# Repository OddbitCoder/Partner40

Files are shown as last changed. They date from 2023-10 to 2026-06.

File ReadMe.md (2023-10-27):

## Board 

| Property | Value |
|--|--|
| Size | 302 mm × 247 mm |
| Thickness | 1.6 mm |
| Track widths | 2.4 mm, 1.4 mm, 0.6 mm, 0.25 mm |
| Pad sizes | See below. |

## Pads 

| Pad Type | Count | Pad Diam | Drill Diam |
|--|--|--|--|
| Via | 1036 | 1.4 mm | 0.8 mm |
| Circular - normal | 2115 | 1.6 mm | 1.0 mm |
| Circular - large | 9 | 2.8 mm | 2.0 mm |
| Square | 445 | 1.6 mm | 1.0 mm |
| Rounded square | 1 | 1.6 mm | 1.0 mm |

## Components 

### Integrated Circuits - E (101)

| ID | Value | Value Ref 1 | Value Ref 2 | Comments |
|--|--|--|--|--|
| E1 | LS123 | SN74LS123N | SN74LS123N |  |
| E2 | LS14 | 74LS14N | SN74LS14N |  |
| E3 | S74 | DM74S74N | DM74S74N |  |
| E4 | S04 | EL74S04 | DM74S04J |  |
| E5 | LS244 | T74LS244B1 | T74LS244B1 |  |
| E6 | LS244 | 74LS244N | T74LS244B1 |  |
| E7 | LS244 | T74LS244B1 | SN74LS244J |  |
| E8 | LS244 | T74LS244B1 | SN74LS244J |  |
| E9 | LS05 | SN74LS05J | SN74LS05N |  |
| E10 | LS30 | T74LS30B1 | T74LS30B1 |  |
| E11 | LS74 | SN74LS74AN | SN74LS74AN |  |
| E12 | LS244 | SN74LS244N | T74LS244B1 |  |
| E13 | LS244 | SN74LS244N | T74LS244B1 |  |
| E14 | LS367 | SN74LS367AN | SN54LS367AJ |  |
| E15 | LS244 | 74LS244N | SN74LS244B1 |  |
| E16 | LS367 | SN54LS367AJ | SN54LS367AJ |  |
| E17 | LS244 | T74LS244B1 | T74LS244B1 |  |
| E18 | LS244 | T74LS244B1 | T74LS244B1 |  |
| E19 | LS244 | 74LS244N | SN74LS244J |  |
| E20 | LS244 | 74LS244N | SN74LS244J |  |
| E21 | LS04 | 74LS04 PC | SN74LS04N |  |
| E22 | LS04 | DM74LS04N | SN74LS04N |  |
| E23 | LS08 | SN74LS08N | SN74LS08N |  |
| E24 | LS08 | SN74LS08N | SN74LS08N |  |
| E25 | 7404 | 7404PC  | SN7404 J |  |
| E26 | LS38 | T74LS38B1 | T74LS38B1 |  |
| E27 | LS38 | T74LS38B1 | T74LS38B1 |  |
| E28 | LS38 | T74LS38B1 | T74LS38B1 |  |
| E29 | LS244 | 74LS244N | T74LS244B1 |  |
| E30 | Z80A SIO/1 | ZILOG Z84??BPS Z80? SIO/1 8338 W | ZILOG Z8881BPS Z80B SIO/1 8449 |  |
| E32 | Z80A CPU | MOSTEK TC8639 MK3880N-4 Z80-CPU | MOSTEK TC8639 MK3880N-4 Z80-CPU |  |
| E33 | Z80A DMA | Z8410AB1 Z80ADMA 28618 | Z8410AB1 Z80ADMA 28548 |  |
| E34 | LS32 | SN74LS32N | SN74LS32N |  |
| E35 | MM58167A | MM58167AN | +B8612 MM58167AN |  |
| E36 | LS04 | DM74LS04N | SN74LS04N |  |
| E37 | LS04 | DM7404N | SN74LS04N |  |
| E38 | LS32 | (SN74LS32...) | SN74LS32N |  |
| E39 | LS244 | 74LS244N | T74LS244B1 |  |
| E40 | LS42 | HD74LS42P | HD74LS42P |  |
| E41 | LS32 | SN74LS32N | SN74LS32N |  |
| E42 | LS14 | 74LS14N | SN74LS14N |  |
| E43 | MC1488 | MC1488P T8444 | MC1488P RQ8326 |  |
| E44 | MC1488 | MC1488P RQ8319 | MC1488P RQ8321 |  |
| E45 | MC1489 | MC1489P K8539 | 406C MC1489A 75189AN |  |
| E46 | LS32 | SN74LS32N | SN74LS32N |  |
| E47 | LS08 | SN74LS08N | SN74LS08N |  |
| E48 | WD1691 | WD1691PE 8348 | WD1691PE-00 8421 02 |  |
| E49 | LS157 | SN74LS157N | SN74LS157N |  |
| E51 | M2716 |  |  | EPROM. |
| E52 | MC1489 | 406C MC1489A 75189AN | 406C MC1989A 75189AN |  |
| E53 | MC1489 | 406C MC1489A 75189AN | 406C MC1989A 75189AN |  |
| E54 | LS32 | SN74LS32N | SN74LS32N |  |
| E55 | LS20 | SN74LS20N | DM74LS20N |  |
| E56 | D765 | 8624KD D765AC-2 | 8350K6 FDC765AC |  |
| E57 | WD2143 | WD2143-PD 03-15 8706 | WD2143M-03 8217 |  |
| E58 | LS123 | SN74LS123N | SN74LS123N |  |
| E59 | M3764A-15 | M3764A-15 65518 | M3764A-15 65516 |  |
| E60 | M3764A-15 | M3764A-15 65518 | M3764A-15 65518 |  |
| E61 | M3764A-15 | M3764A-15 65518 | M3764A-15 65518 |  |
| E62 | M3764A-15 | M3764A-15 65518 | M3764A-15 65518 |  |
| E64 | MC14411 | MC14411 P QR8610 | MC14411 P QR8610 |  |
| E65 | LS374 | 74LS374N | 74LS374N |  |
| E66 | LS244 | 74LS244N | T74LS244B1 |  |
| E67 | Z80A CTC | ZILOG Z8430APE Z80A CTC 8342 | MOSTEK 8502 MK3882N Z80 CTC |  |
| E68 | LS138 | 74LS138PC | SN74LS138N |  |
| E69 | LS138 | SN74LS138N | 74LS138N |  |
| E70 | LS629 | SN74LS629N | SN74LS629N |  |
| E71 | M3764A-15 | M3764A-15 65518 | M3764A-15 65516 |  |
| E72 | M3764A-15 | M3764A-15 65518 | M3764A-15 65518 |  |
| E73 | M3764A-15 | M3764A-15 65518 | M3764A-15 65518 |  |
| E74 | M3764A-15 | M3764A-15 65518 | M3764A-15 65518 |  |
| E77 | LS08 | 74LS08 PC | SN74LS08N |  |
| E78 | LS10 | EL74LS10J | EL74LS10J |  |
| E79 | LS30 | T74LS30B1 | T74LS30B1 |  |
| E80 | LS04 | DM74LS04N | SN74LS04N |  |
| E81 | LS01 | SN74LS01N | SN74LS01N |  |
| E82 | S04 | EL74S04 | DM74S04J |  |
| E83 | LS74 | SN74LS74AN | SN74LS74AN |  |
| E84 | LS08 | 74LS08 PC | SN74LS08N |  |
| E85 | M3764A-15 | M3764A-15 65518 | M3764A-15 65516 |  |
| E86 | M3764A-15 | M3764A-15 65518 | M3764A-15 65518 |  |
| E87 | M3764A-15 | M3764A-15 65518 | M3764A-15 65518 |  |
| E88 | M3764A-15 | M3764A-15 65518 | M3764A-15 65518 |  |
| E91 | LS32 | 74LS32 PC | SN74LS32N |  |
| E92 | LS30 | T74LS30B1 | T74LS30B1 |  |
| E93 | LS30 | T74LS30B1 | T74LS30B1 |  |
| E94 | LS04 | DM74LS04N | SN74LS04N |  |
| E95 | LS132 | 74LS132NB | T74LS132B1 |  |
| E96 | LS393 | DM74LS393N | SN74LS393N |  |
| E97 | LS157 | SN74LS157N | SN74LS157N |  |
| E98 | M3764A-15 | M3764A-15 65518 | M3764A-15 65516 |  |
| E99 | M3764A-15 | M3764A-15 65518 | M3764A-15 65516 |  |
| E100 | M3764A-15 | M3764A-15 65518 | M3764A-15 65518 |  |
| E101 | M3764A-15 | M3764A-15 65518 | M3764A-15 65518 |  |
| E102 | LS86 | SN74LS86N | T74LS86B1 |  |
| E103 | LS74 | SN74LS74AN | SN74LS74AN |  |
| E104 | LS74 | SN74LS74AN | SN74LS74AN |  |
| E105 | LS27 | T74LS27B1 | T74LS27B1 |  |
| E106 | LS74 | SN74LS74AN | SN74LS74AN |  |
| E107 | LS74 | SN74LS74AN | SN74LS74AN |  |
| E108 | LS08 | 74LS08 PC | SN74LS08N |  |

### Resistors - R (81)

| ID | Value | Value Ref 1 | Comments |
|--|--|--|--|
| R1 | 3.3kΩ | 3.3 kΩ ±5% |  |
| R2 | 1kΩ | 1 kΩ ±5% |  |
| R3 | 1kΩ | 1 kΩ ±5% |  |
| R4 | 1kΩ | 1 kΩ ±5% |  |
| R5 | 1kΩ | 1 kΩ ±5% |  |
| R7 | 1kΩ | 1 kΩ ±5% |  |
| R9 | 1kΩ | 1 kΩ ±5% |  |
| R10 | 150Ω | 150 Ω ±5% |  |
| R11 | 220Ω | 220 Ω ±5% |  |
| R12 | 3.3kΩ | 3.3 kΩ ±5% |  |
| R13 | 3.3kΩ | 3.3 kΩ ±5% |  |
| R14 | 10kΩ | 10 kΩ ±5% |  |
| R15 | 1kΩ | 1 kΩ ±5% |  |
| R16 | 56Ω | 56 Ω ±5% |  |
| R17 | 820Ω | 920 Ω ±5% / 820 Ω ±5% |  |
| R18 | 1kΩ | 1 kΩ ±5% |  |
| R19 | 10kΩ | 10 kΩ ±5% |  |
| R20 | 820Ω | 920 Ω ±5% / 820 Ω ±5% |  |
| R21 | 20kΩ | 20 kΩ ±5% |  |
| R22 | 3.3kΩ | 3.3 kΩ ±5% |  |
| R23  | 3.3kΩ | 3.3 kΩ ±5% |  |
| R26 | 1.5kΩ | 1.5 kΩ ±5% |  |
| R36 | 3.3kΩ | 3.3 kΩ ±5% |  |
| R37 | 150Ω | 150 Ω ±5% |  |
| R38 | 150Ω | 150 Ω ±5% |  |
| R39 | 150Ω | 150 Ω ±5% |  |
| R40 | 150Ω | 150 Ω ±5% |  |
| R41 | 150Ω | 150 Ω ±5% |  |
| R42 | 150Ω | 150 Ω ±5% |  |
| R43 | 33Ω | 33 Ω ±5% |  |
| R44 | 33Ω | 33 Ω ±5% |  |
| R45 | 33Ω | 33 Ω ±5% |  |
| R46 | 33Ω | 33 Ω ±5% |  |
| R47 | 33Ω | 33 Ω ±5% |  |
| R48 | 33Ω | 33 Ω ±5% |  |
| R49 | 33Ω | 33 Ω ±5% |  |
| R50 | 33Ω | 33 Ω ±5% |  |
| R51 | 33Ω | 33 Ω ±5% |  |
| R52 | 33Ω | 33 Ω ±5% |  |
| R53 | 5.1kΩ | 5K1 ±5% |  |
| R54 | 3.3kΩ | 3.3 kΩ ±5% |  |
| R55 | 3.3kΩ | 3.3 kΩ ±5% |  |
| R58 | 3.3kΩ | 3.3 kΩ ±5% |  |
| R59 | 3.3kΩ | 3.3 kΩ ±5% |  |
| R60 | 1kΩ | 1 kΩ ±5% |  |
| R61 | 1kΩ | 1 kΩ ±5% |  |
| R62 | 1kΩ | 1 kΩ ±5% |  |
| R63 | 1kΩ | 1 kΩ ±5% |  |
| R64 | 1kΩ | 1 kΩ ±5% |  |
| R65 | 1kΩ | 1 kΩ ±5% |  |
| R66 | 1kΩ | 1 kΩ ±5% |  |
| R67 | 1kΩ | 1 kΩ ±5% |  |
| R68 | 4.7kΩ | 4.7 kΩ ±5% |  |
| R69 | 4.7kΩ | 4.7 kΩ ±5% |  |
| R70 | 1kΩ | 1 kΩ ±5% |  |
| R71 | 1kΩ | 1 kΩ ±5% |  |
| R72 | 1kΩ | 1 kΩ ±5% |  |
| R73 | 1kΩ | 1 kΩ ±5% |  |
| R74 | 1kΩ | 1 kΩ ±5% |  |
| R75 | 1kΩ | 1 kΩ ±5% |  |
| R76 | 1kΩ | 1 kΩ ±5% |  |
| R77 | 1kΩ | 1 kΩ ±5% |  |
| R78 | 4.7kΩ | 4.7 kΩ ±5% |  |
| R79 | 4.7kΩ | 4.7 kΩ ±5% |  |
| R80 | 4.7kΩ | 4.7 kΩ ±5% |  |
| R82 | 1kΩ | 1 kΩ ±5% |  |
| R83 | 4.7kΩ | 4.7 kΩ ±5% |  |
| R84 | 47Ω | 47 Ω ±5% |  |
| R85 | 1kΩ | 1 kΩ ±5% |  |
| R86 | 4.7kΩ | 4.7 kΩ ±5% |  |
| R87 | 47kΩ | 47 kΩ ±5% |  |
| R88 | 47kΩ | 47 kΩ ±5% |  |
| R89 | 68Ω | 68 Ω ±5% |  |
| R90 | 10kΩ | 10 kΩ ±5% |  |
| R92 | 50kΩ |  | Trimmer Bourns 3296Y. Taken from the donor board ("Ref 3") for measurements. |
| R93 | 50kΩ |  | Trimmer Bourns 3296Y. Taken from the donor board ("Ref 3") for measurements. |
| R94 | 10kΩ |  | Trimmer Bourns 3296Y. Taken from the donor board ("Ref 3") for measurements. |
| R91 | 4.7kΩ | 4.7 kΩ ±5% |  |
| R95 | 10kΩ | 10 kΩ ±5% |  |
| R200 | Z 2.7V | BZX 2,7 | Zener diode. We used Vishay's TZX2V7C-TR diode. |
| R201 | 560Ω | 560 Ω ±5% |  |
| R202 | 15MΩ | 15 MΩ | Blue-colored body resistor (1% or 2% tolerance). We used a 1/4W resistor with a tolerance of ±1%. |
| R203 | 390Ω | 390 Ω ±5% |  |
| R204 | 330Ω | 330 Ω ±5% |  | 

Unless noted otherwise in the comments, we used 1/4 W resistors with a tolerance of ±5%.

### Capacitors - C (59)

| ID | Value | Value Ref 1 | Value Ref 2 | Size Ref 2 | Comments |
|--|--|--|--|--|--|
| C1 | 100μF | 100 uF 40 V | 100 uF 40 V | 9 mm | Radial electrolytic capacitor (50V 100μF 10%). |
| C2 | 100μF | 100 uF 40 V | 100 uF 40 V | 9 mm | Radial electrolytic capacitor (50V 100μF 10%). |
| C3 | 100μF | 100 uF 40 V | 100 uF 40 V | 9 mm | Radial electrolytic capacitor (50V 100μF 10%). |
| C4 | 100μF | 100 uF 40 V | 100 uF 40 V | 9 mm | Radial electrolytic capacitor (50V 100μF 10%). |
| C5 | 1nF | 1n0 | 1n0 | 5 mm |  |
| C6 | 1nF | 1n0 | 1n0S (400V?) | 12 mm |  |
| C7 | 2.2nF | 2n2 | 2n2 | 8 mm |  |
| C8 | 68μF | 68uF 25V | 68uF 25V | 7 mm | Radial electrolytic capacitor (50V 68μF 10%). |
| C17 | 68pF | 68p | 68p | 5 mm |  |
| C18 | 82pF | 82p | 82p | 7 mm |  |
| C20 | 68μF | 68 uF 25 V | 68 uF 25 V | 7 mm | Radial electrolytic capacitor (50V 68μF 10%). |
| C21 | 20pF | 22 pF | 22J | 5 mm |  |
| C22 | 20pF | 22 pF | 22J | 5 mm |  |
| C102 | 2.2nF | 2n2 | 2n2 | 7 mm |  |
| C103 | 390pF (391) | 380K Y5P / 390K Y5P | 380/390K | 5 mm |  |
| C110 | 390pF (391) | 390K Y5P | 380/390K | 5 mm |  |
| C300 | 330pF (331) | 330 | 330 | 5 mm |  |
| C301 | 680nF | 684 100V | 684 50V | 9 mm | We used a multilayer ceramic capacitor (50V 0.68μF ±10%). It is physically/visually too small though (a higher voltage rating would probably look better). |
| CX (41) | 0.1μF (104) | 104 50V | 104 50V | 5 mm | We used multilayer ceramic capacitors (50V 0.1μF ±5%). There are 41 CXs on the board. | 

Unless specified otherwise in the comments, we used 1 kW ceramic disc capacitors. We chose this power rating because the physical sizes roughly match those of the original capacitors.

### Other Components 

| ID | Value | Value Schema | Value Ref 1 | Comments |
|--|--|--|--|--|
| BAT | 3.6V | 3V | VARTA SafeTronic 3.6 V | We used a 3.6 V 80 mAh Ni-Mh battery. |
| V1 | LED | LED |  | Specs? |
| V2 | BA513 | 1N914 | BA 513 | We used a 1N914 diode. The original "Ref 1" board has a BA513 (1N4448) diode. |
| V3 | BA513 | 1N4148 | BA 513 | We used a 1N4148 diode. The original "Ref 1" board has a BA513 (1N4448) diode. |
| V4 | BA513 | 1N4148 | BA 513 | We used a 1N4148 diode. The original "Ref 1" board has a BA513 (1N4448) diode. |
| Y1 | 8MHz | 8MHZ | 8.000 SUNNY 2779 | Specs? |
| Y2 | 32.768kHz | 32.768KHZ | QRT-38 I | Specs? |
| Y3 | 1.8432MHz | 1.8432MHZ | 1843 20 kHZ 11034 | Specs? |
| X10 | Power connector | / | / |  |
| J1 | Pin header 2×17 | / | / |  |
| J2 | Pin header 2×32 | / | / |  |
| J3 | Pin header 1×3 | / | / |  |
| J5 | Pin header 1×5 | / | / |  |
| J6 | Pin header 2×20 | / | / |  |
| J7 | Pin header 2×13 | / | / |  |
| J8 | Pin header 2×13 | / | / |  |
| J9 | Pin header 2×13 | / | / |  |
| JJ2 | Jumper 1×2 | / | / |  |
| JJ7 | Jumper 1×2 | / | / |  |
| JJ8 | Pin header 1×4 + Pin header 1×14 | / | / |  |
| JJ9 | Jumper 2×2 | / | / |  |
| JJ10 | Jumper 1×2 | / | / |  |
| JJ50 | Jumper 2×2 | / | / |  |

The original jumpers and pin headers have a termination post length of just over 3 mm and a mating post length of just below 7 mm.

## Shopping List

| Item / List | Desc | Service | Link | Price |
|--|--|--|--|--|
| Circuit board | / | PCBWay | TODO | 35.84 USD* |
| Mouser Project: Partner - E | Integrated circuits (74/101) | Mouser | https://www.mouser.com/ProjectManager/ProjectDetail.aspx?AccessID=249dc903ed | 118.95 € |
| Mouser Project: Partner - R | Resistors (81/81) | Mouser | https://www.mouser.com/ProjectManager/ProjectDetail.aspx?AccessID=5393aec102 | 12.20 € |
| Mouser Project: Partner - C | Capacitors (59/59) | Mouser | https://www.mouser.com/ProjectManager/ProjectDetail.aspx?AccessID=89c7b43e3d | 32.97 € |
| Mouser Project: Partner - V | Diodes (3/4) | Mouser | https://www.mouser.com/ProjectManager/ProjectDetail.aspx?AccessID=1df4c5cce4 | 0.47 € |
| Mouser Project: Partner - Sockets | IC sockets with turned pin contacts (101/101) | Mouser | https://www.mouser.com/ProjectManager/ProjectDetail.aspx?AccessID=c9cba6a4d2 | 103.18 € |
| Mouser Project: Partner - J+JJ | Jumpers & pin headers (14/14**) | Mouser | https://www.mouser.com/ProjectManager/ProjectDetail.aspx?AccessID=dc5819c5d5 | 50.92 € |
| 74LS01 | IC (E81) | Lotos | https://www.lotos.si/sl-SI/shop/item/2883000000106 | 0.69 € |
| Battery | 3.6 V 80 mAh Ni-Mh (BAT) | Delko | https://www.delko.si/sl/industrijska-36v-80-mah-ni-mh-polnilna-gp-baterija.html | 4.55 € |
| **Total** |  |  |  | **~365 €** |

\*The minimum order at PCBWay is 5 boards. The price shown here is for 1 board.

\*\*One of the jumpers (JJ8) is made of two pin headers. It is thus actually 15 J and JJ components altogether.

The following components are not on these lists and you will need to find them elsewhere (e.g., eBay):

| ID | Value | Our Source |
|--|--|--|
| E59-E62, E71-E74, E85-E88, E98-E101 (16) | M3764A-15 | eBay |
| E51 | M2716 | eBay |
| E56 | D765 | eBay |
| E64 | MC14411 | eBay |
| E35 | MM58167A | eBay |
| E48 | WD1691 | Donor board |
| E57 | WD2143 | eBay |
| E67 | Z80A CTC | Donor board |
| E33 | Z80A DMA | Community |
| E30 | Z80A SIO/1 | Community |
| E32 | Z80A CPU | Donor board |
| V1 | LED diode | Donor board |
| Y1 | Crystal 8 MHz | Donor board | 
| Y2 | Crystal 32.768 kHz | Donor board |
| Y3 | Crystal 1.8432 MHz | Donor board |
| X10 | Power connector | Donor board |

## Assembly

The following figure shows the board's layout and helps you understand where each component should be placed and how it should be oriented. There is also a [PDF version](./gfx/idp-pcb-layout.pdf).

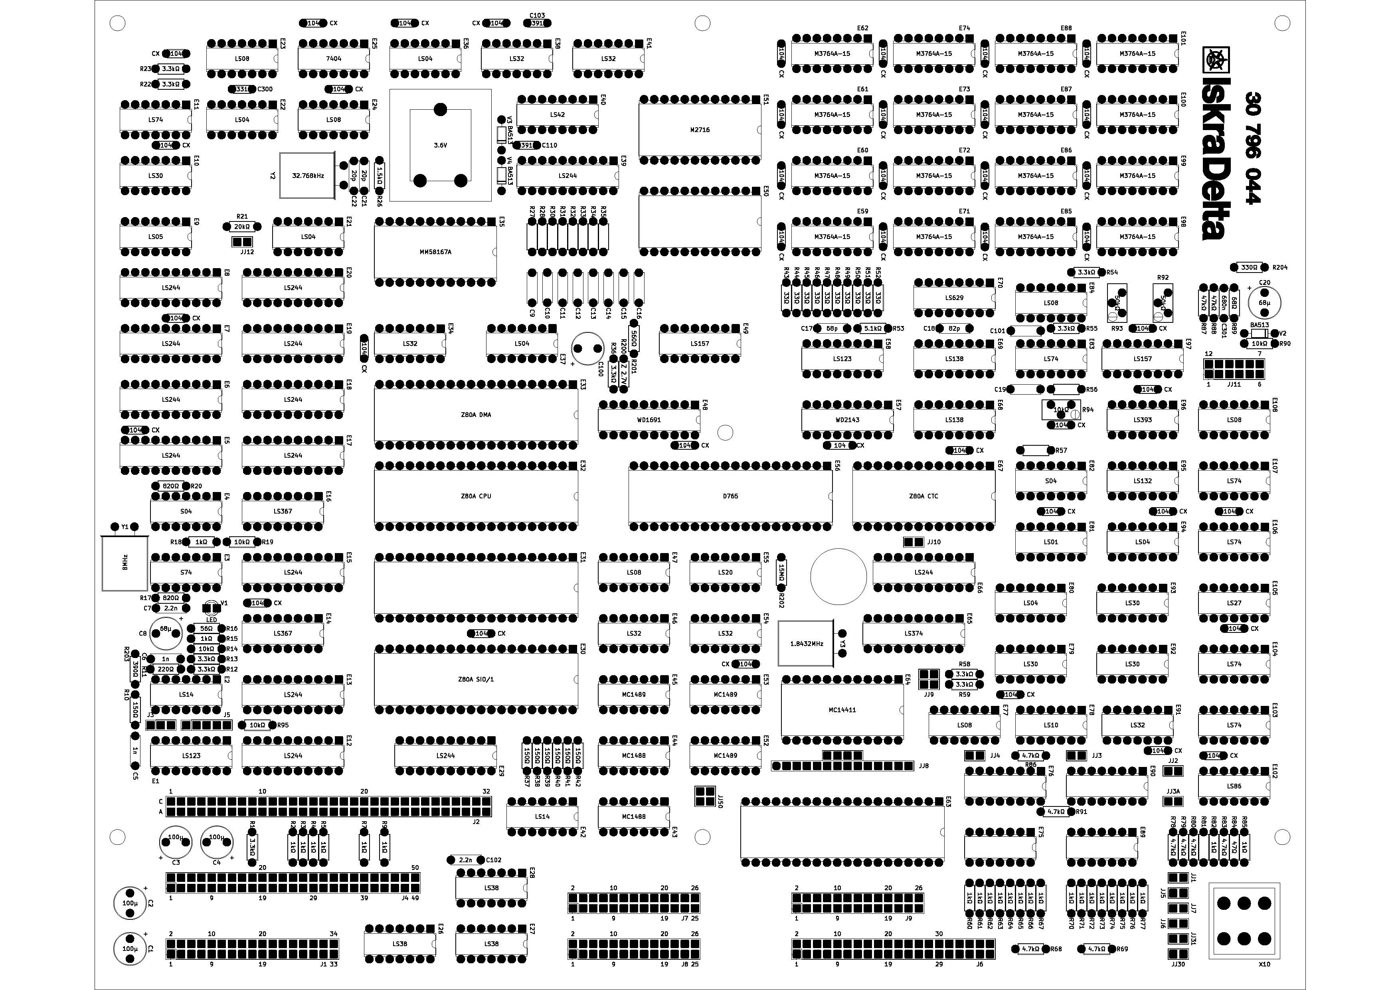
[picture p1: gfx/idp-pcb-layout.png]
Board layout.


### Power Connector (X10)

Front side of the board:
```
          (R78-R85)

 (JJ1)   12V  5V  5V
 (JJ5)    o   o   o
 (JJ7)
 (JJ6)  -12V GND GND
(JJ31)    o   o   o
(JJ30)
```

## Board Settings

### Trimmers R92, R93, R94

The following are the exact resistance measurements between the three pins of the trimmers. These trimmers were taken from the donor board ("Ref 3"). 

R92, bottom view:
```
    o     o
16kΩ \   / 35kΩ
       o
```

R93, bottom view:
```
   o     o
9kΩ \   / 43kΩ
      o
```

R94, bottom view:
```
     o     o
2.2kΩ \   / 8.2kΩ
        o
```

### Jumpers 

JJ8, top view:

```
┌───────────────┐
│         o o─o─o 
│         └─────┐
o o o o o o o o o o o o o o
```

JJ9, top view:

```
       o o  (R58,R59)
(E64)  o─o
```

JJ50, top view:

```
       o─o  (JJ8)
(E43)  o─o
```

## Board Initialization

TODO

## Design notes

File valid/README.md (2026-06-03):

# Network Scripts

Scripts for parsing the Partner 40 schematic netlist and injecting nets into the KiCad PCB.

## Files

- `sch.txt` — hand-transcribed schematic netlist (source of truth)
- `nets.txt` — parsed netlist (generated, do not edit)
- `idp.net` — KiCad-format netlist for import (generated, do not edit)

## Workflow

### 1. Parse the schematic

Run from the `valid/` directory:

```
python parse_nets.py
```

Reads `sch.txt`, resolves synonyms and BANK expansions, writes `nets.txt`.

### 2. Generate the KiCad netlist

```
python gen_netlist.py
```

Reads `nets.txt`, applies pin swaps for specified CX capacitors, writes `idp.net`.

### 3. Import netlist into KiCad

In KiCad PCB editor: **File → Import → Netlist**, select `idp.net`.

This assigns nets to all footprint pads.

### 4. Propagate nets to traces and vias

In KiCad's scripting console (**Tools → Scripting Console**):

```python
exec(open(r"C:\Work\partner40\valid\propagate_nets.py").read())
```

This walks the physical connectivity from pads through connected tracks and vias,
assigning the correct net to each. Saves the PCB automatically.

### 5. Mark unconnected pads

In KiCad's scripting console:

```python
exec(open(r"C:\Work\partner40\valid\unconnected_pads.py").read())
```

Finds pads with no tracks connected. Assigns unique `unconnected-(REF-PadN)` nets to pads
with no net, and lists pads that have a net assigned but no physical trace.

## sch.txt Format

- `E4/3 M1I- E3/11` — component/pin pairs and net names on the same line belong to the same net
- `<E67>` — sets default component context; subsequent bare pin numbers (e.g. `5`) refer to `E67/5`
- `<>` — resets component context
- `-- LIST2` — section comment, ignored
- Multiple net names on one line (e.g. `DABUS11 DD1+`) are treated as synonyms for the same net
- `BANK1/5` expands to pin 5 of E59, E60, E61, E62, E71, E72, E73, E74
- `BANK2/5` expands to pin 5 of E85, E86, E87, E88, E98, E99, E100, E101

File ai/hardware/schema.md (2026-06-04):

# Partner 40 Schema

For each component and pin, lists all connected component/pins (same net).
Power nets (GND, 5V, 12V, -12V) are listed in the Power Nets chapter; component entries show only the net name for those pins.

## Power Nets

**-12V**: C3/2, E43/1, E44/1, J2/5, J2/6, X10/4

**12V**: C4/1, E43/14, E44/14, J2/11, J2/12, R94/1, X10/1

**5V**: C1/1, C2/1, C100/1, C110/1, CX1/1, CX2/1, CX3/1, CX4/1, CX5/1, CX6/1, CX7/1, CX8/1, CX9/1, CX10/1, CX11/1, CX12/1, CX13/1, CX14/2, CX15/2, CX16/2, CX17/2, CX18/1, CX19/1, CX20/1, CX21/1, CX22/1, CX23/1, CX24/2, CX25/2, CX26/2, CX27/2, CX28/2, CX29/1, CX31/1, CX32/1, CX33/1, CX34/1, CX35/2, CX36/2, CX37/1, CX38/1, CX39/1, CX40/1, CX41/1, E1/16, E2/14, E3/14, E4/14, E5/20, E6/20, E7/20, E8/20, E9/14, E10/12, E10/14, E10/5, E11/14, E12/20, E13/20, E14/16, E15/20, E16/16, E17/20, E18/20, E19/20, E20/20, E21/14, E22/14, E23/14, E24/14, E25/14, E26/14, E27/14, E28/14, E29/20, E30/9, E31/9, E32/11, E33/11, E34/14, E36/14, E37/14, E38/14, E39/20, E40/16, E41/14, E42/14, E43/10, E43/13, E43/5, E44/10, E44/13, E45/14, E46/14, E47/14, E48/20, E49/16, E50/21, E50/24, E51/21, E51/24, E52/14, E54/14, E55/14, E56/40, E57/18, E58/11, E58/16, E59/8, E60/8, E61/8, E62/8, E63/26, E64/24, E65/20, E66/20, E67/13, E67/24, E68/16, E69/16, E70/15, E70/16, E70/6, E71/8, E72/8, E73/8, E74/8, E75/14, E76/16, E77/14, E78/14, E79/14, E80/14, E81/14, E82/14, E83/1, E83/14, E83/4, E84/14, E85/8, E86/8, E87/8, E88/8, E89/14, E90/16, E91/14, E92/14, E93/14, E94/14, E95/14, E96/14, E97/16, E98/8, E99/8, E100/8, E101/8, E102/14, E103/10, E103/14, E103/4, E104/1, E104/13, E104/14, E105/14, E106/10, E106/14, E106/2, E106/4, E107/1, E107/11, E107/12, E107/14, E108/14, J2/10, J2/7, J2/8, J2/9, R1/1, R2/1, R3/1, R4/1, R5/1, R7/1, R9/1, R10/2, R12/2, R13/2, R14/1, R15/1, R18/1, R19/2, R21/2, R22/1, R23/1, R36/2, R37/2, R38/2, R39/2, R40/2, R41/2, R42/2, R53/1, R54/1, R55/1, R58/1, R59/1, R60/1, R61/1, R62/1, R63/1, R64/1, R65/1, R66/1, R67/1, R68/1, R69/1, R70/1, R71/1, R72/1, R73/1, R74/1, R75/1, R76/1, R77/1, R78/1, R79/1, R80/1, R82/1, R83/1, R85/1, R86/1, R90/1, R91/2, R92/1, R92/2, R93/1, R95/2, R200/2, R203/1, R204/1, V1/2, V2/1, V3/2, X10/2, X10/3

**GND**: BAT/1, C1/2, C2/2, C3/1, C4/2, C6/2, C8/2, C19/2, C20/2, C21/1, C22/2, C100/2, C101/2, C102/2, C103/1, CX1/2, CX2/2, CX3/2, CX4/2, CX5/2, CX6/2, CX7/2, CX8/2, CX9/2, CX10/2, CX11/2, CX12/2, CX13/2, CX14/1, CX15/1, CX16/1, CX17/1, CX18/2, CX19/2, CX20/2, CX21/2, CX22/2, CX23/2, CX24/1, CX25/1, CX26/1, CX27/1, CX28/1, CX29/2, CX30/2, CX31/2, CX32/2, CX33/2, CX34/2, CX35/1, CX36/1, CX37/2, CX38/2, CX39/2, CX40/2, E1/1, E1/8, E2/7, E3/7, E4/7, E5/10, E6/10, E7/1, E7/10, E7/19, E8/10, E9/7, E10/7, E11/7, E12/10, E13/10, E14/1, E14/8, E15/10, E15/19, E16/1, E16/8, E17/10, E18/10, E19/1, E19/10, E19/19, E20/10, E21/7, E22/7, E23/7, E24/7, E25/7, E26/7, E27/7, E28/7, E29/10, E30/31, E31/31, E32/29, E33/30, E34/7, E35/12, E36/7, E37/7, E38/7, E39/10, E40/8, E41/7, E42/7, E43/7, E44/7, E45/7, E46/7, E47/7, E48/10, E49/15, E49/8, E50/12, E51/12, E52/7, E53/7, E54/7, E55/7, E56/20, E57/9, E58/8, E58/9, E59/16, E60/16, E61/16, E62/16, E63/11, E64/12, E65/10, E66/1, E66/10, E66/19, E67/5, E68/8, E69/8, E70/11, E70/2, E70/3, E70/8, E70/9, E71/16, E72/16, E73/16, E74/16, E75/7, E76/8, E77/7, E78/7, E79/7, E80/7, E81/7, E82/7, E83/7, E84/7, E85/16, E86/16, E87/16, E88/16, E89/7, E90/8, E91/7, E92/7, E93/7, E94/7, E95/7, E96/2, E96/7, E97/15, E97/8, E98/16, E99/16, E100/16, E101/16, E102/7, E103/7, E104/7, E105/7, E106/7, E107/2, E107/7, E108/7, J1/1, J1/11, J1/13, J1/15, J1/17, J1/19, J1/21, J1/23, J1/25, J1/27, J1/29, J1/3, J1/31, J1/33, J1/5, J1/7, J1/9, J2/1, J2/2, J2/3, J2/4, J3/1, J4/1, J4/11, J4/13, J4/15, J4/17, J4/19, J4/21, J4/23, J4/25, J4/27, J4/29, J4/3, J4/31, J4/33, J4/35, J4/37, J4/39, J4/41, J4/43, J4/45, J4/47, J4/49, J4/5, J4/7, J4/9, J5/1, J5/4, J6/1, J6/11, J6/13, J6/15, J6/17, J6/19, J6/21, J6/23, J6/25, J6/27, J6/29, J6/3, J6/31, J6/33, J6/35, J6/37, J6/39, J6/5, J6/7, J6/9, J7/1, J7/13, J8/1, J8/13, J9/1, J9/13, JJ1/1, JJ2/2, JJ3A/2, JJ5/1, JJ6/1, JJ7/1, JJ9/3, JJ9/4, JJ30/1, JJ31/1, JJ50/1, JJ50/3, R27/2, R28/2, R30/2, R31/2, R32/2, R33/2, R34/2, R35/2, R87/1, R89/2, R93/3, R94/3, R201/2, X10/5, X10/6

## Decoupling capacitors

CX1, CX2, CX3, CX4, CX5, CX6, CX7, CX8, CX9, CX10, CX11, CX12, CX13, CX14, CX15, CX16, CX17, CX18, CX19, CX20, CX21, CX22, CX23, CX24, CX25, CX26, CX27, CX28, CX29, CX31, CX32, CX33, CX34, CX35, CX36, CX37, CX38, CX39, CX40 — all connect to 5V and GND.

## BAT

| Pin | Net | Connected to |
|--|--|--|
| 1 | GND | *(see Power Nets)* |
| 2 | _NET_196 | BAT/3, R26/2, V4/2 |
| 3 | _NET_196 | BAT/2, R26/2, V4/2 |

## C1

| Pin | Net | Connected to |
|--|--|--|
| 1 | 5V | *(see Power Nets)* |
| 2 | GND | *(see Power Nets)* |

## C2

| Pin | Net | Connected to |
|--|--|--|
| 1 | 5V | *(see Power Nets)* |
| 2 | GND | *(see Power Nets)* |

## C3

| Pin | Net | Connected to |
|--|--|--|
| 1 | GND | *(see Power Nets)* |
| 2 | -12V | *(see Power Nets)* |

## C4

| Pin | Net | Connected to |
|--|--|--|
| 1 | 12V | *(see Power Nets)* |
| 2 | GND | *(see Power Nets)* |

## C5

| Pin | Net | Connected to |
|--|--|--|
| 1 | _NET_36 | E1/14 |
| 2 | _NET_37 | E1/15, R95/1 |

## C6

| Pin | Net | Connected to |
|--|--|--|
| 1 | _NET_3 | C8/1, E2/1, R11/1, R14/2 |
| 2 | GND | *(see Power Nets)* |

## C7

| Pin | Net | Connected to |
|--|--|--|
| 1 | _NET_41 | E4/13, R17/1 |
| 2 | _NET_42 | E4/10, R20/1 |

## C8

| Pin | Net | Connected to |
|--|--|--|
| 1 | _NET_3 | C6/1, E2/1, R11/1, R14/2 |
| 2 | GND | *(see Power Nets)* |

## C9

| Pin | Net | Connected to |
|--|--|--|
| 1 | DABUS7 | E12/12, E29/17, E30/4, E31/4, E32/13, E33/27, E35/22, E39/12, E50/17, E51/17, E56/13, E63/2, E65/12, E65/13, E66/11, E67/4, E73/2, E100/2 |
| 2 | _NET_280 | R27/1 |

## C10

| Pin | Net | Connected to |
|--|--|--|
| 1 | DABUS6 | E12/9, E29/2, E30/37, E31/37, E32/10, E33/28, E35/21, E39/9, E50/16, E51/16, E56/12, E60/2, E63/3, E65/18, E65/19, E66/17, E67/3, E86/2 |
| 2 | _NET_281 | R28/1 |

## C11

| Pin | Net | Connected to |
|--|--|--|
| 1 | _NET_282 | R30/1 |
| 2 | D0 | E12/3, E14/13, E29/8, E30/40, E31/40, E32/14, E33/35, E35/15, E39/14, E50/9, E51/9, E56/6, E61/2, E63/19, E65/8, E65/9, E66/8, E67/25, E87/2 |

## C12

| Pin | Net | Connected to |
|--|--|--|
| 1 | _NET_283 | R32/1 |
| 2 | DABUS1 | E12/18, E29/11, E30/1, E31/1, E32/15, E33/34, E35/16, E39/16, E50/10, E51/10, E56/7, E63/20, E65/4, E65/5, E66/4, E67/26, E74/2, E101/2 |

## C13

| Pin | Net | Connected to |
|--|--|--|
| 1 | _NET_284 | R34/1 |
| 2 | DABUS2 | E12/5, E29/6, E30/39, E31/39, E32/12, E33/33, E35/17, E39/18, E50/11, E51/11, E56/8, E62/2, E63/1, E65/2, E65/3, E66/2, E67/27, E88/2 |

## C14

| Pin | Net | Connected to |
|--|--|--|
| 1 | _NET_285 | R35/1 |
| 2 | DABUS4 | E12/7, E29/4, E30/38, E31/38, E32/7, E33/31, E35/19, E39/5, E50/14, E51/14, E56/10, E59/2, E63/39, E65/14, E65/15, E66/13, E67/1, E85/2 |

## C15

| Pin | Net | Connected to |
|--|--|--|
| 1 | DABUS5 | E12/14, E29/15, E30/3, E31/3, E32/9, E33/29, E35/20, E39/7, E50/15, E51/15, E56/11, E63/38, E65/6, E65/7, E66/6, E67/2, E72/2, E99/2 |
| 2 | _NET_286 | R31/1 |

## C16

| Pin | Net | Connected to |
|--|--|--|
| 1 | DABUS3 | E12/16, E29/13, E30/2, E31/2, E32/8, E33/32, E35/18, E39/3, E50/13, E51/13, E56/9, E63/40, E65/16, E65/17, E66/15, E67/28, E71/2, E98/2 |
| 2 | _NET_287 | R33/1 |

## C17

| Pin | Net | Connected to |
|--|--|--|
| 1 | _NET_272 | E58/6 |
| 2 | _NET_273 | E58/7, R53/2 |

## C18

| Pin | Net | Connected to |
|--|--|--|
| 1 | _NET_268 | E70/13 |
| 2 | _NET_267 | E70/12 |

## C19

| Pin | Net | Connected to |
|--|--|--|
| 1 |  |  |
| 2 | GND | *(see Power Nets)* |

## C20

| Pin | Net | Connected to |
|--|--|--|
| 1 | _NET_39 | E95/2, R90/2, V2/2 |
| 2 | GND | *(see Power Nets)* |

## C21

| Pin | Net | Connected to |
|--|--|--|
| 1 | GND | *(see Power Nets)* |
| 2 | _NET_193 | E35/11, Y2/1 |

## C22

| Pin | Net | Connected to |
|--|--|--|
| 1 | _NET_192 | E35/10, Y2/2 |
| 2 | GND | *(see Power Nets)* |

## C100

| Pin | Net | Connected to |
|--|--|--|
| 1 | 5V | *(see Power Nets)* |
| 2 | GND | *(see Power Nets)* |

## C101

| Pin | Net | Connected to |
|--|--|--|
| 1 | _NET_288 | E22/8 |
| 2 | GND | *(see Power Nets)* |

## C102

| Pin | Net | Connected to |
|--|--|--|
| 1 | DISK0- | E28/6, J1/10, J4/26 |
| 2 | GND | *(see Power Nets)* |

## C103

| Pin | Net | Connected to |
|--|--|--|
| 1 | GND | *(see Power Nets)* |
| 2 | BANK1- | E24/3, E38/4 |

## C110

| Pin | Net | Connected to |
|--|--|--|
| 1 | 5V | *(see Power Nets)* |
| 2 | _NET_46 | E24/11, E37/11 |

## C300

| Pin | Net | Connected to |
|--|--|--|
| 1 | _NET_50 | E15/9, E22/1 |
| 2 | _NET_49 | E22/2, E22/3 |

## C301

| Pin | Net | Connected to |
|--|--|--|
| 1 | _NET_275 | R89/1 |
| 2 | _NET_251 | E48/13, E48/14, E70/1, R87/2, R88/1 |

## CX30

| Pin | Net | Connected to |
|--|--|--|
| 1 | _NET_271 | E57/17, R94/2 |
| 2 | GND | *(see Power Nets)* |

## CX41

| Pin | Net | Connected to |
|--|--|--|
| 1 | 5V | *(see Power Nets)* |
| 2 | unconnected-GND |  |

## E1

| Pin | Net | Connected to |
|--|--|--|
| 1 | GND | *(see Power Nets)* |
| 2 | _NET_35 | E3/9 |
| 3 | _NET_44 | E3/10, E3/12, R15/2 |
| 4 | _NET_38 | E95/1 |
| 5 | unconnected-(E1-Pad5) |  |
| 6 | unconnected-(E1-Pad6) |  |
| 7 | unconnected-(E1-Pad7) |  |
| 8 | GND | *(see Power Nets)* |
| 9 | unconnected-(E1-Pad9) |  |
| 10 | unconnected-(E1-Pad10) |  |
| 11 | unconnected-(E1-Pad11) |  |
| 12 | unconnected-(E1-Pad12) |  |
| 13 | unconnected-(E1-Pad13) |  |
| 14 | _NET_36 | C5/1 |
| 15 | _NET_37 | C5/2, R95/1 |
| 16 | 5V | *(see Power Nets)* |

## E2

| Pin | Net | Connected to |
|--|--|--|
| 1 | _NET_3 | C6/1, C8/1, R11/1, R14/2 |
| 2 | _NET_2 | E3/13 |
| 3 | MREQB- | E13/18, E16/13, E36/13, E41/4, J2/25 |
| 4 | unconnected-MREQI+ |  |
| 5 | unconnected-(E2-Pad5) |  |
| 6 | unconnected-(E2-Pad6) |  |
| 7 | GND | *(see Power Nets)* |
| 8 | _NET_254 | E49/5 |
| 9 | _NET_270 | R10/1 |
| 10 | _NET_91 | E30/12 |
| 11 | _NET_93 | E2/12 |
| 12 | _NET_93 | E2/11 |
| 13 | RXD1 | J5/2 |
| 14 | 5V | *(see Power Nets)* |

## E3

| Pin | Net | Connected to |
|--|--|--|
| 1 | _NET_33 | E3/4, R18/2 |
| 2 | _NET_32 | E3/6, E16/10, E32/6, R203/2 |
| 3 | _NET_34 | E4/2 |
| 4 | _NET_33 | E3/1, R18/2 |
| 5 | unconnected-(E3-Pad5) |  |
| 6 | _NET_32 | E3/2, E16/10, E32/6, R203/2 |
| 7 | GND | *(see Power Nets)* |
| 8 | unconnected-(E3-Pad8) |  |
| 9 | _NET_35 | E1/2 |
| 10 | _NET_44 | E1/3, E3/12, R15/2 |
| 11 | _NET_1 | E4/4 |
| 12 | _NET_44 | E1/3, E3/10, R15/2 |
| 13 | _NET_2 | E2/2 |
| 14 | 5V | *(see Power Nets)* |

## E4

| Pin | Net | Connected to |
|--|--|--|
| 1 | CLCK | E4/8, E83/11, E83/3, JJ11/2 |
| 2 | _NET_34 | E3/3 |
| 3 | M1B- | E16/3, E24/13, E30/8, E31/8, E33/26, E63/37, E67/14, E91/1, E105/4, J2/24 |
| 4 | _NET_1 | E3/11 |
| 5 | RESET+ | E56/1, E91/13, E95/3 |
| 6 | RESET- | E11/4, E24/10, E30/21, E31/21, E32/26, E64/10, E67/17, E77/1, E77/13, E103/1, E103/13, E104/10, E104/4, J2/21 |
| 7 | GND | *(see Power Nets)* |
| 8 | CLCK | E4/1, E83/11, E83/3, JJ11/2 |
| 9 | _NET_40 | E4/12, R17/2, Y1/1 |
| 10 | _NET_42 | C7/2, R20/1 |
| 11 | _NET_43 | R20/2, Y1/2 |
| 12 | _NET_40 | E4/9, R17/2, Y1/1 |
| 13 | _NET_41 | C7/1, R17/1 |
| 14 | 5V | *(see Power Nets)* |

## E5

| Pin | Net | Connected to |
|--|--|--|
| 1 | BUSAKB+ | E5/19, E13/19, E15/1, E16/15, E17/1, E17/19, E22/6, E108/13 |
| 2 | _NET_13 | E32/36 |
| 3 | A7B | E6/3, E7/17, J2/48 |
| 4 | _NET_16 | E32/33 |
| 5 | A1B | E6/5, E7/15, J2/36 |
| 6 | _NET_19 | E32/30 |
| 7 | A5B | E6/7, E7/13, J2/44 |
| 8 | _NET_15 | E32/34 |
| 9 | A2B | E6/9, E7/11, J2/38 |
| 10 | GND | *(see Power Nets)* |
| 11 | _NET_17 | E32/32 |
| 12 | A4B | E6/12, E7/8, J2/42 |
| 13 | _NET_14 | E32/35 |
| 14 | A0B | E6/14, E7/6, J2/34 |
| 15 | _NET_18 | E32/31 |
| 16 | A3B | E6/16, E7/4, J2/40 |
| 17 | _NET_12 | E32/37 |
| 18 | A6B | E6/18, E7/2, J2/46 |
| 19 | BUSAKB+ | E5/1, E13/19, E15/1, E16/15, E17/1, E17/19, E22/6, E108/13 |
| 20 | 5V | *(see Power Nets)* |

## E6

| Pin | Net | Connected to |
|--|--|--|
| 1 | BUSAKB- | E6/19, E13/1, E16/5, E18/1, E18/19, E22/5, E33/14, E34/13, J2/17 |
| 2 | _NET_175 | E33/40 |
| 3 | A7B | E5/3, E7/17, J2/48 |
| 4 | _NET_178 | E33/3 |
| 5 | A1B | E5/5, E7/15, J2/36 |
| 6 | _NET_181 | E33/6 |
| 7 | A5B | E5/7, E7/13, J2/44 |
| 8 | _NET_177 | E33/2 |
| 9 | A2B | E5/9, E7/11, J2/38 |
| 10 | GND | *(see Power Nets)* |
| 11 | _NET_179 | E33/4 |
| 12 | A4B | E5/12, E7/8, J2/42 |
| 13 | _NET_176 | E33/1 |
| 14 | A0B | E5/14, E7/6, J2/34 |
| 15 | _NET_180 | E33/5 |
| 16 | A3B | E5/16, E7/4, J2/40 |
| 17 | _NET_174 | E33/39 |
| 18 | A6B | E5/18, E7/2, J2/46 |
| 19 | BUSAKB- | E6/1, E13/1, E16/5, E18/1, E18/19, E22/5, E33/14, E34/13, J2/17 |
| 20 | 5V | *(see Power Nets)* |

## E7

| Pin | Net | Connected to |
|--|--|--|
| 1 | GND | *(see Power Nets)* |
| 2 | A6B | E5/18, E6/18, J2/46 |
| 3 | A7I | E8/2, E50/1, E51/1, E68/6, E69/6 |
| 4 | A3B | E5/16, E6/16, J2/40 |
| 5 | A1I | E8/4, E30/34, E31/34, E35/6, E50/7, E51/7, E63/6, E67/19 |
| 6 | A0B | E5/14, E6/14, J2/34 |
| 7 | A5I | E8/6, E50/3, E51/3, E68/3, E69/3 |
| 8 | A4B | E5/12, E6/12, J2/42 |
| 9 | A2I | E8/8, E35/7, E50/6, E51/6 |
| 10 | GND | *(see Power Nets)* |
| 11 | A2B | E5/9, E6/9, J2/38 |
| 12 | A4I | E8/11, E35/9, E50/4, E51/4, E68/2, E69/2 |
| 13 | A5B | E5/7, E6/7, J2/44 |
| 14 | A0I | E8/13, E30/33, E31/33, E35/5, E50/8, E51/8, E56/5, E63/5, E67/18 |
| 15 | A1B | E5/5, E6/5, J2/36 |
| 16 | A3I | E8/15, E35/8, E50/5, E51/5, E68/1, E69/1 |
| 17 | A7B | E5/3, E6/3, J2/48 |
| 18 | A6I | E8/17, E37/3, E50/2, E51/2, E69/5 |
| 19 | GND | *(see Power Nets)* |
| 20 | 5V | *(see Power Nets)* |

## E8

| Pin | Net | Connected to |
|--|--|--|
| 1 | MUX+ | E8/19, E25/11, E25/12, E36/5 |
| 2 | A7I | E7/3, E50/1, E51/1, E68/6, E69/6 |
| 3 | _NET_87 | E20/3, R50/1 |
| 4 | A1I | E7/5, E30/34, E31/34, E35/6, E50/7, E51/7, E63/6, E67/19 |
| 5 | _NET_84 | E20/5, R49/1 |
| 6 | A5I | E7/7, E50/3, E51/3, E68/3, E69/3 |
| 7 | _NET_81 | E20/7, R48/1 |
| 8 | A2I | E7/9, E35/7, E50/6, E51/6 |
| 9 | _NET_85 | E20/9, R47/1 |
| 10 | GND | *(see Power Nets)* |
| 11 | A4I | E7/12, E35/9, E50/4, E51/4, E68/2, E69/2 |
| 12 | _NET_83 | E20/12, R46/1 |
| 13 | A0I | E7/14, E30/33, E31/33, E35/5, E50/8, E51/8, E56/5, E63/5, E67/18 |
| 14 | _NET_86 | E20/14, R45/1 |
| 15 | A3I | E7/16, E35/8, E50/5, E51/5, E68/1, E69/1 |
| 16 | _NET_82 | E20/16, R44/1 |
| 17 | A6I | E7/18, E37/3, E50/2, E51/2, E69/5 |
| 18 | _NET_88 | E20/18, R43/1 |
| 19 | MUX+ | E8/1, E25/11, E25/12, E36/5 |
| 20 | 5V | *(see Power Nets)* |

## E9

| Pin | Net | Connected to |
|--|--|--|
| 1 | _NET_207 | E21/6 |
| 2 | WAITB- | E14/4, J2/31, R5/2 |
| 3 | unconnected-(E9-Pad3) |  |
| 4 | unconnected-(E9-Pad4) |  |
| 5 | unconnected-(E9-Pad5) |  |
| 6 | unconnected-(E9-Pad6) |  |
| 7 | GND | *(see Power Nets)* |
| 8 | _NET_209 | JJ12/1 |
| 9 | _NET_194 | E35/13 |
| 10 | unconnected-(E9-Pad10) |  |
| 11 | unconnected-(E9-Pad11) |  |
| 12 | unconnected-(E9-Pad12) |  |
| 13 | unconnected-(E9-Pad13) |  |
| 14 | 5V | *(see Power Nets)* |

## E10

| Pin | Net | Connected to |
|--|--|--|
| 1 | A14I- | E21/4 |
| 2 | A15I- | E21/10 |
| 3 | RFSHB- | E15/18, E36/11, E41/5, J2/39, R7/2 |
| 4 | IORQB- | E13/16, E13/17, E15/15, E15/16, E30/36, E31/36, E63/36, E67/10, E105/3, J2/35 |
| 5 | 5V | *(see Power Nets)* |
| 6 | A13I- | E21/8 |
| 7 | GND | *(see Power Nets)* |
| 8 | ROMSEL- | E36/1, E40/12 |
| 9 | unconnected-(E10-Pad9) |  |
| 10 | unconnected-(E10-Pad10) |  |
| 11 | _NET_47 | E11/5 |
| 12 | 5V | *(see Power Nets)* |
| 13 | unconnected-(E10-Pad13) |  |
| 14 | 5V | *(see Power Nets)* |

## E11

| Pin | Net | Connected to |
|--|--|--|
| 1 | SEL1- | E69/15 |
| 2 | _NET_48 | E11/3, R22/2 |
| 3 | _NET_48 | E11/2, R22/2 |
| 4 | RESET- | E4/6, E24/10, E30/21, E31/21, E32/26, E64/10, E67/17, E77/1, E77/13, E103/1, E103/13, E104/10, E104/4, J2/21 |
| 5 | _NET_47 | E10/11 |
| 6 | unconnected-(E11-Pad6) |  |
| 7 | GND | *(see Power Nets)* |
| 8 | BANKA1- | E24/2 |
| 9 | BANKA2- | E41/9 |
| 10 | _NET_53 | E24/8 |
| 11 | _NET_54 | E11/12, R23/2 |
| 12 | _NET_54 | E11/11, R23/2 |
| 13 | SEL3- | E69/13 |
| 14 | 5V | *(see Power Nets)* |

## E12

| Pin | Net | Connected to |
|--|--|--|
| 1 | DINB | E12/19, J2/43, R9/2 |
| 2 | D1B | E29/9, J2/51 |
| 3 | D0 | C11/2, E14/13, E29/8, E30/40, E31/40, E32/14, E33/35, E35/15, E39/14, E50/9, E51/9, E56/6, E61/2, E63/19, E65/8, E65/9, E66/8, E67/25, E87/2 |
| 4 | D3B | E29/7, J2/55 |
| 5 | DABUS2 | C13/2, E29/6, E30/39, E31/39, E32/12, E33/33, E35/17, E39/18, E50/11, E51/11, E56/8, E62/2, E63/1, E65/2, E65/3, E66/2, E67/27, E88/2 |
| 6 | D5B | E29/5, J2/59 |
| 7 | DABUS4 | C14/2, E29/4, E30/38, E31/38, E32/7, E33/31, E35/19, E39/5, E50/14, E51/14, E56/10, E59/2, E63/39, E65/14, E65/15, E66/13, E67/1, E85/2 |
| 8 | D7B | E29/3, J2/63 |
| 9 | DABUS6 | C10/1, E29/2, E30/37, E31/37, E32/10, E33/28, E35/21, E39/9, E50/16, E51/16, E56/12, E60/2, E63/3, E65/18, E65/19, E66/17, E67/3, E86/2 |
| 10 | GND | *(see Power Nets)* |
| 11 | D6B | E29/18, J2/61 |
| 12 | DABUS7 | C9/1, E29/17, E30/4, E31/4, E32/13, E33/27, E35/22, E39/12, E50/17, E51/17, E56/13, E63/2, E65/12, E65/13, E66/11, E67/4, E73/2, E100/2 |
| 13 | D4B | E29/16, J2/57 |
| 14 | DABUS5 | C15/1, E29/15, E30/3, E31/3, E32/9, E33/29, E35/20, E39/7, E50/15, E51/15, E56/11, E63/38, E65/6, E65/7, E66/6, E67/2, E72/2, E99/2 |
| 15 | D2B | E29/14, J2/53 |
| 16 | DABUS3 | C16/1, E29/13, E30/2, E31/2, E32/8, E33/32, E35/18, E39/3, E50/13, E51/13, E56/9, E63/40, E65/16, E65/17, E66/15, E67/28, E71/2, E98/2 |
| 17 | D0B | E29/12, J2/49 |
| 18 | DABUS1 | C12/2, E29/11, E30/1, E31/1, E32/15, E33/34, E35/16, E39/16, E50/10, E51/10, E56/7, E63/20, E65/4, E65/5, E66/4, E67/26, E74/2, E101/2 |
| 19 | DINB | E12/1, J2/43, R9/2 |
| 20 | 5V | *(see Power Nets)* |

## E13

| Pin | Net | Connected to |
|--|--|--|
| 1 | BUSAKB- | E6/1, E6/19, E16/5, E18/1, E18/19, E22/5, E33/14, E34/13, J2/17 |
| 2 | _NET_173 | E33/12, R13/1 |
| 3 | _NET_172 | E13/4, E33/10 |
| 4 | _NET_172 | E13/3, E33/10 |
| 5 | _NET_171 | E13/6, E33/9 |
| 6 | _NET_171 | E13/5, E33/9 |
| 7 | _NET_170 | E13/8, E33/8 |
| 8 | _NET_170 | E13/7, E33/8 |
| 9 | _NET_169 | E33/16, R12/1 |
| 10 | GND | *(see Power Nets)* |
| 11 | SEL9- | E68/15 |
| 12 | MRB- | E13/13, E15/11, E15/12, J2/37 |
| 13 | MRB- | E13/12, E15/11, E15/12, J2/37 |
| 14 | RDB- | E13/15, E15/13, E15/14, J2/32 |
| 15 | RDB- | E13/14, E15/13, E15/14, J2/32 |
| 16 | IORQB- | E10/4, E13/17, E15/15, E15/16, E30/36, E31/36, E63/36, E67/10, E105/3, J2/35 |
| 17 | IORQB- | E10/4, E13/16, E15/15, E15/16, E30/36, E31/36, E63/36, E67/10, E105/3, J2/35 |
| 18 | MREQB- | E2/3, E16/13, E36/13, E41/4, J2/25 |
| 19 | BUSAKB+ | E5/1, E5/19, E15/1, E16/15, E17/1, E17/19, E22/6, E108/13 |
| 20 | 5V | *(see Power Nets)* |

## E14

| Pin | Net | Connected to |
|--|--|--|
| 1 | GND | *(see Power Nets)* |
| 2 | BUSRQ- | E33/15, J2/28, R3/2 |
| 3 | _NET_29 | E32/25 |
| 4 | WAITB- | E9/2, J2/31, R5/2 |
| 5 | _NET_31 | E32/24 |
| 6 | NMI- | J2/26, JJ12/2, R2/2 |
| 7 | _NET_30 | E32/17 |
| 8 | GND | *(see Power Nets)* |
| 9 | IEOB | J2/15 |
| 10 | _NET_206 | E77/8 |
| 11 | unconnected-(E14-Pad11) |  |
| 12 | unconnected-(E14-Pad12) |  |
| 13 | D0 | C11/2, E12/3, E29/8, E30/40, E31/40, E32/14, E33/35, E35/15, E39/14, E50/9, E51/9, E56/6, E61/2, E63/19, E65/8, E65/9, E66/8, E67/25, E87/2 |
| 14 | MON | E27/4, E27/5, E107/9 |
| 15 | _NET_210 | E95/11 |
| 16 | 5V | *(see Power Nets)* |

## E15

| Pin | Net | Connected to |
|--|--|--|
| 1 | BUSAKB+ | E5/1, E5/19, E13/19, E16/15, E17/1, E17/19, E22/6, E108/13 |
| 2 | _NET_21 | E32/28 |
| 3 | BI | E30/20, E31/20, E33/7, E63/25, E67/15, R19/1 |
| 4 | IORQ- | E22/13, E32/20 |
| 5 | unconnected-(E15-Pad5) |  |
| 6 | _NET_23 | E32/21 |
| 7 | RDI- | E30/32, E31/32, E35/2, E38/13, E40/13, E56/2, E63/35, E67/6, E82/13, E91/2 |
| 8 | _NET_22 | E32/22 |
| 9 | _NET_50 | C300/1, E22/1 |
| 10 | GND | *(see Power Nets)* |
| 11 | MRB- | E13/12, E13/13, E15/12, J2/37 |
| 12 | MRB- | E13/12, E13/13, E15/11, J2/37 |
| 13 | RDB- | E13/14, E13/15, E15/14, J2/32 |
| 14 | RDB- | E13/14, E13/15, E15/13, J2/32 |
| 15 | IORQB- | E10/4, E13/16, E13/17, E15/16, E30/36, E31/36, E63/36, E67/10, E105/3, J2/35 |
| 16 | IORQB- | E10/4, E13/16, E13/17, E15/15, E30/36, E31/36, E63/36, E67/10, E105/3, J2/35 |
| 17 | 0B | E16/9, J2/33 |
| 18 | RFSHB- | E10/3, E36/11, E41/5, J2/39, R7/2 |
| 19 | GND | *(see Power Nets)* |
| 20 | 5V | *(see Power Nets)* |

## E16

| Pin | Net | Connected to |
|--|--|--|
| 1 | GND | *(see Power Nets)* |
| 2 | _NET_25 | E32/27 |
| 3 | M1B- | E4/3, E24/13, E30/8, E31/8, E33/26, E63/37, E67/14, E91/1, E105/4, J2/24 |
| 4 | _NET_24 | E32/23 |
| 5 | BUSAKB- | E6/1, E6/19, E13/1, E18/1, E18/19, E22/5, E33/14, E34/13, J2/17 |
| 6 | _NET_27 | E32/18 |
| 7 | HALTB- | J2/30, R16/2 |
| 8 | GND | *(see Power Nets)* |
| 9 | 0B | E15/17, J2/33 |
| 10 | _NET_32 | E3/2, E3/6, E32/6, R203/2 |
| 11 | unconnected-(E16-Pad11) |  |
| 12 | unconnected-(E16-Pad12) |  |
| 13 | MREQB- | E2/3, E13/18, E36/13, E41/4, J2/25 |
| 14 | _NET_20 | E32/19 |
| 15 | BUSAKB+ | E5/1, E5/19, E13/19, E15/1, E17/1, E17/19, E22/6, E108/13 |
| 16 | 5V | *(see Power Nets)* |

## E17

| Pin | Net | Connected to |
|--|--|--|
| 1 | BUSAKB+ | E5/1, E5/19, E13/19, E15/1, E16/15, E17/19, E22/6, E108/13 |
| 2 | _NET_5 | E32/4 |
| 3 | A15B | E18/3, E19/17 |
| 4 | _NET_8 | E32/1 |
| 5 | A9B | E18/5, E19/15 |
| 6 | _NET_11 | E32/38 |
| 7 | A13B | E18/7, E19/13 |
| 8 | _NET_7 | E32/2 |
| 9 | A10B | E18/9, E19/11 |
| 10 | GND | *(see Power Nets)* |
| 11 | _NET_9 | E32/40 |
| 12 | A12B | E18/12, E19/8 |
| 13 | _NET_6 | E32/3 |
| 14 | A8B | E18/14, E19/6 |
| 15 | _NET_10 | E32/39 |
| 16 | A11B | E18/16, E19/4 |
| 17 | _NET_4 | E32/5 |
| 18 | A14B | E18/18, E19/2 |
| 19 | BUSAKB+ | E5/1, E5/19, E13/19, E15/1, E16/15, E17/1, E22/6, E108/13 |
| 20 | 5V | *(see Power Nets)* |

## E18

| Pin | Net | Connected to |
|--|--|--|
| 1 | BUSAKB- | E6/1, E6/19, E13/1, E16/5, E18/19, E22/5, E33/14, E34/13, J2/17 |
| 2 | _NET_183 | E33/18 |
| 3 | A15B | E17/3, E19/17 |
| 4 | _NET_186 | E33/21 |
| 5 | A9B | E17/5, E19/15 |
| 6 | _NET_189 | E33/24 |
| 7 | A13B | E17/7, E19/13 |
| 8 | _NET_185 | E33/20 |
| 9 | A10B | E17/9, E19/11 |
| 10 | GND | *(see Power Nets)* |
| 11 | _NET_187 | E33/22 |
| 12 | A12B | E17/12, E19/8 |
| 13 | _NET_184 | E33/19 |
| 14 | A8B | E17/14, E19/6 |
| 15 | _NET_188 | E33/23 |
| 16 | A11B | E17/16, E19/4 |
| 17 | _NET_182 | E33/17 |
| 18 | A14B | E17/18, E19/2 |
| 19 | BUSAKB- | E6/1, E6/19, E13/1, E16/5, E18/1, E22/5, E33/14, E34/13, J2/17 |
| 20 | 5V | *(see Power Nets)* |

## E19

| Pin | Net | Connected to |
|--|--|--|
| 1 | GND | *(see Power Nets)* |
| 2 | A14B | E17/18, E18/18 |
| 3 | A15I | E20/2, E21/11, E24/4 |
| 4 | A11B | E17/16, E18/16 |
| 5 | A9I | E20/4, E50/22, E51/22 |
| 6 | A8B | E17/14, E18/14 |
| 7 | A13I | E20/6, E21/9 |
| 8 | A12B | E17/12, E18/12 |
| 9 | A10I | E20/8, E50/19, E51/19 |
| 10 | GND | *(see Power Nets)* |
| 11 | A10B | E17/9, E18/9 |
| 12 | A12I | E20/11, E40/14 |
| 13 | A13B | E17/7, E18/7 |
| 14 | A8I | E20/13, E50/23, E51/23 |
| 15 | A9B | E17/5, E18/5 |
| 16 | A11I | E20/15, E40/15 |
| 17 | A15B | E17/3, E18/3 |
| 18 | A14I | E20/17, E21/3, E24/5 |
| 19 | GND | *(see Power Nets)* |
| 20 | 5V | *(see Power Nets)* |

## E20

| Pin | Net | Connected to |
|--|--|--|
| 1 | MUX- | E20/19, E36/6 |
| 2 | A15I | E19/3, E21/11, E24/4 |
| 3 | _NET_87 | E8/3, R50/1 |
| 4 | A9I | E19/5, E50/22, E51/22 |
| 5 | _NET_84 | E8/5, R49/1 |
| 6 | A13I | E19/7, E21/9 |
| 7 | _NET_81 | E8/7, R48/1 |
| 8 | A10I | E19/9, E50/19, E51/19 |
| 9 | _NET_85 | E8/9, R47/1 |
| 10 | GND | *(see Power Nets)* |
| 11 | A12I | E19/12, E40/14 |
| 12 | _NET_83 | E8/12, R46/1 |
| 13 | A8I | E19/14, E50/23, E51/23 |
| 14 | _NET_86 | E8/14, R45/1 |
| 15 | A11I | E19/16, E40/15 |
| 16 | _NET_82 | E8/16, R44/1 |
| 17 | A14I | E19/18, E21/3, E24/5 |
| 18 | _NET_88 | E8/18, R43/1 |
| 19 | MUX- | E20/1, E36/6 |
| 20 | 5V | *(see Power Nets)* |

## E21

| Pin | Net | Connected to |
|--|--|--|
| 1 | _NET_208 | E55/8 |
| 2 | _NET_190 | E35/1 |
| 3 | A14I | E19/18, E20/17, E24/5 |
| 4 | A14I- | E10/1 |
| 5 | _NET_191 | E35/4, R21/1 |
| 6 | _NET_207 | E9/1 |
| 7 | GND | *(see Power Nets)* |
| 8 | A13I- | E10/6 |
| 9 | A13I | E19/7, E20/6 |
| 10 | A15I- | E10/2 |
| 11 | A15I | E19/3, E20/2, E24/4 |
| 12 | unconnected-(E21-Pad12) |  |
| 13 | unconnected-(E21-Pad13) |  |
| 14 | 5V | *(see Power Nets)* |

## E22

| Pin | Net | Connected to |
|--|--|--|
| 1 | _NET_50 | C300/1, E15/9 |
| 2 | _NET_49 | C300/2, E22/3 |
| 3 | _NET_49 | C300/2, E22/2 |
| 4 | WRI- | E29/1, E29/19, E35/3, E56/3, E91/5, E94/5, E107/3, R51/1 |
| 5 | BUSAKB- | E6/1, E6/19, E13/1, E16/5, E18/1, E18/19, E33/14, E34/13, J2/17 |
| 6 | BUSAKB+ | E5/1, E5/19, E13/19, E15/1, E16/15, E17/1, E17/19, E108/13 |
| 7 | GND | *(see Power Nets)* |
| 8 | _NET_288 | C101/1 |
| 9 | _NET_279 | E82/4, R57/1 |
| 10 | _NET_277 | E26/5, E28/5 |
| 11 | DS1 | E26/1, E28/1, E56/28 |
| 12 | _NET_45 | E24/12 |
| 13 | IORQ- | E15/4, E32/20 |
| 14 | 5V | *(see Power Nets)* |

## E23

| Pin | Net | Connected to |
|--|--|--|
| 1 | _NET_59 | E38/3 |
| 2 | _NET_58 | E23/9, E41/6 |
| 3 | RAS2- | E84/5, E85/4, E86/4, E87/4, E88/4, E98/4, E99/4, E100/4, E101/4 |
| 4 | unconnected-(E23-Pad4) |  |
| 5 | unconnected-(E23-Pad5) |  |
| 6 | unconnected-(E23-Pad6) |  |
| 7 | GND | *(see Power Nets)* |
| 8 | RAS1- | E59/4, E60/4, E61/4, E62/4, E71/4, E72/4, E73/4, E74/4, E84/4 |
| 9 | _NET_58 | E23/2, E41/6 |
| 10 | _NET_65 | E38/6 |
| 11 | _NET_71 | R52/1 |
| 12 | _NET_70 | E23/13, E25/8 |
| 13 | _NET_70 | E23/12, E25/8 |
| 14 | 5V | *(see Power Nets)* |

## E24

| Pin | Net | Connected to |
|--|--|--|
| 1 | _NET_55 | E36/8 |
| 2 | BANKA1- | E11/8 |
| 3 | BANK1- | C103/2, E38/4 |
| 4 | A15I | E19/3, E20/2, E21/11 |
| 5 | A14I | E19/18, E20/17, E21/3 |
| 6 | _NET_56 | E36/9, E41/10 |
| 7 | GND | *(see Power Nets)* |
| 8 | _NET_53 | E11/10 |
| 9 | SEL2- | E69/14 |
| 10 | RESET- | E4/6, E11/4, E30/21, E31/21, E32/26, E64/10, E67/17, E77/1, E77/13, E103/1, E103/13, E104/10, E104/4, J2/21 |
| 11 | _NET_46 | C110/2, E37/11 |
| 12 | _NET_45 | E22/12 |
| 13 | M1B- | E4/3, E16/3, E30/8, E31/8, E33/26, E63/37, E67/14, E91/1, E105/4, J2/24 |
| 14 | 5V | *(see Power Nets)* |

## E25

| Pin | Net | Connected to |
|--|--|--|
| 1 | _NET_67 | E25/6 |
| 2 | _NET_68 | E25/3 |
| 3 | _NET_68 | E25/2 |
| 4 | _NET_69 | E25/9 |
| 5 | _NET_66 | E25/10 |
| 6 | _NET_67 | E25/1 |
| 7 | GND | *(see Power Nets)* |
| 8 | _NET_70 | E23/12, E23/13 |
| 9 | _NET_69 | E25/4 |
| 10 | _NET_66 | E25/5 |
| 11 | MUX+ | E8/1, E8/19, E25/12, E36/5 |
| 12 | MUX+ | E8/1, E8/19, E25/11, E36/5 |
| 13 | SIGN1- | E38/12, E38/8 |
| 14 | 5V | *(see Power Nets)* |

## E26

| Pin | Net | Connected to |
|--|--|--|
| 1 | DS1 | E22/11, E28/1, E56/28 |
| 2 | _NET_276 | E28/4, E82/10 |
| 3 | DISK2- | J1/14, J4/30 |
| 4 | DS0 | E28/2, E56/29, E82/11 |
| 5 | _NET_277 | E22/10, E28/5 |
| 6 | DISK1- | J1/12, J4/28 |
| 7 | GND | *(see Power Nets)* |
| 8 | WRITEEN- | J1/24, J4/40 |
| 9 | _NET_237 | E26/10, E48/7, E56/25 |
| 10 | _NET_237 | E26/9, E48/7, E56/25 |
| 11 | HEADSEL- | J1/32 |
| 12 | HDSEL | E26/13, E56/27 |
| 13 | HDSEL | E26/12, E56/27 |
| 14 | 5V | *(see Power Nets)* |

## E27

| Pin | Net | Connected to |
|--|--|--|
| 1 | LC-DIR | E56/38 |
| 2 | SEEK | E27/13, E49/1, E56/39, E82/9 |
| 3 | DIRECTION- | J1/18, J4/34 |
| 4 | MON | E14/14, E27/5, E107/9 |
| 5 | MON | E14/14, E27/4, E107/9 |
| 6 | MOTORON- | J1/16 |
| 7 | GND | *(see Power Nets)* |
| 8 | WDATA- | J1/22, J4/38 |
| 9 | _NET_248 | E27/10, E48/6 |
| 10 | _NET_248 | E27/9, E48/6 |
| 11 | STEP- | J1/20, J4/36 |
| 12 | FR-STP | E28/12, E56/37 |
| 13 | SEEK | E27/2, E49/1, E56/39, E82/9 |
| 14 | 5V | *(see Power Nets)* |

## E28

| Pin | Net | Connected to |
|--|--|--|
| 1 | DS1 | E22/11, E26/1, E56/28 |
| 2 | DS0 | E26/4, E56/29, E82/11 |
| 3 | DISK4- | J1/6, J4/32 |
| 4 | _NET_276 | E26/2, E82/10 |
| 5 | _NET_277 | E22/10, E26/5 |
| 6 | DISK0- | C102/1, J1/10, J4/26 |
| 7 | GND | *(see Power Nets)* |
| 8 | unconnected-HEADLOAD- |  |
| 9 | HDL | E28/10, E56/36 |
| 10 | HDL | E28/9, E56/36 |
| 11 | unconnected-(E28-Pad11) |  |
| 12 | FR-STP | E27/12, E56/37 |
| 13 | SEEK- | E82/8 |
| 14 | 5V | *(see Power Nets)* |

## E29

| Pin | Net | Connected to |
|--|--|--|
| 1 | WRI- | E22/4, E29/19, E35/3, E56/3, E91/5, E94/5, E107/3, R51/1 |
| 2 | DABUS6 | C10/1, E12/9, E30/37, E31/37, E32/10, E33/28, E35/21, E39/9, E50/16, E51/16, E56/12, E60/2, E63/3, E65/18, E65/19, E66/17, E67/3, E86/2 |
| 3 | D7B | E12/8, J2/63 |
| 4 | DABUS4 | C14/2, E12/7, E30/38, E31/38, E32/7, E33/31, E35/19, E39/5, E50/14, E51/14, E56/10, E59/2, E63/39, E65/14, E65/15, E66/13, E67/1, E85/2 |
| 5 | D5B | E12/6, J2/59 |
| 6 | DABUS2 | C13/2, E12/5, E30/39, E31/39, E32/12, E33/33, E35/17, E39/18, E50/11, E51/11, E56/8, E62/2, E63/1, E65/2, E65/3, E66/2, E67/27, E88/2 |
| 7 | D3B | E12/4, J2/55 |
| 8 | D0 | C11/2, E12/3, E14/13, E30/40, E31/40, E32/14, E33/35, E35/15, E39/14, E50/9, E51/9, E56/6, E61/2, E63/19, E65/8, E65/9, E66/8, E67/25, E87/2 |
| 9 | D1B | E12/2, J2/51 |
| 10 | GND | *(see Power Nets)* |
| 11 | DABUS1 | C12/2, E12/18, E30/1, E31/1, E32/15, E33/34, E35/16, E39/16, E50/10, E51/10, E56/7, E63/20, E65/4, E65/5, E66/4, E67/26, E74/2, E101/2 |
| 12 | D0B | E12/17, J2/49 |
| 13 | DABUS3 | C16/1, E12/16, E30/2, E31/2, E32/8, E33/32, E35/18, E39/3, E50/13, E51/13, E56/9, E63/40, E65/16, E65/17, E66/15, E67/28, E71/2, E98/2 |
| 14 | D2B | E12/15, J2/53 |
| 15 | DABUS5 | C15/1, E12/14, E30/3, E31/3, E32/9, E33/29, E35/20, E39/7, E50/15, E51/15, E56/11, E63/38, E65/6, E65/7, E66/6, E67/2, E72/2, E99/2 |
| 16 | D4B | E12/13, J2/57 |
| 17 | DABUS7 | C9/1, E12/12, E30/4, E31/4, E32/13, E33/27, E35/22, E39/12, E50/17, E51/17, E56/13, E63/2, E65/12, E65/13, E66/11, E67/4, E73/2, E100/2 |
| 18 | D6B | E12/11, J2/61 |
| 19 | WRI- | E22/4, E29/1, E35/3, E56/3, E91/5, E94/5, E107/3, R51/1 |
| 20 | 5V | *(see Power Nets)* |

## E30

| Pin | Net | Connected to |
|--|--|--|
| 1 | DABUS1 | C12/2, E12/18, E29/11, E31/1, E32/15, E33/34, E35/16, E39/16, E50/10, E51/10, E56/7, E63/20, E65/4, E65/5, E66/4, E67/26, E74/2, E101/2 |
| 2 | DABUS3 | C16/1, E12/16, E29/13, E31/2, E32/8, E33/32, E35/18, E39/3, E50/13, E51/13, E56/9, E63/40, E65/16, E65/17, E66/15, E67/28, E71/2, E98/2 |
| 3 | DABUS5 | C15/1, E12/14, E29/15, E31/3, E32/9, E33/29, E35/20, E39/7, E50/15, E51/15, E56/11, E63/38, E65/6, E65/7, E66/6, E67/2, E72/2, E99/2 |
| 4 | DABUS7 | C9/1, E12/12, E29/17, E31/4, E32/13, E33/27, E35/22, E39/12, E50/17, E51/17, E56/13, E63/2, E65/12, E65/13, E66/11, E67/4, E73/2, E100/2 |
| 5 | INT- | E31/5, E63/23, E67/12, E81/1, E81/4, E84/2, R54/2 |
| 6 | SIOIEI1 | E47/3, E55/1 |
| 7 | SIOIEO1 | E47/5 |
| 8 | M1B- | E4/3, E16/3, E24/13, E31/8, E33/26, E63/37, E67/14, E91/1, E105/4, J2/24 |
| 9 | 5V | *(see Power Nets)* |
| 10 | unconnected-(E30-Pad10) |  |
| 11 | unconnected-(E30-Pad11) |  |
| 12 | _NET_91 | E2/10 |
| 13 | SPEED1 | E30/14, JJ8B/1 |
| 14 | SPEED1 | E30/13, JJ8B/1 |
| 15 | _NET_92 | E46/4, E46/5 |
| 16 | unconnected-(E30-Pad16) |  |
| 17 | unconnected-(E30-Pad17) |  |
| 18 | unconnected-(E30-Pad18) |  |
| 19 | unconnected-(E30-Pad19) |  |
| 20 | BI | E15/3, E31/20, E33/7, E63/25, E67/15, R19/1 |
| 21 | RESET- | E4/6, E11/4, E24/10, E31/21, E32/26, E64/10, E67/17, E77/1, E77/13, E103/1, E103/13, E104/10, E104/4, J2/21 |
| 22 | _NET_98 | E46/11 |
| 23 | _NET_97 | E46/8 |
| 24 | _NET_96 | E43/4 |
| 25 | _NET_95 | E43/2 |
| 26 | SPEED2 | E30/27, JJ8B/2 |
| 27 | SPEED2 | E30/26, JJ8B/2 |
| 28 | _NET_94 | E45/3 |
| 29 | unconnected-(E30-Pad29) |  |
| 30 | unconnected-(E30-Pad30) |  |
| 31 | GND | *(see Power Nets)* |
| 32 | RDI- | E15/7, E31/32, E35/2, E38/13, E40/13, E56/2, E63/35, E67/6, E82/13, E91/2 |
| 33 | A0I | E7/14, E8/13, E31/33, E35/5, E50/8, E51/8, E56/5, E63/5, E67/18 |
| 34 | A1I | E7/5, E8/4, E31/34, E35/6, E50/7, E51/7, E63/6, E67/19 |
| 35 | SEL12- | E68/12 |
| 36 | IORQB- | E10/4, E13/16, E13/17, E15/15, E15/16, E31/36, E63/36, E67/10, E105/3, J2/35 |
| 37 | DABUS6 | C10/1, E12/9, E29/2, E31/37, E32/10, E33/28, E35/21, E39/9, E50/16, E51/16, E56/12, E60/2, E63/3, E65/18, E65/19, E66/17, E67/3, E86/2 |
| 38 | DABUS4 | C14/2, E12/7, E29/4, E31/38, E32/7, E33/31, E35/19, E39/5, E50/14, E51/14, E56/10, E59/2, E63/39, E65/14, E65/15, E66/13, E67/1, E85/2 |
| 39 | DABUS2 | C13/2, E12/5, E29/6, E31/39, E32/12, E33/33, E35/17, E39/18, E50/11, E51/11, E56/8, E62/2, E63/1, E65/2, E65/3, E66/2, E67/27, E88/2 |
| 40 | D0 | C11/2, E12/3, E14/13, E29/8, E31/40, E32/14, E33/35, E35/15, E39/14, E50/9, E51/9, E56/6, E61/2, E63/19, E65/8, E65/9, E66/8, E67/25, E87/2 |

## E31

| Pin | Net | Connected to |
|--|--|--|
| 1 | DABUS1 | C12/2, E12/18, E29/11, E30/1, E32/15, E33/34, E35/16, E39/16, E50/10, E51/10, E56/7, E63/20, E65/4, E65/5, E66/4, E67/26, E74/2, E101/2 |
| 2 | DABUS3 | C16/1, E12/16, E29/13, E30/2, E32/8, E33/32, E35/18, E39/3, E50/13, E51/13, E56/9, E63/40, E65/16, E65/17, E66/15, E67/28, E71/2, E98/2 |
| 3 | DABUS5 | C15/1, E12/14, E29/15, E30/3, E32/9, E33/29, E35/20, E39/7, E50/15, E51/15, E56/11, E63/38, E65/6, E65/7, E66/6, E67/2, E72/2, E99/2 |
| 4 | DABUS7 | C9/1, E12/12, E29/17, E30/4, E32/13, E33/27, E35/22, E39/12, E50/17, E51/17, E56/13, E63/2, E65/12, E65/13, E66/11, E67/4, E73/2, E100/2 |
| 5 | INT- | E30/5, E63/23, E67/12, E81/1, E81/4, E84/2, R54/2 |
| 6 | SIOIEI2 | E47/6, E55/2 |
| 7 | SIOIEO2 | E47/12 |
| 8 | M1B- | E4/3, E16/3, E24/13, E30/8, E33/26, E63/37, E67/14, E91/1, E105/4, J2/24 |
| 9 | 5V | *(see Power Nets)* |
| 10 | unconnected-(E31-Pad10) |  |
| 11 | unconnected-(E31-Pad11) |  |
| 12 | _NET_102 | E52/3 |
| 13 | SPEED3 | E31/14, JJ8B/3 |
| 14 | SPEED3 | E31/13, JJ8B/3 |
| 15 | _NET_103 | E44/9 |
| 16 | unconnected-(E31-Pad16) |  |
| 17 | _NET_104 | E44/12 |
| 18 | _NET_105 | E54/8 |
| 19 | _NET_106 | E54/11 |
| 20 | BI | E15/3, E30/20, E33/7, E63/25, E67/15, R19/1 |
| 21 | RESET- | E4/6, E11/4, E24/10, E30/21, E32/26, E64/10, E67/17, E77/1, E77/13, E103/1, E103/13, E104/10, E104/4, J2/21 |
| 22 | _NET_111 | E54/6 |
| 23 | _NET_110 | E54/3 |
| 24 | _NET_109 | E43/12 |
| 25 | _NET_108 | E43/9 |
| 26 | SPEED4 | E31/27, JJ8B/4 |
| 27 | SPEED4 | E31/26, JJ8B/4 |
| 28 | _NET_107 | E53/3 |
| 29 | unconnected-(E31-Pad29) |  |
| 30 | unconnected-(E31-Pad30) |  |
| 31 | GND | *(see Power Nets)* |
| 32 | RDI- | E15/7, E30/32, E35/2, E38/13, E40/13, E56/2, E63/35, E67/6, E82/13, E91/2 |
| 33 | A0I | E7/14, E8/13, E30/33, E35/5, E50/8, E51/8, E56/5, E63/5, E67/18 |
| 34 | A1I | E7/5, E8/4, E30/34, E35/6, E50/7, E51/7, E63/6, E67/19 |
| 35 | SEL13- | E68/11 |
| 36 | IORQB- | E10/4, E13/16, E13/17, E15/15, E15/16, E30/36, E63/36, E67/10, E105/3, J2/35 |
| 37 | DABUS6 | C10/1, E12/9, E29/2, E30/37, E32/10, E33/28, E35/21, E39/9, E50/16, E51/16, E56/12, E60/2, E63/3, E65/18, E65/19, E66/17, E67/3, E86/2 |
| 38 | DABUS4 | C14/2, E12/7, E29/4, E30/38, E32/7, E33/31, E35/19, E39/5, E50/14, E51/14, E56/10, E59/2, E63/39, E65/14, E65/15, E66/13, E67/1, E85/2 |
| 39 | DABUS2 | C13/2, E12/5, E29/6, E30/39, E32/12, E33/33, E35/17, E39/18, E50/11, E51/11, E56/8, E62/2, E63/1, E65/2, E65/3, E66/2, E67/27, E88/2 |
| 40 | D0 | C11/2, E12/3, E14/13, E29/8, E30/40, E32/14, E33/35, E35/15, E39/14, E50/9, E51/9, E56/6, E61/2, E63/19, E65/8, E65/9, E66/8, E67/25, E87/2 |

## E32

| Pin | Net | Connected to |
|--|--|--|
| 1 | _NET_8 | E17/4 |
| 2 | _NET_7 | E17/8 |
| 3 | _NET_6 | E17/13 |
| 4 | _NET_5 | E17/2 |
| 5 | _NET_4 | E17/17 |
| 6 | _NET_32 | E3/2, E3/6, E16/10, R203/2 |
| 7 | DABUS4 | C14/2, E12/7, E29/4, E30/38, E31/38, E33/31, E35/19, E39/5, E50/14, E51/14, E56/10, E59/2, E63/39, E65/14, E65/15, E66/13, E67/1, E85/2 |
| 8 | DABUS3 | C16/1, E12/16, E29/13, E30/2, E31/2, E33/32, E35/18, E39/3, E50/13, E51/13, E56/9, E63/40, E65/16, E65/17, E66/15, E67/28, E71/2, E98/2 |
| 9 | DABUS5 | C15/1, E12/14, E29/15, E30/3, E31/3, E33/29, E35/20, E39/7, E50/15, E51/15, E56/11, E63/38, E65/6, E65/7, E66/6, E67/2, E72/2, E99/2 |
| 10 | DABUS6 | C10/1, E12/9, E29/2, E30/37, E31/37, E33/28, E35/21, E39/9, E50/16, E51/16, E56/12, E60/2, E63/3, E65/18, E65/19, E66/17, E67/3, E86/2 |
| 11 | 5V | *(see Power Nets)* |
| 12 | DABUS2 | C13/2, E12/5, E29/6, E30/39, E31/39, E33/33, E35/17, E39/18, E50/11, E51/11, E56/8, E62/2, E63/1, E65/2, E65/3, E66/2, E67/27, E88/2 |
| 13 | DABUS7 | C9/1, E12/12, E29/17, E30/4, E31/4, E33/27, E35/22, E39/12, E50/17, E51/17, E56/13, E63/2, E65/12, E65/13, E66/11, E67/4, E73/2, E100/2 |
| 14 | D0 | C11/2, E12/3, E14/13, E29/8, E30/40, E31/40, E33/35, E35/15, E39/14, E50/9, E51/9, E56/6, E61/2, E63/19, E65/8, E65/9, E66/8, E67/25, E87/2 |
| 15 | DABUS1 | C12/2, E12/18, E29/11, E30/1, E31/1, E33/34, E35/16, E39/16, E50/10, E51/10, E56/7, E63/20, E65/4, E65/5, E66/4, E67/26, E74/2, E101/2 |
| 16 | _NET_28 | E84/3 |
| 17 | _NET_30 | E14/7 |
| 18 | _NET_27 | E16/6 |
| 19 | _NET_20 | E16/14 |
| 20 | IORQ- | E15/4, E22/13 |
| 21 | _NET_23 | E15/6 |
| 22 | _NET_22 | E15/8 |
| 23 | _NET_24 | E16/4 |
| 24 | _NET_31 | E14/5 |
| 25 | _NET_29 | E14/3 |
| 26 | RESET- | E4/6, E11/4, E24/10, E30/21, E31/21, E64/10, E67/17, E77/1, E77/13, E103/1, E103/13, E104/10, E104/4, J2/21 |
| 27 | _NET_25 | E16/2 |
| 28 | _NET_21 | E15/2 |
| 29 | GND | *(see Power Nets)* |
| 30 | _NET_19 | E5/6 |
| 31 | _NET_18 | E5/15 |
| 32 | _NET_17 | E5/11 |
| 33 | _NET_16 | E5/4 |
| 34 | _NET_15 | E5/8 |
| 35 | _NET_14 | E5/13 |
| 36 | _NET_13 | E5/2 |
| 37 | _NET_12 | E5/17 |
| 38 | _NET_11 | E17/6 |
| 39 | _NET_10 | E17/15 |
| 40 | _NET_9 | E17/11 |

## E33

| Pin | Net | Connected to |
|--|--|--|
| 1 | _NET_176 | E6/13 |
| 2 | _NET_177 | E6/8 |
| 3 | _NET_178 | E6/4 |
| 4 | _NET_179 | E6/11 |
| 5 | _NET_180 | E6/15 |
| 6 | _NET_181 | E6/6 |
| 7 | BI | E15/3, E30/20, E31/20, E63/25, E67/15, R19/1 |
| 8 | _NET_170 | E13/7, E13/8 |
| 9 | _NET_171 | E13/5, E13/6 |
| 10 | _NET_172 | E13/3, E13/4 |
| 11 | 5V | *(see Power Nets)* |
| 12 | _NET_173 | E13/2, R13/1 |
| 13 | unconnected-(E33-Pad13) |  |
| 14 | BUSAKB- | E6/1, E6/19, E13/1, E16/5, E18/1, E18/19, E22/5, E34/13, J2/17 |
| 15 | BUSRQ- | E14/2, J2/28, R3/2 |
| 16 | _NET_169 | E13/9, R12/1 |
| 17 | _NET_182 | E18/17 |
| 18 | _NET_183 | E18/2 |
| 19 | _NET_184 | E18/13 |
| 20 | _NET_185 | E18/8 |
| 21 | _NET_186 | E18/4 |
| 22 | _NET_187 | E18/11 |
| 23 | _NET_188 | E18/15 |
| 24 | _NET_189 | E18/6 |
| 25 | _NET_168 | E34/3 |
| 26 | M1B- | E4/3, E16/3, E24/13, E30/8, E31/8, E63/37, E67/14, E91/1, E105/4, J2/24 |
| 27 | DABUS7 | C9/1, E12/12, E29/17, E30/4, E31/4, E32/13, E35/22, E39/12, E50/17, E51/17, E56/13, E63/2, E65/12, E65/13, E66/11, E67/4, E73/2, E100/2 |
| 28 | DABUS6 | C10/1, E12/9, E29/2, E30/37, E31/37, E32/10, E35/21, E39/9, E50/16, E51/16, E56/12, E60/2, E63/3, E65/18, E65/19, E66/17, E67/3, E86/2 |
| 29 | DABUS5 | C15/1, E12/14, E29/15, E30/3, E31/3, E32/9, E35/20, E39/7, E50/15, E51/15, E56/11, E63/38, E65/6, E65/7, E66/6, E67/2, E72/2, E99/2 |
| 30 | GND | *(see Power Nets)* |
| 31 | DABUS4 | C14/2, E12/7, E29/4, E30/38, E31/38, E32/7, E35/19, E39/5, E50/14, E51/14, E56/10, E59/2, E63/39, E65/14, E65/15, E66/13, E67/1, E85/2 |
| 32 | DABUS3 | C16/1, E12/16, E29/13, E30/2, E31/2, E32/8, E35/18, E39/3, E50/13, E51/13, E56/9, E63/40, E65/16, E65/17, E66/15, E67/28, E71/2, E98/2 |
| 33 | DABUS2 | C13/2, E12/5, E29/6, E30/39, E31/39, E32/12, E35/17, E39/18, E50/11, E51/11, E56/8, E62/2, E63/1, E65/2, E65/3, E66/2, E67/27, E88/2 |
| 34 | DABUS1 | C12/2, E12/18, E29/11, E30/1, E31/1, E32/15, E35/16, E39/16, E50/10, E51/10, E56/7, E63/20, E65/4, E65/5, E66/4, E67/26, E74/2, E101/2 |
| 35 | D0 | C11/2, E12/3, E14/13, E29/8, E30/40, E31/40, E32/14, E35/15, E39/14, E50/9, E51/9, E56/6, E61/2, E63/19, E65/8, E65/9, E66/8, E67/25, E87/2 |
| 36 | DMAIEO | E47/2 |
| 37 | INT1- | E37/13, R36/1 |
| 38 | CTCIEO | E47/1, E47/10, E47/13, E47/4, E67/11 |
| 39 | _NET_174 | E6/17 |
| 40 | _NET_175 | E6/2 |

## E34

| Pin | Net | Connected to |
|--|--|--|
| 1 | _NET_205 | E37/6 |
| 2 | _NET_199 | E107/5 |
| 3 | _NET_168 | E33/25 |
| 4 | unconnected-(E34-Pad4) |  |
| 5 | unconnected-(E34-Pad5) |  |
| 6 | unconnected-(E34-Pad6) |  |
| 7 | GND | *(see Power Nets)* |
| 8 | unconnected-(E34-Pad8) |  |
| 9 | unconnected-(E34-Pad9) |  |
| 10 | unconnected-(E34-Pad10) |  |
| 11 | DACK- | E56/15 |
| 12 | SIG- | E107/6 |
| 13 | BUSAKB- | E6/1, E6/19, E13/1, E16/5, E18/1, E18/19, E22/5, E33/14, J2/17 |
| 14 | 5V | *(see Power Nets)* |

## E35

| Pin | Net | Connected to |
|--|--|--|
| 1 | _NET_190 | E21/2 |
| 2 | RDI- | E15/7, E30/32, E31/32, E38/13, E40/13, E56/2, E63/35, E67/6, E82/13, E91/2 |
| 3 | WRI- | E22/4, E29/1, E29/19, E56/3, E91/5, E94/5, E107/3, R51/1 |
| 4 | _NET_191 | E21/5, R21/1 |
| 5 | A0I | E7/14, E8/13, E30/33, E31/33, E50/8, E51/8, E56/5, E63/5, E67/18 |
| 6 | A1I | E7/5, E8/4, E30/34, E31/34, E50/7, E51/7, E63/6, E67/19 |
| 7 | A2I | E7/9, E8/8, E50/6, E51/6 |
| 8 | A3I | E7/16, E8/15, E50/5, E51/5, E68/1, E69/1 |
| 9 | A4I | E7/12, E8/11, E50/4, E51/4, E68/2, E69/2 |
| 10 | _NET_192 | C22/1, Y2/2 |
| 11 | _NET_193 | C21/2, Y2/1 |
| 12 | GND | *(see Power Nets)* |
| 13 | _NET_194 | E9/9 |
| 14 | unconnected-(E35-Pad14) |  |
| 15 | D0 | C11/2, E12/3, E14/13, E29/8, E30/40, E31/40, E32/14, E33/35, E39/14, E50/9, E51/9, E56/6, E61/2, E63/19, E65/8, E65/9, E66/8, E67/25, E87/2 |
| 16 | DABUS1 | C12/2, E12/18, E29/11, E30/1, E31/1, E32/15, E33/34, E39/16, E50/10, E51/10, E56/7, E63/20, E65/4, E65/5, E66/4, E67/26, E74/2, E101/2 |
| 17 | DABUS2 | C13/2, E12/5, E29/6, E30/39, E31/39, E32/12, E33/33, E39/18, E50/11, E51/11, E56/8, E62/2, E63/1, E65/2, E65/3, E66/2, E67/27, E88/2 |
| 18 | DABUS3 | C16/1, E12/16, E29/13, E30/2, E31/2, E32/8, E33/32, E39/3, E50/13, E51/13, E56/9, E63/40, E65/16, E65/17, E66/15, E67/28, E71/2, E98/2 |
| 19 | DABUS4 | C14/2, E12/7, E29/4, E30/38, E31/38, E32/7, E33/31, E39/5, E50/14, E51/14, E56/10, E59/2, E63/39, E65/14, E65/15, E66/13, E67/1, E85/2 |
| 20 | DABUS5 | C15/1, E12/14, E29/15, E30/3, E31/3, E32/9, E33/29, E39/7, E50/15, E51/15, E56/11, E63/38, E65/6, E65/7, E66/6, E67/2, E72/2, E99/2 |
| 21 | DABUS6 | C10/1, E12/9, E29/2, E30/37, E31/37, E32/10, E33/28, E39/9, E50/16, E51/16, E56/12, E60/2, E63/3, E65/18, E65/19, E66/17, E67/3, E86/2 |
| 22 | DABUS7 | C9/1, E12/12, E29/17, E30/4, E31/4, E32/13, E33/27, E39/12, E50/17, E51/17, E56/13, E63/2, E65/12, E65/13, E66/11, E67/4, E73/2, E100/2 |
| 23 | RESET | R200/1, R201/1 |
| 24 | _NET_195 | R26/1, V3/1, V4/1 |

## E36

| Pin | Net | Connected to |
|--|--|--|
| 1 | ROMSEL- | E10/8, E40/12 |
| 2 | _NET_62 | E41/2 |
| 3 | _NET_64 | E36/12 |
| 4 | _NET_63 | E41/1 |
| 5 | MUX+ | E8/1, E8/19, E25/11, E25/12 |
| 6 | MUX- | E20/1, E20/19 |
| 7 | GND | *(see Power Nets)* |
| 8 | _NET_55 | E24/1 |
| 9 | _NET_56 | E24/6, E41/10 |
| 10 | _NET_61 | E38/10 |
| 11 | RFSHB- | E10/3, E15/18, E41/5, J2/39, R7/2 |
| 12 | _NET_64 | E36/3 |
| 13 | MREQB- | E2/3, E13/18, E16/13, E41/4, J2/25 |
| 14 | 5V | *(see Power Nets)* |

## E37

| Pin | Net | Connected to |
|--|--|--|
| 1 | _NET_235 | E56/26 |
| 2 | MFM- | E48/15, E97/1 |
| 3 | A6I | E7/18, E8/17, E50/2, E51/2, E69/5 |
| 4 | _NET_52 | E68/5 |
| 5 | DMARQ- | J2/18, R1/2 |
| 6 | _NET_205 | E34/1 |
| 7 | GND | *(see Power Nets)* |
| 8 | _NET_242 | E48/8 |
| 9 | _NET_240 | E56/24 |
| 10 | _NET_51 | E68/4, E69/4 |
| 11 | _NET_46 | C110/2, E24/11 |
| 12 | _NET_257 | E81/5, E81/6, E108/12 |
| 13 | INT1- | E33/37, R36/1 |
| 14 | 5V | *(see Power Nets)* |

## E38

| Pin | Net | Connected to |
|--|--|--|
| 1 | BANK2- | E41/8 |
| 2 | _NET_57 | E38/5, E41/3 |
| 3 | _NET_59 | E23/1 |
| 4 | BANK1- | C103/2, E24/3 |
| 5 | _NET_57 | E38/2, E41/3 |
| 6 | _NET_65 | E23/10 |
| 7 | GND | *(see Power Nets)* |
| 8 | SIGN1- | E25/13, E38/12 |
| 9 | _NET_60 | E84/6 |
| 10 | _NET_61 | E36/10 |
| 11 | _NET_90 | E83/2 |
| 12 | SIGN1- | E25/13, E38/8 |
| 13 | RDI- | E15/7, E30/32, E31/32, E35/2, E40/13, E56/2, E63/35, E67/6, E82/13, E91/2 |
| 14 | 5V | *(see Power Nets)* |

## E39

| Pin | Net | Connected to |
|--|--|--|
| 1 | _NET_89 | E39/19, E83/5 |
| 2 | D02 | E62/14, E88/14 |
| 3 | DABUS3 | C16/1, E12/16, E29/13, E30/2, E31/2, E32/8, E33/32, E35/18, E50/13, E51/13, E56/9, E63/40, E65/16, E65/17, E66/15, E67/28, E71/2, E98/2 |
| 4 | D01 | E74/14, E101/14 |
| 5 | DABUS4 | C14/2, E12/7, E29/4, E30/38, E31/38, E32/7, E33/31, E35/19, E50/14, E51/14, E56/10, E59/2, E63/39, E65/14, E65/15, E66/13, E67/1, E85/2 |
| 6 | D00 | E61/14, E87/14 |
| 7 | DABUS5 | C15/1, E12/14, E29/15, E30/3, E31/3, E32/9, E33/29, E35/20, E50/15, E51/15, E56/11, E63/38, E65/6, E65/7, E66/6, E67/2, E72/2, E99/2 |
| 8 | D07 | E73/14, E100/14 |
| 9 | DABUS6 | C10/1, E12/9, E29/2, E30/37, E31/37, E32/10, E33/28, E35/21, E50/16, E51/16, E56/12, E60/2, E63/3, E65/18, E65/19, E66/17, E67/3, E86/2 |
| 10 | GND | *(see Power Nets)* |
| 11 | D06 | E60/14, E86/14 |
| 12 | DABUS7 | C9/1, E12/12, E29/17, E30/4, E31/4, E32/13, E33/27, E35/22, E50/17, E51/17, E56/13, E63/2, E65/12, E65/13, E66/11, E67/4, E73/2, E100/2 |
| 13 | D05 | E72/14, E99/14 |
| 14 | D0 | C11/2, E12/3, E14/13, E29/8, E30/40, E31/40, E32/14, E33/35, E35/15, E50/9, E51/9, E56/6, E61/2, E63/19, E65/8, E65/9, E66/8, E67/25, E87/2 |
| 15 | D04 | E59/14, E85/14 |
| 16 | DABUS1 | C12/2, E12/18, E29/11, E30/1, E31/1, E32/15, E33/34, E35/16, E50/10, E51/10, E56/7, E63/20, E65/4, E65/5, E66/4, E67/26, E74/2, E101/2 |
| 17 | D03 | E71/14, E98/14 |
| 18 | DABUS2 | C13/2, E12/5, E29/6, E30/39, E31/39, E32/12, E33/33, E35/17, E50/11, E51/11, E56/8, E62/2, E63/1, E65/2, E65/3, E66/2, E67/27, E88/2 |
| 19 | _NET_89 | E39/1, E83/5 |
| 20 | 5V | *(see Power Nets)* |

## E40

| Pin | Net | Connected to |
|--|--|--|
| 1 | ROM1- | E51/18, E51/20 |
| 2 | ROM2- | E50/18, E50/20 |
| 3 | unconnected-(E40-Pad3) |  |
| 4 | unconnected-(E40-Pad4) |  |
| 5 | unconnected-(E40-Pad5) |  |
| 6 | unconnected-(E40-Pad6) |  |
| 7 | unconnected-(E40-Pad7) |  |
| 8 | GND | *(see Power Nets)* |
| 9 | unconnected-(E40-Pad9) |  |
| 10 | unconnected-(E40-Pad10) |  |
| 11 | unconnected-(E40-Pad11) |  |
| 12 | ROMSEL- | E10/8, E36/1 |
| 13 | RDI- | E15/7, E30/32, E31/32, E35/2, E38/13, E56/2, E63/35, E67/6, E82/13, E91/2 |
| 14 | A12I | E19/12, E20/11 |
| 15 | A11I | E19/16, E20/15 |
| 16 | 5V | *(see Power Nets)* |

## E41

| Pin | Net | Connected to |
|--|--|--|
| 1 | _NET_63 | E36/4 |
| 2 | _NET_62 | E36/2 |
| 3 | _NET_57 | E38/2, E38/5 |
| 4 | MREQB- | E2/3, E13/18, E16/13, E36/13, J2/25 |
| 5 | RFSHB- | E10/3, E15/18, E36/11, J2/39, R7/2 |
| 6 | _NET_58 | E23/2, E23/9 |
| 7 | GND | *(see Power Nets)* |
| 8 | BANK2- | E38/1 |
| 9 | BANKA2- | E11/9 |
| 10 | _NET_56 | E24/6, E36/9 |
| 11 | unconnected-(E41-Pad11) |  |
| 12 | unconnected-(E41-Pad12) |  |
| 13 | unconnected-(E41-Pad13) |  |
| 14 | 5V | *(see Power Nets)* |

## E42

| Pin | Net | Connected to |
|--|--|--|
| 1 | KAWDATA- | J1/30, J4/46, R42/1 |
| 2 | _NET_256 | E58/10 |
| 3 | INDEX- | J1/8, J4/20, R40/1 |
| 4 | _NET_233 | E56/17 |
| 5 | TWOSIDE- | JJ50/2, R38/1 |
| 6 | _NET_252 | E49/3 |
| 7 | GND | *(see Power Nets)* |
| 8 | _NET_232 | E56/35 |
| 9 | READY- | J4/22, JJ50/4, R37/1 |
| 10 | _NET_255 | E49/6 |
| 11 | TR00- | J1/26, J4/42, R39/1 |
| 12 | _NET_253 | E49/2 |
| 13 | WRPROT- | J1/28, J4/44, R41/1 |
| 14 | 5V | *(see Power Nets)* |

## E43

| Pin | Net | Connected to |
|--|--|--|
| 1 | -12V | *(see Power Nets)* |
| 2 | _NET_95 | E30/25 |
| 3 | TXD2 | J7/3 |
| 4 | _NET_96 | E30/24 |
| 5 | 5V | *(see Power Nets)* |
| 6 | RTS2 | J7/7 |
| 7 | GND | *(see Power Nets)* |
| 8 | TXD4 | J9/3 |
| 9 | _NET_108 | E31/25 |
| 10 | 5V | *(see Power Nets)* |
| 11 | RTS4 | J9/7 |
| 12 | _NET_109 | E31/24 |
| 13 | 5V | *(see Power Nets)* |
| 14 | 12V | *(see Power Nets)* |

## E44

| Pin | Net | Connected to |
|--|--|--|
| 1 | -12V | *(see Power Nets)* |
| 2 | unconnected-(E44-Pad2) |  |
| 3 | unconnected-(E44-Pad3) |  |
| 4 | unconnected-(E44-Pad4) |  |
| 5 | unconnected-(E44-Pad5) |  |
| 6 | unconnected-(E44-Pad6) |  |
| 7 | GND | *(see Power Nets)* |
| 8 | TXD3 | J8/3 |
| 9 | _NET_103 | E31/15 |
| 10 | 5V | *(see Power Nets)* |
| 11 | RTS3 | J8/7 |
| 12 | _NET_104 | E31/17 |
| 13 | 5V | *(see Power Nets)* |
| 14 | 12V | *(see Power Nets)* |

## E45

| Pin | Net | Connected to |
|--|--|--|
| 1 | RXD2 | J7/5 |
| 2 | unconnected-(E45-Pad2) |  |
| 3 | _NET_94 | E30/28 |
| 4 | CTS2 | J7/9 |
| 5 | unconnected-(E45-Pad5) |  |
| 6 | _NET_99 | E46/10 |
| 7 | GND | *(see Power Nets)* |
| 8 | _NET_100 | E46/13, E46/9 |
| 9 | unconnected-(E45-Pad9) |  |
| 10 | DSR2 | J7/11 |
| 11 | _NET_101 | E46/12 |
| 12 | unconnected-(E45-Pad12) |  |
| 13 | DCD2 | J7/15 |
| 14 | 5V | *(see Power Nets)* |

## E46

| Pin | Net | Connected to |
|--|--|--|
| 1 | unconnected-(E46-Pad1) |  |
| 2 | unconnected-(E46-Pad2) |  |
| 3 | unconnected-(E46-Pad3) |  |
| 4 | _NET_92 | E30/15, E46/5 |
| 5 | _NET_92 | E30/15, E46/4 |
| 6 | TXD1 | J5/3 |
| 7 | GND | *(see Power Nets)* |
| 8 | _NET_97 | E30/23 |
| 9 | _NET_100 | E45/8, E46/13 |
| 10 | _NET_99 | E45/6 |
| 11 | _NET_98 | E30/22 |
| 12 | _NET_101 | E45/11 |
| 13 | _NET_100 | E45/8, E46/9 |
| 14 | 5V | *(see Power Nets)* |

## E47

| Pin | Net | Connected to |
|--|--|--|
| 1 | CTCIEO | E33/38, E47/10, E47/13, E47/4, E67/11 |
| 2 | DMAIEO | E33/36 |
| 3 | SIOIEI1 | E30/6, E55/1 |
| 4 | CTCIEO | E33/38, E47/1, E47/10, E47/13, E67/11 |
| 5 | SIOIEO1 | E30/7 |
| 6 | SIOIEI2 | E31/6, E55/2 |
| 7 | GND | *(see Power Nets)* |
| 8 | _NET_197 | E55/5 |
| 9 | PIOIEO | E63/22 |
| 10 | CTCIEO | E33/38, E47/1, E47/13, E47/4, E67/11 |
| 11 | PIOIEI | E55/4, E63/24 |
| 12 | SIOIEO2 | E31/7 |
| 13 | CTCIEO | E33/38, E47/1, E47/10, E47/4, E67/11 |
| 14 | 5V | *(see Power Nets)* |

## E48

| Pin | Net | Connected to |
|--|--|--|
| 1 | _NET_241 | E56/30 |
| 2 | _NET_246 | E57/5 |
| 3 | _NET_245 | E57/3 |
| 4 | _NET_247 | E57/7 |
| 5 | _NET_243 | E57/11 |
| 6 | _NET_248 | E27/10, E27/9 |
| 7 | _NET_237 | E26/10, E26/9, E56/25 |
| 8 | _NET_242 | E37/8 |
| 9 | unconnected-(E48-Pad9) |  |
| 10 | GND | *(see Power Nets)* |
| 11 | _NET_249 | E58/12 |
| 12 | _NET_236 | E56/22 |
| 13 | _NET_251 | C301/2, E48/14, E70/1, R87/2, R88/1 |
| 14 | _NET_251 | C301/2, E48/13, E70/1, R87/2, R88/1 |
| 15 | MFM- | E37/2, E97/1 |
| 16 | _NET_250 | E70/10 |
| 17 | _NET_238 | E56/32 |
| 18 | _NET_239 | E56/31 |
| 19 | _NET_244 | E57/1 |
| 20 | 5V | *(see Power Nets)* |

## E49

| Pin | Net | Connected to |
|--|--|--|
| 1 | SEEK | E27/13, E27/2, E56/39, E82/9 |
| 2 | _NET_253 | E42/12 |
| 3 | _NET_252 | E42/6 |
| 4 | _NET_231 | E56/34 |
| 5 | _NET_254 | E2/8 |
| 6 | _NET_255 | E42/10 |
| 7 | _NET_230 | E56/33 |
| 8 | GND | *(see Power Nets)* |
| 9 | unconnected-(E49-Pad9) |  |
| 10 | unconnected-(E49-Pad10) |  |
| 11 | unconnected-(E49-Pad11) |  |
| 12 | unconnected-(E49-Pad12) |  |
| 13 | unconnected-(E49-Pad13) |  |
| 14 | unconnected-(E49-Pad14) |  |
| 15 | GND | *(see Power Nets)* |
| 16 | 5V | *(see Power Nets)* |

## E50

| Pin | Net | Connected to |
|--|--|--|
| 1 | A7I | E7/3, E8/2, E51/1, E68/6, E69/6 |
| 2 | A6I | E7/18, E8/17, E37/3, E51/2, E69/5 |
| 3 | A5I | E7/7, E8/6, E51/3, E68/3, E69/3 |
| 4 | A4I | E7/12, E8/11, E35/9, E51/4, E68/2, E69/2 |
| 5 | A3I | E7/16, E8/15, E35/8, E51/5, E68/1, E69/1 |
| 6 | A2I | E7/9, E8/8, E35/7, E51/6 |
| 7 | A1I | E7/5, E8/4, E30/34, E31/34, E35/6, E51/7, E63/6, E67/19 |
| 8 | A0I | E7/14, E8/13, E30/33, E31/33, E35/5, E51/8, E56/5, E63/5, E67/18 |
| 9 | D0 | C11/2, E12/3, E14/13, E29/8, E30/40, E31/40, E32/14, E33/35, E35/15, E39/14, E51/9, E56/6, E61/2, E63/19, E65/8, E65/9, E66/8, E67/25, E87/2 |
| 10 | DABUS1 | C12/2, E12/18, E29/11, E30/1, E31/1, E32/15, E33/34, E35/16, E39/16, E51/10, E56/7, E63/20, E65/4, E65/5, E66/4, E67/26, E74/2, E101/2 |
| 11 | DABUS2 | C13/2, E12/5, E29/6, E30/39, E31/39, E32/12, E33/33, E35/17, E39/18, E51/11, E56/8, E62/2, E63/1, E65/2, E65/3, E66/2, E67/27, E88/2 |
| 12 | GND | *(see Power Nets)* |
| 13 | DABUS3 | C16/1, E12/16, E29/13, E30/2, E31/2, E32/8, E33/32, E35/18, E39/3, E51/13, E56/9, E63/40, E65/16, E65/17, E66/15, E67/28, E71/2, E98/2 |
| 14 | DABUS4 | C14/2, E12/7, E29/4, E30/38, E31/38, E32/7, E33/31, E35/19, E39/5, E51/14, E56/10, E59/2, E63/39, E65/14, E65/15, E66/13, E67/1, E85/2 |
| 15 | DABUS5 | C15/1, E12/14, E29/15, E30/3, E31/3, E32/9, E33/29, E35/20, E39/7, E51/15, E56/11, E63/38, E65/6, E65/7, E66/6, E67/2, E72/2, E99/2 |
| 16 | DABUS6 | C10/1, E12/9, E29/2, E30/37, E31/37, E32/10, E33/28, E35/21, E39/9, E51/16, E56/12, E60/2, E63/3, E65/18, E65/19, E66/17, E67/3, E86/2 |
| 17 | DABUS7 | C9/1, E12/12, E29/17, E30/4, E31/4, E32/13, E33/27, E35/22, E39/12, E51/17, E56/13, E63/2, E65/12, E65/13, E66/11, E67/4, E73/2, E100/2 |
| 18 | ROM2- | E40/2, E50/20 |
| 19 | A10I | E19/9, E20/8, E51/19 |
| 20 | ROM2- | E40/2, E50/18 |
| 21 | 5V | *(see Power Nets)* |
| 22 | A9I | E19/5, E20/4, E51/22 |
| 23 | A8I | E19/14, E20/13, E51/23 |
| 24 | 5V | *(see Power Nets)* |

## E51

| Pin | Net | Connected to |
|--|--|--|
| 1 | A7I | E7/3, E8/2, E50/1, E68/6, E69/6 |
| 2 | A6I | E7/18, E8/17, E37/3, E50/2, E69/5 |
| 3 | A5I | E7/7, E8/6, E50/3, E68/3, E69/3 |
| 4 | A4I | E7/12, E8/11, E35/9, E50/4, E68/2, E69/2 |
| 5 | A3I | E7/16, E8/15, E35/8, E50/5, E68/1, E69/1 |
| 6 | A2I | E7/9, E8/8, E35/7, E50/6 |
| 7 | A1I | E7/5, E8/4, E30/34, E31/34, E35/6, E50/7, E63/6, E67/19 |
| 8 | A0I | E7/14, E8/13, E30/33, E31/33, E35/5, E50/8, E56/5, E63/5, E67/18 |
| 9 | D0 | C11/2, E12/3, E14/13, E29/8, E30/40, E31/40, E32/14, E33/35, E35/15, E39/14, E50/9, E56/6, E61/2, E63/19, E65/8, E65/9, E66/8, E67/25, E87/2 |
| 10 | DABUS1 | C12/2, E12/18, E29/11, E30/1, E31/1, E32/15, E33/34, E35/16, E39/16, E50/10, E56/7, E63/20, E65/4, E65/5, E66/4, E67/26, E74/2, E101/2 |
| 11 | DABUS2 | C13/2, E12/5, E29/6, E30/39, E31/39, E32/12, E33/33, E35/17, E39/18, E50/11, E56/8, E62/2, E63/1, E65/2, E65/3, E66/2, E67/27, E88/2 |
| 12 | GND | *(see Power Nets)* |
| 13 | DABUS3 | C16/1, E12/16, E29/13, E30/2, E31/2, E32/8, E33/32, E35/18, E39/3, E50/13, E56/9, E63/40, E65/16, E65/17, E66/15, E67/28, E71/2, E98/2 |
| 14 | DABUS4 | C14/2, E12/7, E29/4, E30/38, E31/38, E32/7, E33/31, E35/19, E39/5, E50/14, E56/10, E59/2, E63/39, E65/14, E65/15, E66/13, E67/1, E85/2 |
| 15 | DABUS5 | C15/1, E12/14, E29/15, E30/3, E31/3, E32/9, E33/29, E35/20, E39/7, E50/15, E56/11, E63/38, E65/6, E65/7, E66/6, E67/2, E72/2, E99/2 |
| 16 | DABUS6 | C10/1, E12/9, E29/2, E30/37, E31/37, E32/10, E33/28, E35/21, E39/9, E50/16, E56/12, E60/2, E63/3, E65/18, E65/19, E66/17, E67/3, E86/2 |
| 17 | DABUS7 | C9/1, E12/12, E29/17, E30/4, E31/4, E32/13, E33/27, E35/22, E39/12, E50/17, E56/13, E63/2, E65/12, E65/13, E66/11, E67/4, E73/2, E100/2 |
| 18 | ROM1- | E40/1, E51/20 |
| 19 | A10I | E19/9, E20/8, E50/19 |
| 20 | ROM1- | E40/1, E51/18 |
| 21 | 5V | *(see Power Nets)* |
| 22 | A9I | E19/5, E20/4, E50/22 |
| 23 | A8I | E19/14, E20/13, E50/23 |
| 24 | 5V | *(see Power Nets)* |

## E52

| Pin | Net | Connected to |
|--|--|--|
| 1 | RXD3 | J8/5 |
| 2 | unconnected-(E52-Pad2) |  |
| 3 | _NET_102 | E31/12 |
| 4 | CTS3 | J8/9 |
| 5 | unconnected-(E52-Pad5) |  |
| 6 | _NET_112 | E54/10 |
| 7 | GND | *(see Power Nets)* |
| 8 | _NET_113 | E54/13, E54/9 |
| 9 | unconnected-(E52-Pad9) |  |
| 10 | DSR3 | J8/11 |
| 11 | _NET_114 | E54/12 |
| 12 | unconnected-(E52-Pad12) |  |
| 13 | DCD3 | J8/15 |
| 14 | 5V | *(see Power Nets)* |

## E53

| Pin | Net | Connected to |
|--|--|--|
| 1 | RXD4 | J9/5 |
| 2 | unconnected-(E53-Pad2) |  |
| 3 | _NET_107 | E31/28 |
| 4 | DSR4 | J9/11 |
| 5 | unconnected-(E53-Pad5) |  |
| 6 | _NET_116 | E54/1, E54/5 |
| 7 | GND | *(see Power Nets)* |
| 8 | _NET_115 | E54/2 |
| 9 | unconnected-(E53-Pad9) |  |
| 10 | CTS4 | J9/9 |
| 11 | _NET_117 | E54/4 |
| 12 | unconnected-(E53-Pad12) |  |
| 13 | DCD4 | J9/15 |
| 14 | unconnected-(E53-Pad14) |  |

## E54

| Pin | Net | Connected to |
|--|--|--|
| 1 | _NET_116 | E53/6, E54/5 |
| 2 | _NET_115 | E53/8 |
| 3 | _NET_110 | E31/23 |
| 4 | _NET_117 | E53/11 |
| 5 | _NET_116 | E53/6, E54/1 |
| 6 | _NET_111 | E31/22 |
| 7 | GND | *(see Power Nets)* |
| 8 | _NET_105 | E31/18 |
| 9 | _NET_113 | E52/8, E54/13 |
| 10 | _NET_112 | E52/6 |
| 11 | _NET_106 | E31/19 |
| 12 | _NET_114 | E52/11 |
| 13 | _NET_113 | E52/8, E54/9 |
| 14 | 5V | *(see Power Nets)* |

## E55

| Pin | Net | Connected to |
|--|--|--|
| 1 | SIOIEI1 | E30/6, E47/3 |
| 2 | SIOIEI2 | E31/6, E47/6 |
| 3 | unconnected-(E55-Pad3) |  |
| 4 | PIOIEI | E47/11, E63/24 |
| 5 | _NET_197 | E47/8 |
| 6 | _NET_202 | E94/3 |
| 7 | GND | *(see Power Nets)* |
| 8 | _NET_208 | E21/1 |
| 9 | SEL8- | E69/7 |
| 10 | SEL5- | E69/11 |
| 11 | unconnected-(E55-Pad11) |  |
| 12 | SEL6- | E69/10 |
| 13 | SEL7- | E69/9 |
| 14 | 5V | *(see Power Nets)* |

## E56

| Pin | Net | Connected to |
|--|--|--|
| 1 | RESET+ | E4/5, E91/13, E95/3 |
| 2 | RDI- | E15/7, E30/32, E31/32, E35/2, E38/13, E40/13, E63/35, E67/6, E82/13, E91/2 |
| 3 | WRI- | E22/4, E29/1, E29/19, E35/3, E91/5, E94/5, E107/3, R51/1 |
| 4 | SEL15- | E68/9 |
| 5 | A0I | E7/14, E8/13, E30/33, E31/33, E35/5, E50/8, E51/8, E63/5, E67/18 |
| 6 | D0 | C11/2, E12/3, E14/13, E29/8, E30/40, E31/40, E32/14, E33/35, E35/15, E39/14, E50/9, E51/9, E61/2, E63/19, E65/8, E65/9, E66/8, E67/25, E87/2 |
| 7 | DABUS1 | C12/2, E12/18, E29/11, E30/1, E31/1, E32/15, E33/34, E35/16, E39/16, E50/10, E51/10, E63/20, E65/4, E65/5, E66/4, E67/26, E74/2, E101/2 |
| 8 | DABUS2 | C13/2, E12/5, E29/6, E30/39, E31/39, E32/12, E33/33, E35/17, E39/18, E50/11, E51/11, E62/2, E63/1, E65/2, E65/3, E66/2, E67/27, E88/2 |
| 9 | DABUS3 | C16/1, E12/16, E29/13, E30/2, E31/2, E32/8, E33/32, E35/18, E39/3, E50/13, E51/13, E63/40, E65/16, E65/17, E66/15, E67/28, E71/2, E98/2 |
| 10 | DABUS4 | C14/2, E12/7, E29/4, E30/38, E31/38, E32/7, E33/31, E35/19, E39/5, E50/14, E51/14, E59/2, E63/39, E65/14, E65/15, E66/13, E67/1, E85/2 |
| 11 | DABUS5 | C15/1, E12/14, E29/15, E30/3, E31/3, E32/9, E33/29, E35/20, E39/7, E50/15, E51/15, E63/38, E65/6, E65/7, E66/6, E67/2, E72/2, E99/2 |
| 12 | DABUS6 | C10/1, E12/9, E29/2, E30/37, E31/37, E32/10, E33/28, E35/21, E39/9, E50/16, E51/16, E60/2, E63/3, E65/18, E65/19, E66/17, E67/3, E86/2 |
| 13 | DABUS7 | C9/1, E12/12, E29/17, E30/4, E31/4, E32/13, E33/27, E35/22, E39/12, E50/17, E51/17, E63/2, E65/12, E65/13, E66/11, E67/4, E73/2, E100/2 |
| 14 | DRQ+ | E82/1 |
| 15 | DACK- | E34/11 |
| 16 | _NET_228 | E108/11 |
| 17 | _NET_233 | E42/4 |
| 18 | FDINT+ | E106/3 |
| 19 | CLK | E83/9, E96/1, JJ11/1, JJ11/11, JJ11/12, R204/2 |
| 20 | GND | *(see Power Nets)* |
| 21 | _NET_229 | E97/4 |
| 22 | _NET_236 | E48/12 |
| 23 | _NET_234 | E58/5 |
| 24 | _NET_240 | E37/9 |
| 25 | _NET_237 | E26/10, E26/9, E48/7 |
| 26 | _NET_235 | E37/1 |
| 27 | HDSEL | E26/12, E26/13 |
| 28 | DS1 | E22/11, E26/1, E28/1 |
| 29 | DS0 | E26/4, E28/2, E82/11 |
| 30 | _NET_241 | E48/1 |
| 31 | _NET_239 | E48/18 |
| 32 | _NET_238 | E48/17 |
| 33 | _NET_230 | E49/7 |
| 34 | _NET_231 | E49/4 |
| 35 | _NET_232 | E42/8 |
| 36 | HDL | E28/10, E28/9 |
| 37 | FR-STP | E27/12, E28/12 |
| 38 | LC-DIR | E27/1 |
| 39 | SEEK | E27/13, E27/2, E49/1, E82/9 |
| 40 | 5V | *(see Power Nets)* |

## E57

| Pin | Net | Connected to |
|--|--|--|
| 1 | _NET_244 | E48/19 |
| 2 | unconnected-(E57-Pad2) |  |
| 3 | _NET_245 | E48/3 |
| 4 | unconnected-(E57-Pad4) |  |
| 5 | _NET_246 | E48/2 |
| 6 | unconnected-(E57-Pad6) |  |
| 7 | _NET_247 | E48/4 |
| 8 | unconnected-(E57-Pad8) |  |
| 9 | GND | *(see Power Nets)* |
| 10 | unconnected-(E57-Pad10) |  |
| 11 | _NET_243 | E48/5 |
| 12 | unconnected-(E57-Pad12) |  |
| 13 | unconnected-(E57-Pad13) |  |
| 14 | unconnected-(E57-Pad14) |  |
| 15 | unconnected-(E57-Pad15) |  |
| 16 | unconnected-(E57-Pad16) |  |
| 17 | _NET_271 | CX30/1, R94/2 |
| 18 | 5V | *(see Power Nets)* |

## E58

| Pin | Net | Connected to |
|--|--|--|
| 1 | unconnected-(E58-Pad1) |  |
| 2 | unconnected-(E58-Pad2) |  |
| 3 | unconnected-(E58-Pad3) |  |
| 4 | unconnected-(E58-Pad4) |  |
| 5 | _NET_234 | E56/23 |
| 6 | _NET_272 | C17/1 |
| 7 | _NET_273 | C17/2, R53/2 |
| 8 | GND | *(see Power Nets)* |
| 9 | GND | *(see Power Nets)* |
| 10 | _NET_256 | E42/2 |
| 11 | 5V | *(see Power Nets)* |
| 12 | _NET_249 | E48/11 |
| 13 | unconnected-(E58-Pad13) |  |
| 14 | unconnected-(E58-Pad14) |  |
| 15 | unconnected-(E58-Pad15) |  |
| 16 | 5V | *(see Power Nets)* |

## E59

| Pin | Net | Connected to |
|--|--|--|
| 1 | unconnected-(E59-Pad1) |  |
| 2 | DABUS4 | C14/2, E12/7, E29/4, E30/38, E31/38, E32/7, E33/31, E35/19, E39/5, E50/14, E51/14, E56/10, E63/39, E65/14, E65/15, E66/13, E67/1, E85/2 |
| 3 | _NET_80 | E60/3, E61/3, E62/3, E71/3, E72/3, E73/3, E74/3, E85/3, E86/3, E87/3, E88/3, E98/3, E99/3, E100/3, E101/3, R51/2 |
| 4 | RAS1- | E23/8, E60/4, E61/4, E62/4, E71/4, E72/4, E73/4, E74/4, E84/4 |
| 5 | _NET_72 | E60/5, E61/5, E62/5, E71/5, E72/5, E73/5, E74/5, E85/5, E86/5, E87/5, E88/5, E98/5, E99/5, E100/5, E101/5, R48/2 |
| 6 | _NET_74 | E60/6, E61/6, E62/6, E71/6, E72/6, E73/6, E74/6, E85/6, E86/6, E87/6, E88/6, E98/6, E99/6, E100/6, E101/6, R46/2 |
| 7 | _NET_73 | E60/7, E61/7, E62/7, E71/7, E72/7, E73/7, E74/7, E85/7, E86/7, E87/7, E88/7, E98/7, E99/7, E100/7, E101/7, R44/2 |
| 8 | 5V | *(see Power Nets)* |
| 9 | _NET_79 | E60/9, E61/9, E62/9, E71/9, E72/9, E73/9, E74/9, E85/9, E86/9, E87/9, E88/9, E98/9, E99/9, E100/9, E101/9, R43/2 |
| 10 | _NET_77 | E60/10, E61/10, E62/10, E71/10, E72/10, E73/10, E74/10, E85/10, E86/10, E87/10, E88/10, E98/10, E99/10, E100/10, E101/10, R45/2 |
| 11 | _NET_76 | E60/11, E61/11, E62/11, E71/11, E72/11, E73/11, E74/11, E85/11, E86/11, E87/11, E88/11, E98/11, E99/11, E100/11, E101/11, R47/2 |
| 12 | _NET_75 | E60/12, E61/12, E62/12, E71/12, E72/12, E73/12, E74/12, E85/12, E86/12, E87/12, E88/12, E98/12, E99/12, E100/12, E101/12, R49/2 |
| 13 | _NET_78 | E60/13, E61/13, E62/13, E71/13, E72/13, E73/13, E74/13, E85/13, E86/13, E87/13, E88/13, E98/13, E99/13, E100/13, E101/13, R50/2 |
| 14 | D04 | E39/15, E85/14 |
| 15 | CAS- | E60/15, E61/15, E62/15, E71/15, E72/15, E73/15, E74/15, E85/15, E86/15, E87/15, E88/15, E98/15, E99/15, E100/15, E101/15, R52/2 |
| 16 | GND | *(see Power Nets)* |

## E60

| Pin | Net | Connected to |
|--|--|--|
| 1 | unconnected-(E60-Pad1) |  |
| 2 | DABUS6 | C10/1, E12/9, E29/2, E30/37, E31/37, E32/10, E33/28, E35/21, E39/9, E50/16, E51/16, E56/12, E63/3, E65/18, E65/19, E66/17, E67/3, E86/2 |
| 3 | _NET_80 | E59/3, E61/3, E62/3, E71/3, E72/3, E73/3, E74/3, E85/3, E86/3, E87/3, E88/3, E98/3, E99/3, E100/3, E101/3, R51/2 |
| 4 | RAS1- | E23/8, E59/4, E61/4, E62/4, E71/4, E72/4, E73/4, E74/4, E84/4 |
| 5 | _NET_72 | E59/5, E61/5, E62/5, E71/5, E72/5, E73/5, E74/5, E85/5, E86/5, E87/5, E88/5, E98/5, E99/5, E100/5, E101/5, R48/2 |
| 6 | _NET_74 | E59/6, E61/6, E62/6, E71/6, E72/6, E73/6, E74/6, E85/6, E86/6, E87/6, E88/6, E98/6, E99/6, E100/6, E101/6, R46/2 |
| 7 | _NET_73 | E59/7, E61/7, E62/7, E71/7, E72/7, E73/7, E74/7, E85/7, E86/7, E87/7, E88/7, E98/7, E99/7, E100/7, E101/7, R44/2 |
| 8 | 5V | *(see Power Nets)* |
| 9 | _NET_79 | E59/9, E61/9, E62/9, E71/9, E72/9, E73/9, E74/9, E85/9, E86/9, E87/9, E88/9, E98/9, E99/9, E100/9, E101/9, R43/2 |
| 10 | _NET_77 | E59/10, E61/10, E62/10, E71/10, E72/10, E73/10, E74/10, E85/10, E86/10, E87/10, E88/10, E98/10, E99/10, E100/10, E101/10, R45/2 |
| 11 | _NET_76 | E59/11, E61/11, E62/11, E71/11, E72/11, E73/11, E74/11, E85/11, E86/11, E87/11, E88/11, E98/11, E99/11, E100/11, E101/11, R47/2 |
| 12 | _NET_75 | E59/12, E61/12, E62/12, E71/12, E72/12, E73/12, E74/12, E85/12, E86/12, E87/12, E88/12, E98/12, E99/12, E100/12, E101/12, R49/2 |
| 13 | _NET_78 | E59/13, E61/13, E62/13, E71/13, E72/13, E73/13, E74/13, E85/13, E86/13, E87/13, E88/13, E98/13, E99/13, E100/13, E101/13, R50/2 |
| 14 | D06 | E39/11, E86/14 |
| 15 | CAS- | E59/15, E61/15, E62/15, E71/15, E72/15, E73/15, E74/15, E85/15, E86/15, E87/15, E88/15, E98/15, E99/15, E100/15, E101/15, R52/2 |
| 16 | GND | *(see Power Nets)* |

## E61

| Pin | Net | Connected to |
|--|--|--|
| 1 | unconnected-(E61-Pad1) |  |
| 2 | D0 | C11/2, E12/3, E14/13, E29/8, E30/40, E31/40, E32/14, E33/35, E35/15, E39/14, E50/9, E51/9, E56/6, E63/19, E65/8, E65/9, E66/8, E67/25, E87/2 |
| 3 | _NET_80 | E59/3, E60/3, E62/3, E71/3, E72/3, E73/3, E74/3, E85/3, E86/3, E87/3, E88/3, E98/3, E99/3, E100/3, E101/3, R51/2 |
| 4 | RAS1- | E23/8, E59/4, E60/4, E62/4, E71/4, E72/4, E73/4, E74/4, E84/4 |
| 5 | _NET_72 | E59/5, E60/5, E62/5, E71/5, E72/5, E73/5, E74/5, E85/5, E86/5, E87/5, E88/5, E98/5, E99/5, E100/5, E101/5, R48/2 |
| 6 | _NET_74 | E59/6, E60/6, E62/6, E71/6, E72/6, E73/6, E74/6, E85/6, E86/6, E87/6, E88/6, E98/6, E99/6, E100/6, E101/6, R46/2 |
| 7 | _NET_73 | E59/7, E60/7, E62/7, E71/7, E72/7, E73/7, E74/7, E85/7, E86/7, E87/7, E88/7, E98/7, E99/7, E100/7, E101/7, R44/2 |
| 8 | 5V | *(see Power Nets)* |
| 9 | _NET_79 | E59/9, E60/9, E62/9, E71/9, E72/9, E73/9, E74/9, E85/9, E86/9, E87/9, E88/9, E98/9, E99/9, E100/9, E101/9, R43/2 |
| 10 | _NET_77 | E59/10, E60/10, E62/10, E71/10, E72/10, E73/10, E74/10, E85/10, E86/10, E87/10, E88/10, E98/10, E99/10, E100/10, E101/10, R45/2 |
| 11 | _NET_76 | E59/11, E60/11, E62/11, E71/11, E72/11, E73/11, E74/11, E85/11, E86/11, E87/11, E88/11, E98/11, E99/11, E100/11, E101/11, R47/2 |
| 12 | _NET_75 | E59/12, E60/12, E62/12, E71/12, E72/12, E73/12, E74/12, E85/12, E86/12, E87/12, E88/12, E98/12, E99/12, E100/12, E101/12, R49/2 |
| 13 | _NET_78 | E59/13, E60/13, E62/13, E71/13, E72/13, E73/13, E74/13, E85/13, E86/13, E87/13, E88/13, E98/13, E99/13, E100/13, E101/13, R50/2 |
| 14 | D00 | E39/6, E87/14 |
| 15 | CAS- | E59/15, E60/15, E62/15, E71/15, E72/15, E73/15, E74/15, E85/15, E86/15, E87/15, E88/15, E98/15, E99/15, E100/15, E101/15, R52/2 |
| 16 | GND | *(see Power Nets)* |

## E62

| Pin | Net | Connected to |
|--|--|--|
| 1 | unconnected-(E62-Pad1) |  |
| 2 | DABUS2 | C13/2, E12/5, E29/6, E30/39, E31/39, E32/12, E33/33, E35/17, E39/18, E50/11, E51/11, E56/8, E63/1, E65/2, E65/3, E66/2, E67/27, E88/2 |
| 3 | _NET_80 | E59/3, E60/3, E61/3, E71/3, E72/3, E73/3, E74/3, E85/3, E86/3, E87/3, E88/3, E98/3, E99/3, E100/3, E101/3, R51/2 |
| 4 | RAS1- | E23/8, E59/4, E60/4, E61/4, E71/4, E72/4, E73/4, E74/4, E84/4 |
| 5 | _NET_72 | E59/5, E60/5, E61/5, E71/5, E72/5, E73/5, E74/5, E85/5, E86/5, E87/5, E88/5, E98/5, E99/5, E100/5, E101/5, R48/2 |
| 6 | _NET_74 | E59/6, E60/6, E61/6, E71/6, E72/6, E73/6, E74/6, E85/6, E86/6, E87/6, E88/6, E98/6, E99/6, E100/6, E101/6, R46/2 |
| 7 | _NET_73 | E59/7, E60/7, E61/7, E71/7, E72/7, E73/7, E74/7, E85/7, E86/7, E87/7, E88/7, E98/7, E99/7, E100/7, E101/7, R44/2 |
| 8 | 5V | *(see Power Nets)* |
| 9 | _NET_79 | E59/9, E60/9, E61/9, E71/9, E72/9, E73/9, E74/9, E85/9, E86/9, E87/9, E88/9, E98/9, E99/9, E100/9, E101/9, R43/2 |
| 10 | _NET_77 | E59/10, E60/10, E61/10, E71/10, E72/10, E73/10, E74/10, E85/10, E86/10, E87/10, E88/10, E98/10, E99/10, E100/10, E101/10, R45/2 |
| 11 | _NET_76 | E59/11, E60/11, E61/11, E71/11, E72/11, E73/11, E74/11, E85/11, E86/11, E87/11, E88/11, E98/11, E99/11, E100/11, E101/11, R47/2 |
| 12 | _NET_75 | E59/12, E60/12, E61/12, E71/12, E72/12, E73/12, E74/12, E85/12, E86/12, E87/12, E88/12, E98/12, E99/12, E100/12, E101/12, R49/2 |
| 13 | _NET_78 | E59/13, E60/13, E61/13, E71/13, E72/13, E73/13, E74/13, E85/13, E86/13, E87/13, E88/13, E98/13, E99/13, E100/13, E101/13, R50/2 |
| 14 | D02 | E39/2, E88/14 |
| 15 | CAS- | E59/15, E60/15, E61/15, E71/15, E72/15, E73/15, E74/15, E85/15, E86/15, E87/15, E88/15, E98/15, E99/15, E100/15, E101/15, R52/2 |
| 16 | GND | *(see Power Nets)* |

## E63

| Pin | Net | Connected to |
|--|--|--|
| 1 | DABUS2 | C13/2, E12/5, E29/6, E30/39, E31/39, E32/12, E33/33, E35/17, E39/18, E50/11, E51/11, E56/8, E62/2, E65/2, E65/3, E66/2, E67/27, E88/2 |
| 2 | DABUS7 | C9/1, E12/12, E29/17, E30/4, E31/4, E32/13, E33/27, E35/22, E39/12, E50/17, E51/17, E56/13, E65/12, E65/13, E66/11, E67/4, E73/2, E100/2 |
| 3 | DABUS6 | C10/1, E12/9, E29/2, E30/37, E31/37, E32/10, E33/28, E35/21, E39/9, E50/16, E51/16, E56/12, E60/2, E65/18, E65/19, E66/17, E67/3, E86/2 |
| 4 | SEL11- | E68/13 |
| 5 | A0I | E7/14, E8/13, E30/33, E31/33, E35/5, E50/8, E51/8, E56/5, E67/18 |
| 6 | A1I | E7/5, E8/4, E30/34, E31/34, E35/6, E50/7, E51/7, E67/19 |
| 7 | _NET_131 | E90/13, E90/14 |
| 8 | _NET_130 | E90/10, E90/11 |
| 9 | _NET_129 | E90/5, E90/6 |
| 10 | _NET_128 | E90/2, E90/3 |
| 11 | GND | *(see Power Nets)* |
| 12 | _NET_125 | E76/13, E76/14 |
| 13 | _NET_124 | E76/10, E76/11 |
| 14 | _NET_123 | E76/5, E76/6 |
| 15 | _NET_122 | E76/2, E76/3 |
| 16 | _NET_146 | E102/11, JJ3/1 |
| 17 | _NET_127 | E102/8, JJ4/1 |
| 18 | _NET_119 | E102/2 |
| 19 | D0 | C11/2, E12/3, E14/13, E29/8, E30/40, E31/40, E32/14, E33/35, E35/15, E39/14, E50/9, E51/9, E56/6, E61/2, E65/8, E65/9, E66/8, E67/25, E87/2 |
| 20 | DABUS1 | C12/2, E12/18, E29/11, E30/1, E31/1, E32/15, E33/34, E35/16, E39/16, E50/10, E51/10, E56/7, E65/4, E65/5, E66/4, E67/26, E74/2, E101/2 |
| 21 | _NET_143 | E102/5 |
| 22 | PIOIEO | E47/9 |
| 23 | INT- | E30/5, E31/5, E67/12, E81/1, E81/4, E84/2, R54/2 |
| 24 | PIOIEI | E47/11, E55/4 |
| 25 | BI | E15/3, E30/20, E31/20, E33/7, E67/15, R19/1 |
| 26 | 5V | *(see Power Nets)* |
| 27 | _NET_134 | E75/13 |
| 28 | _NET_135 | E75/10 |
| 29 | _NET_136 | E75/4 |
| 30 | _NET_137 | E75/1 |
| 31 | _NET_142 | E89/13 |
| 32 | _NET_141 | E89/10 |
| 33 | _NET_140 | E89/4 |
| 34 | _NET_139 | E89/1 |
| 35 | RDI- | E15/7, E30/32, E31/32, E35/2, E38/13, E40/13, E56/2, E67/6, E82/13, E91/2 |
| 36 | IORQB- | E10/4, E13/16, E13/17, E15/15, E15/16, E30/36, E31/36, E67/10, E105/3, J2/35 |
| 37 | M1B- | E4/3, E16/3, E24/13, E30/8, E31/8, E33/26, E67/14, E91/1, E105/4, J2/24 |
| 38 | DABUS5 | C15/1, E12/14, E29/15, E30/3, E31/3, E32/9, E33/29, E35/20, E39/7, E50/15, E51/15, E56/11, E65/6, E65/7, E66/6, E67/2, E72/2, E99/2 |
| 39 | DABUS4 | C14/2, E12/7, E29/4, E30/38, E31/38, E32/7, E33/31, E35/19, E39/5, E50/14, E51/14, E56/10, E59/2, E65/14, E65/15, E66/13, E67/1, E85/2 |
| 40 | DABUS3 | C16/1, E12/16, E29/13, E30/2, E31/2, E32/8, E33/32, E35/18, E39/3, E50/13, E51/13, E56/9, E65/16, E65/17, E66/15, E67/28, E71/2, E98/2 |

## E64

| Pin | Net | Connected to |
|--|--|--|
| 1 | _NET_148 | JJ8/1 |
| 2 | _NET_150 | JJ8/3 |
| 3 | _NET_152 | JJ8/5 |
| 4 | _NET_154 | JJ8/7 |
| 5 | _NET_155 | JJ8/8 |
| 6 | _NET_157 | JJ8/10 |
| 7 | _NET_156 | JJ8/9 |
| 8 | _NET_158 | JJ8/11 |
| 9 | _NET_160 | JJ8/14 |
| 10 | RESET- | E4/6, E11/4, E24/10, E30/21, E31/21, E32/26, E67/17, E77/1, E77/13, E103/1, E103/13, E104/10, E104/4, J2/21 |
| 11 | unconnected-(E64-Pad11) |  |
| 12 | GND | *(see Power Nets)* |
| 13 | XX1 | E67/23, JJ8/13 |
| 14 | _NET_159 | JJ8/12 |
| 15 | _NET_153 | JJ8/6 |
| 16 | _NET_151 | JJ8/4 |
| 17 | _NET_149 | JJ8/2 |
| 18 | unconnected-(E64-Pad18) |  |
| 19 | unconnected-(E64-Pad19) |  |
| 20 | _NET_161 | R202/2, Y3/2 |
| 21 | _NET_162 | R202/1, Y3/1 |
| 22 | _NET_163 | JJ9/2, R58/2 |
| 23 | _NET_164 | JJ9/1, R59/2 |
| 24 | 5V | *(see Power Nets)* |

## E65

| Pin | Net | Connected to |
|--|--|--|
| 1 | _NET_211 | E78/6 |
| 2 | DABUS2 | C13/2, E12/5, E29/6, E30/39, E31/39, E32/12, E33/33, E35/17, E39/18, E50/11, E51/11, E56/8, E62/2, E63/1, E65/3, E66/2, E67/27, E88/2 |
| 3 | DABUS2 | C13/2, E12/5, E29/6, E30/39, E31/39, E32/12, E33/33, E35/17, E39/18, E50/11, E51/11, E56/8, E62/2, E63/1, E65/2, E66/2, E67/27, E88/2 |
| 4 | DABUS1 | C12/2, E12/18, E29/11, E30/1, E31/1, E32/15, E33/34, E35/16, E39/16, E50/10, E51/10, E56/7, E63/20, E65/5, E66/4, E67/26, E74/2, E101/2 |
| 5 | DABUS1 | C12/2, E12/18, E29/11, E30/1, E31/1, E32/15, E33/34, E35/16, E39/16, E50/10, E51/10, E56/7, E63/20, E65/4, E66/4, E67/26, E74/2, E101/2 |
| 6 | DABUS5 | C15/1, E12/14, E29/15, E30/3, E31/3, E32/9, E33/29, E35/20, E39/7, E50/15, E51/15, E56/11, E63/38, E65/7, E66/6, E67/2, E72/2, E99/2 |
| 7 | DABUS5 | C15/1, E12/14, E29/15, E30/3, E31/3, E32/9, E33/29, E35/20, E39/7, E50/15, E51/15, E56/11, E63/38, E65/6, E66/6, E67/2, E72/2, E99/2 |
| 8 | D0 | C11/2, E12/3, E14/13, E29/8, E30/40, E31/40, E32/14, E33/35, E35/15, E39/14, E50/9, E51/9, E56/6, E61/2, E63/19, E65/9, E66/8, E67/25, E87/2 |
| 9 | D0 | C11/2, E12/3, E14/13, E29/8, E30/40, E31/40, E32/14, E33/35, E35/15, E39/14, E50/9, E51/9, E56/6, E61/2, E63/19, E65/8, E66/8, E67/25, E87/2 |
| 10 | GND | *(see Power Nets)* |
| 11 | _NET_212 | E91/6 |
| 12 | DABUS7 | C9/1, E12/12, E29/17, E30/4, E31/4, E32/13, E33/27, E35/22, E39/12, E50/17, E51/17, E56/13, E63/2, E65/13, E66/11, E67/4, E73/2, E100/2 |
| 13 | DABUS7 | C9/1, E12/12, E29/17, E30/4, E31/4, E32/13, E33/27, E35/22, E39/12, E50/17, E51/17, E56/13, E63/2, E65/12, E66/11, E67/4, E73/2, E100/2 |
| 14 | DABUS4 | C14/2, E12/7, E29/4, E30/38, E31/38, E32/7, E33/31, E35/19, E39/5, E50/14, E51/14, E56/10, E59/2, E63/39, E65/15, E66/13, E67/1, E85/2 |
| 15 | DABUS4 | C14/2, E12/7, E29/4, E30/38, E31/38, E32/7, E33/31, E35/19, E39/5, E50/14, E51/14, E56/10, E59/2, E63/39, E65/14, E66/13, E67/1, E85/2 |
| 16 | DABUS3 | C16/1, E12/16, E29/13, E30/2, E31/2, E32/8, E33/32, E35/18, E39/3, E50/13, E51/13, E56/9, E63/40, E65/17, E66/15, E67/28, E71/2, E98/2 |
| 17 | DABUS3 | C16/1, E12/16, E29/13, E30/2, E31/2, E32/8, E33/32, E35/18, E39/3, E50/13, E51/13, E56/9, E63/40, E65/16, E66/15, E67/28, E71/2, E98/2 |
| 18 | DABUS6 | C10/1, E12/9, E29/2, E30/37, E31/37, E32/10, E33/28, E35/21, E39/9, E50/16, E51/16, E56/12, E60/2, E63/3, E65/19, E66/17, E67/3, E86/2 |
| 19 | DABUS6 | C10/1, E12/9, E29/2, E30/37, E31/37, E32/10, E33/28, E35/21, E39/9, E50/16, E51/16, E56/12, E60/2, E63/3, E65/18, E66/17, E67/3, E86/2 |
| 20 | 5V | *(see Power Nets)* |

## E66

| Pin | Net | Connected to |
|--|--|--|
| 1 | GND | *(see Power Nets)* |
| 2 | DABUS2 | C13/2, E12/5, E29/6, E30/39, E31/39, E32/12, E33/33, E35/17, E39/18, E50/11, E51/11, E56/8, E62/2, E63/1, E65/2, E65/3, E67/27, E88/2 |
| 3 | DABUS16 | E79/11, E92/11, E93/11 |
| 4 | DABUS1 | C12/2, E12/18, E29/11, E30/1, E31/1, E32/15, E33/34, E35/16, E39/16, E50/10, E51/10, E56/7, E63/20, E65/4, E65/5, E67/26, E74/2, E101/2 |
| 5 | DABUS13 | E79/4, E92/4, E93/4 |
| 6 | DABUS5 | C15/1, E12/14, E29/15, E30/3, E31/3, E32/9, E33/29, E35/20, E39/7, E50/15, E51/15, E56/11, E63/38, E65/6, E65/7, E67/2, E72/2, E99/2 |
| 7 | DABUS14 | E80/11 |
| 8 | D0 | C11/2, E12/3, E14/13, E29/8, E30/40, E31/40, E32/14, E33/35, E35/15, E39/14, E50/9, E51/9, E56/6, E61/2, E63/19, E65/8, E65/9, E67/25, E87/2 |
| 9 | DABUS17 | E79/12, E80/3, E93/12 |
| 10 | GND | *(see Power Nets)* |
| 11 | DABUS7 | C9/1, E12/12, E29/17, E30/4, E31/4, E32/13, E33/27, E35/22, E39/12, E50/17, E51/17, E56/13, E63/2, E65/12, E65/13, E67/4, E73/2, E100/2 |
| 12 | DABUS10 | E79/1, E92/1, E93/1 |
| 13 | DABUS4 | C14/2, E12/7, E29/4, E30/38, E31/38, E32/7, E33/31, E35/19, E39/5, E50/14, E51/14, E56/10, E59/2, E63/39, E65/14, E65/15, E67/1, E85/2 |
| 14 | DABUS15 | E80/5, E93/6 |
| 15 | DABUS3 | C16/1, E12/16, E29/13, E30/2, E31/2, E32/8, E33/32, E35/18, E39/3, E50/13, E51/13, E56/9, E63/40, E65/16, E65/17, E67/28, E71/2, E98/2 |
| 16 | DABUS11 | E79/2, E80/9 |
| 17 | DABUS6 | C10/1, E12/9, E29/2, E30/37, E31/37, E32/10, E33/28, E35/21, E39/9, E50/16, E51/16, E56/12, E60/2, E63/3, E65/18, E65/19, E67/3, E86/2 |
| 18 | DABUS12 | E80/1, E92/3, E93/3 |
| 19 | GND | *(see Power Nets)* |
| 20 | 5V | *(see Power Nets)* |

## E67

| Pin | Net | Connected to |
|--|--|--|
| 1 | DABUS4 | C14/2, E12/7, E29/4, E30/38, E31/38, E32/7, E33/31, E35/19, E39/5, E50/14, E51/14, E56/10, E59/2, E63/39, E65/14, E65/15, E66/13, E85/2 |
| 2 | DABUS5 | C15/1, E12/14, E29/15, E30/3, E31/3, E32/9, E33/29, E35/20, E39/7, E50/15, E51/15, E56/11, E63/38, E65/6, E65/7, E66/6, E72/2, E99/2 |
| 3 | DABUS6 | C10/1, E12/9, E29/2, E30/37, E31/37, E32/10, E33/28, E35/21, E39/9, E50/16, E51/16, E56/12, E60/2, E63/3, E65/18, E65/19, E66/17, E86/2 |
| 4 | DABUS7 | C9/1, E12/12, E29/17, E30/4, E31/4, E32/13, E33/27, E35/22, E39/12, E50/17, E51/17, E56/13, E63/2, E65/12, E65/13, E66/11, E73/2, E100/2 |
| 5 | GND | *(see Power Nets)* |
| 6 | RDI- | E15/7, E30/32, E31/32, E35/2, E38/13, E40/13, E56/2, E63/35, E82/13, E91/2 |
| 7 | _NET_167 | E67/22 |
| 8 | XX2 | E91/12 |
| 9 | _NET_166 | JJ10/2 |
| 10 | IORQB- | E10/4, E13/16, E13/17, E15/15, E15/16, E30/36, E31/36, E63/36, E105/3, J2/35 |
| 11 | CTCIEO | E33/38, E47/1, E47/10, E47/13, E47/4 |
| 12 | INT- | E30/5, E31/5, E63/23, E81/1, E81/4, E84/2, R54/2 |
| 13 | 5V | *(see Power Nets)* |
| 14 | M1B- | E4/3, E16/3, E24/13, E30/8, E31/8, E33/26, E63/37, E91/1, E105/4, J2/24 |
| 15 | BI | E15/3, E30/20, E31/20, E33/7, E63/25, R19/1 |
| 16 | SEL10- | E68/14 |
| 17 | RESET- | E4/6, E11/4, E24/10, E30/21, E31/21, E32/26, E64/10, E77/1, E77/13, E103/1, E103/13, E104/10, E104/4, J2/21 |
| 18 | A0I | E7/14, E8/13, E30/33, E31/33, E35/5, E50/8, E51/8, E56/5, E63/5 |
| 19 | A1I | E7/5, E8/4, E30/34, E31/34, E35/6, E50/7, E51/7, E63/6 |
| 20 | _NET_165 | JJ10/1 |
| 21 | unconnected-(E67-Pad21) |  |
| 22 | _NET_167 | E67/7 |
| 23 | XX1 | E64/13, JJ8/13 |
| 24 | 5V | *(see Power Nets)* |
| 25 | D0 | C11/2, E12/3, E14/13, E29/8, E30/40, E31/40, E32/14, E33/35, E35/15, E39/14, E50/9, E51/9, E56/6, E61/2, E63/19, E65/8, E65/9, E66/8, E87/2 |
| 26 | DABUS1 | C12/2, E12/18, E29/11, E30/1, E31/1, E32/15, E33/34, E35/16, E39/16, E50/10, E51/10, E56/7, E63/20, E65/4, E65/5, E66/4, E74/2, E101/2 |
| 27 | DABUS2 | C13/2, E12/5, E29/6, E30/39, E31/39, E32/12, E33/33, E35/17, E39/18, E50/11, E51/11, E56/8, E62/2, E63/1, E65/2, E65/3, E66/2, E88/2 |
| 28 | DABUS3 | C16/1, E12/16, E29/13, E30/2, E31/2, E32/8, E33/32, E35/18, E39/3, E50/13, E51/13, E56/9, E63/40, E65/16, E65/17, E66/15, E71/2, E98/2 |

## E68

| Pin | Net | Connected to |
|--|--|--|
| 1 | A3I | E7/16, E8/15, E35/8, E50/5, E51/5, E69/1 |
| 2 | A4I | E7/12, E8/11, E35/9, E50/4, E51/4, E69/2 |
| 3 | A5I | E7/7, E8/6, E50/3, E51/3, E69/3 |
| 4 | _NET_51 | E37/10, E69/4 |
| 5 | _NET_52 | E37/4 |
| 6 | A7I | E7/3, E8/2, E50/1, E51/1, E69/6 |
| 7 | unconnected-SEL16- |  |
| 8 | GND | *(see Power Nets)* |
| 9 | SEL15- | E56/4 |
| 10 | SEL14- | E91/4 |
| 11 | SEL13- | E31/35 |
| 12 | SEL12- | E30/35 |
| 13 | SEL11- | E63/4 |
| 14 | SEL10- | E67/16 |
| 15 | SEL9- | E13/11 |
| 16 | 5V | *(see Power Nets)* |

## E69

| Pin | Net | Connected to |
|--|--|--|
| 1 | A3I | E7/16, E8/15, E35/8, E50/5, E51/5, E68/1 |
| 2 | A4I | E7/12, E8/11, E35/9, E50/4, E51/4, E68/2 |
| 3 | A5I | E7/7, E8/6, E50/3, E51/3, E68/3 |
| 4 | _NET_51 | E37/10, E68/4 |
| 5 | A6I | E7/18, E8/17, E37/3, E50/2, E51/2 |
| 6 | A7I | E7/3, E8/2, E50/1, E51/1, E68/6 |
| 7 | SEL8- | E55/9 |
| 8 | GND | *(see Power Nets)* |
| 9 | SEL7- | E55/13 |
| 10 | SEL6- | E55/12 |
| 11 | SEL5- | E55/10 |
| 12 | SEL4- | E94/11 |
| 13 | SEL3- | E11/13 |
| 14 | SEL2- | E24/9 |
| 15 | SEL1- | E11/1 |
| 16 | 5V | *(see Power Nets)* |

## E70

| Pin | Net | Connected to |
|--|--|--|
| 1 | _NET_251 | C301/2, E48/13, E48/14, R87/2, R88/1 |
| 2 | GND | *(see Power Nets)* |
| 3 | GND | *(see Power Nets)* |
| 4 | unconnected-(E70-Pad4) |  |
| 5 | unconnected-(E70-Pad5) |  |
| 6 | 5V | *(see Power Nets)* |
| 7 | unconnected-(E70-Pad7) |  |
| 8 | GND | *(see Power Nets)* |
| 9 | GND | *(see Power Nets)* |
| 10 | _NET_250 | E48/16 |
| 11 | GND | *(see Power Nets)* |
| 12 | _NET_267 | C18/2 |
| 13 | _NET_268 | C18/1 |
| 14 | _NET_269 | R93/2 |
| 15 | 5V | *(see Power Nets)* |
| 16 | 5V | *(see Power Nets)* |

## E71

| Pin | Net | Connected to |
|--|--|--|
| 1 | unconnected-(E71-Pad1) |  |
| 2 | DABUS3 | C16/1, E12/16, E29/13, E30/2, E31/2, E32/8, E33/32, E35/18, E39/3, E50/13, E51/13, E56/9, E63/40, E65/16, E65/17, E66/15, E67/28, E98/2 |
| 3 | _NET_80 | E59/3, E60/3, E61/3, E62/3, E72/3, E73/3, E74/3, E85/3, E86/3, E87/3, E88/3, E98/3, E99/3, E100/3, E101/3, R51/2 |
| 4 | RAS1- | E23/8, E59/4, E60/4, E61/4, E62/4, E72/4, E73/4, E74/4, E84/4 |
| 5 | _NET_72 | E59/5, E60/5, E61/5, E62/5, E72/5, E73/5, E74/5, E85/5, E86/5, E87/5, E88/5, E98/5, E99/5, E100/5, E101/5, R48/2 |
| 6 | _NET_74 | E59/6, E60/6, E61/6, E62/6, E72/6, E73/6, E74/6, E85/6, E86/6, E87/6, E88/6, E98/6, E99/6, E100/6, E101/6, R46/2 |
| 7 | _NET_73 | E59/7, E60/7, E61/7, E62/7, E72/7, E73/7, E74/7, E85/7, E86/7, E87/7, E88/7, E98/7, E99/7, E100/7, E101/7, R44/2 |
| 8 | 5V | *(see Power Nets)* |
| 9 | _NET_79 | E59/9, E60/9, E61/9, E62/9, E72/9, E73/9, E74/9, E85/9, E86/9, E87/9, E88/9, E98/9, E99/9, E100/9, E101/9, R43/2 |
| 10 | _NET_77 | E59/10, E60/10, E61/10, E62/10, E72/10, E73/10, E74/10, E85/10, E86/10, E87/10, E88/10, E98/10, E99/10, E100/10, E101/10, R45/2 |
| 11 | _NET_76 | E59/11, E60/11, E61/11, E62/11, E72/11, E73/11, E74/11, E85/11, E86/11, E87/11, E88/11, E98/11, E99/11, E100/11, E101/11, R47/2 |
| 12 | _NET_75 | E59/12, E60/12, E61/12, E62/12, E72/12, E73/12, E74/12, E85/12, E86/12, E87/12, E88/12, E98/12, E99/12, E100/12, E101/12, R49/2 |
| 13 | _NET_78 | E59/13, E60/13, E61/13, E62/13, E72/13, E73/13, E74/13, E85/13, E86/13, E87/13, E88/13, E98/13, E99/13, E100/13, E101/13, R50/2 |
| 14 | D03 | E39/17, E98/14 |
| 15 | CAS- | E59/15, E60/15, E61/15, E62/15, E72/15, E73/15, E74/15, E85/15, E86/15, E87/15, E88/15, E98/15, E99/15, E100/15, E101/15, R52/2 |
| 16 | GND | *(see Power Nets)* |

## E72

| Pin | Net | Connected to |
|--|--|--|
| 1 | unconnected-(E72-Pad1) |  |
| 2 | DABUS5 | C15/1, E12/14, E29/15, E30/3, E31/3, E32/9, E33/29, E35/20, E39/7, E50/15, E51/15, E56/11, E63/38, E65/6, E65/7, E66/6, E67/2, E99/2 |
| 3 | _NET_80 | E59/3, E60/3, E61/3, E62/3, E71/3, E73/3, E74/3, E85/3, E86/3, E87/3, E88/3, E98/3, E99/3, E100/3, E101/3, R51/2 |
| 4 | RAS1- | E23/8, E59/4, E60/4, E61/4, E62/4, E71/4, E73/4, E74/4, E84/4 |
| 5 | _NET_72 | E59/5, E60/5, E61/5, E62/5, E71/5, E73/5, E74/5, E85/5, E86/5, E87/5, E88/5, E98/5, E99/5, E100/5, E101/5, R48/2 |
| 6 | _NET_74 | E59/6, E60/6, E61/6, E62/6, E71/6, E73/6, E74/6, E85/6, E86/6, E87/6, E88/6, E98/6, E99/6, E100/6, E101/6, R46/2 |
| 7 | _NET_73 | E59/7, E60/7, E61/7, E62/7, E71/7, E73/7, E74/7, E85/7, E86/7, E87/7, E88/7, E98/7, E99/7, E100/7, E101/7, R44/2 |
| 8 | 5V | *(see Power Nets)* |
| 9 | _NET_79 | E59/9, E60/9, E61/9, E62/9, E71/9, E73/9, E74/9, E85/9, E86/9, E87/9, E88/9, E98/9, E99/9, E100/9, E101/9, R43/2 |
| 10 | _NET_77 | E59/10, E60/10, E61/10, E62/10, E71/10, E73/10, E74/10, E85/10, E86/10, E87/10, E88/10, E98/10, E99/10, E100/10, E101/10, R45/2 |
| 11 | _NET_76 | E59/11, E60/11, E61/11, E62/11, E71/11, E73/11, E74/11, E85/11, E86/11, E87/11, E88/11, E98/11, E99/11, E100/11, E101/11, R47/2 |
| 12 | _NET_75 | E59/12, E60/12, E61/12, E62/12, E71/12, E73/12, E74/12, E85/12, E86/12, E87/12, E88/12, E98/12, E99/12, E100/12, E101/12, R49/2 |
| 13 | _NET_78 | E59/13, E60/13, E61/13, E62/13, E71/13, E73/13, E74/13, E85/13, E86/13, E87/13, E88/13, E98/13, E99/13, E100/13, E101/13, R50/2 |
| 14 | D05 | E39/13, E99/14 |
| 15 | CAS- | E59/15, E60/15, E61/15, E62/15, E71/15, E73/15, E74/15, E85/15, E86/15, E87/15, E88/15, E98/15, E99/15, E100/15, E101/15, R52/2 |
| 16 | GND | *(see Power Nets)* |

## E73

| Pin | Net | Connected to |
|--|--|--|
| 1 | unconnected-(E73-Pad1) |  |
| 2 | DABUS7 | C9/1, E12/12, E29/17, E30/4, E31/4, E32/13, E33/27, E35/22, E39/12, E50/17, E51/17, E56/13, E63/2, E65/12, E65/13, E66/11, E67/4, E100/2 |
| 3 | _NET_80 | E59/3, E60/3, E61/3, E62/3, E71/3, E72/3, E74/3, E85/3, E86/3, E87/3, E88/3, E98/3, E99/3, E100/3, E101/3, R51/2 |
| 4 | RAS1- | E23/8, E59/4, E60/4, E61/4, E62/4, E71/4, E72/4, E74/4, E84/4 |
| 5 | _NET_72 | E59/5, E60/5, E61/5, E62/5, E71/5, E72/5, E74/5, E85/5, E86/5, E87/5, E88/5, E98/5, E99/5, E100/5, E101/5, R48/2 |
| 6 | _NET_74 | E59/6, E60/6, E61/6, E62/6, E71/6, E72/6, E74/6, E85/6, E86/6, E87/6, E88/6, E98/6, E99/6, E100/6, E101/6, R46/2 |
| 7 | _NET_73 | E59/7, E60/7, E61/7, E62/7, E71/7, E72/7, E74/7, E85/7, E86/7, E87/7, E88/7, E98/7, E99/7, E100/7, E101/7, R44/2 |
| 8 | 5V | *(see Power Nets)* |
| 9 | _NET_79 | E59/9, E60/9, E61/9, E62/9, E71/9, E72/9, E74/9, E85/9, E86/9, E87/9, E88/9, E98/9, E99/9, E100/9, E101/9, R43/2 |
| 10 | _NET_77 | E59/10, E60/10, E61/10, E62/10, E71/10, E72/10, E74/10, E85/10, E86/10, E87/10, E88/10, E98/10, E99/10, E100/10, E101/10, R45/2 |
| 11 | _NET_76 | E59/11, E60/11, E61/11, E62/11, E71/11, E72/11, E74/11, E85/11, E86/11, E87/11, E88/11, E98/11, E99/11, E100/11, E101/11, R47/2 |
| 12 | _NET_75 | E59/12, E60/12, E61/12, E62/12, E71/12, E72/12, E74/12, E85/12, E86/12, E87/12, E88/12, E98/12, E99/12, E100/12, E101/12, R49/2 |
| 13 | _NET_78 | E59/13, E60/13, E61/13, E62/13, E71/13, E72/13, E74/13, E85/13, E86/13, E87/13, E88/13, E98/13, E99/13, E100/13, E101/13, R50/2 |
| 14 | D07 | E39/8, E100/14 |
| 15 | CAS- | E59/15, E60/15, E61/15, E62/15, E71/15, E72/15, E74/15, E85/15, E86/15, E87/15, E88/15, E98/15, E99/15, E100/15, E101/15, R52/2 |
| 16 | GND | *(see Power Nets)* |

## E74

| Pin | Net | Connected to |
|--|--|--|
| 1 | unconnected-(E74-Pad1) |  |
| 2 | DABUS1 | C12/2, E12/18, E29/11, E30/1, E31/1, E32/15, E33/34, E35/16, E39/16, E50/10, E51/10, E56/7, E63/20, E65/4, E65/5, E66/4, E67/26, E101/2 |
| 3 | _NET_80 | E59/3, E60/3, E61/3, E62/3, E71/3, E72/3, E73/3, E85/3, E86/3, E87/3, E88/3, E98/3, E99/3, E100/3, E101/3, R51/2 |
| 4 | RAS1- | E23/8, E59/4, E60/4, E61/4, E62/4, E71/4, E72/4, E73/4, E84/4 |
| 5 | _NET_72 | E59/5, E60/5, E61/5, E62/5, E71/5, E72/5, E73/5, E85/5, E86/5, E87/5, E88/5, E98/5, E99/5, E100/5, E101/5, R48/2 |
| 6 | _NET_74 | E59/6, E60/6, E61/6, E62/6, E71/6, E72/6, E73/6, E85/6, E86/6, E87/6, E88/6, E98/6, E99/6, E100/6, E101/6, R46/2 |
| 7 | _NET_73 | E59/7, E60/7, E61/7, E62/7, E71/7, E72/7, E73/7, E85/7, E86/7, E87/7, E88/7, E98/7, E99/7, E100/7, E101/7, R44/2 |
| 8 | 5V | *(see Power Nets)* |
| 9 | _NET_79 | E59/9, E60/9, E61/9, E62/9, E71/9, E72/9, E73/9, E85/9, E86/9, E87/9, E88/9, E98/9, E99/9, E100/9, E101/9, R43/2 |
| 10 | _NET_77 | E59/10, E60/10, E61/10, E62/10, E71/10, E72/10, E73/10, E85/10, E86/10, E87/10, E88/10, E98/10, E99/10, E100/10, E101/10, R45/2 |
| 11 | _NET_76 | E59/11, E60/11, E61/11, E62/11, E71/11, E72/11, E73/11, E85/11, E86/11, E87/11, E88/11, E98/11, E99/11, E100/11, E101/11, R47/2 |
| 12 | _NET_75 | E59/12, E60/12, E61/12, E62/12, E71/12, E72/12, E73/12, E85/12, E86/12, E87/12, E88/12, E98/12, E99/12, E100/12, E101/12, R49/2 |
| 13 | _NET_78 | E59/13, E60/13, E61/13, E62/13, E71/13, E72/13, E73/13, E85/13, E86/13, E87/13, E88/13, E98/13, E99/13, E100/13, E101/13, R50/2 |
| 14 | D01 | E39/4, E101/14 |
| 15 | CAS- | E59/15, E60/15, E61/15, E62/15, E71/15, E72/15, E73/15, E85/15, E86/15, E87/15, E88/15, E98/15, E99/15, E100/15, E101/15, R52/2 |
| 16 | GND | *(see Power Nets)* |

## E75

| Pin | Net | Connected to |
|--|--|--|
| 1 | _NET_137 | E63/30 |
| 2 | _NET_133 | E75/12, E75/5, E75/9, JJ6/2, R68/2 |
| 3 | PB3 | J6/32, R64/2 |
| 4 | _NET_136 | E63/29 |
| 5 | _NET_133 | E75/12, E75/2, E75/9, JJ6/2, R68/2 |
| 6 | PB2 | J6/30, R61/2 |
| 7 | GND | *(see Power Nets)* |
| 8 | PB1 | J6/28, R60/2 |
| 9 | _NET_133 | E75/12, E75/2, E75/5, JJ6/2, R68/2 |
| 10 | _NET_135 | E63/28 |
| 11 | PB0 | J6/26, R63/2 |
| 12 | _NET_133 | E75/2, E75/5, E75/9, JJ6/2, R68/2 |
| 13 | _NET_134 | E63/27 |
| 14 | 5V | *(see Power Nets)* |

## E76

| Pin | Net | Connected to |
|--|--|--|
| 1 | PA0 | J6/6, R66/2 |
| 2 | _NET_122 | E63/15, E76/3 |
| 3 | _NET_122 | E63/15, E76/2 |
| 4 | PA1 | J6/8, R65/2 |
| 5 | _NET_123 | E63/14, E76/6 |
| 6 | _NET_123 | E63/14, E76/5 |
| 7 | _NET_121 | E90/7, JJ2/1, JJ4/2, R86/2 |
| 8 | GND | *(see Power Nets)* |
| 9 | _NET_126 | E90/9, JJ3A/1, JJ3/2, R91/1 |
| 10 | _NET_124 | E63/13, E76/11 |
| 11 | _NET_124 | E63/13, E76/10 |
| 12 | PA2 | J6/10, R62/2 |
| 13 | _NET_125 | E63/12, E76/14 |
| 14 | _NET_125 | E63/12, E76/13 |
| 15 | PA3 | J6/12, R67/2 |
| 16 | 5V | *(see Power Nets)* |

## E77

| Pin | Net | Connected to |
|--|--|--|
| 1 | RESET- | E4/6, E11/4, E24/10, E30/21, E31/21, E32/26, E64/10, E67/17, E77/13, E103/1, E103/13, E104/10, E104/4, J2/21 |
| 2 | _NET_222 | E94/12 |
| 3 | _NET_223 | E106/1 |
| 4 | _NET_226 | E81/3, E106/12, E106/5 |
| 5 | _NET_219 | E103/6 |
| 6 | _NET_225 | E105/2 |
| 7 | GND | *(see Power Nets)* |
| 8 | _NET_206 | E14/10 |
| 9 | FDCIEI | E78/13, E78/3, E81/2, E94/1, E94/4 |
| 10 | FDCIEO | E105/12 |
| 11 | _NET_227 | E106/13 |
| 12 | _NET_220 | E78/12 |
| 13 | RESET- | E4/6, E11/4, E24/10, E30/21, E31/21, E32/26, E64/10, E67/17, E77/1, E103/1, E103/13, E104/10, E104/4, J2/21 |
| 14 | 5V | *(see Power Nets)* |

## E78

| Pin | Net | Connected to |
|--|--|--|
| 1 | _NET_217 | E103/9 |
| 2 | _NET_215 | E104/8 |
| 3 | FDCIEI | E77/9, E78/13, E81/2, E94/1, E94/4 |
| 4 | _NET_224 | E105/1, E106/9 |
| 5 | _NET_221 | E94/13, E105/6, E106/11 |
| 6 | _NET_211 | E65/1 |
| 7 | GND | *(see Power Nets)* |
| 8 | unconnected-(E78-Pad8) |  |
| 9 | unconnected-(E78-Pad9) |  |
| 10 | unconnected-(E78-Pad10) |  |
| 11 | unconnected-(E78-Pad11) |  |
| 12 | _NET_220 | E77/12 |
| 13 | FDCIEI | E77/9, E78/3, E81/2, E94/1, E94/4 |
| 14 | 5V | *(see Power Nets)* |

## E79

| Pin | Net | Connected to |
|--|--|--|
| 1 | DABUS10 | E66/12, E92/1, E93/1 |
| 2 | DABUS11 | E66/16, E80/9 |
| 3 | DD2- | E80/2 |
| 4 | DABUS13 | E66/5, E92/4, E93/4 |
| 5 | DD4- | E80/10, E92/5, E93/5 |
| 6 | DD5- | E80/6, E92/6 |
| 7 | GND | *(see Power Nets)* |
| 8 | CB- | E104/2 |
| 9 | unconnected-(E79-Pad9) |  |
| 10 | unconnected-(E79-Pad10) |  |
| 11 | DABUS16 | E66/3, E92/11, E93/11 |
| 12 | DABUS17 | E66/9, E80/3, E93/12 |
| 13 | unconnected-(E79-Pad13) |  |
| 14 | 5V | *(see Power Nets)* |

## E80

| Pin | Net | Connected to |
|--|--|--|
| 1 | DABUS12 | E66/18, E92/3, E93/3 |
| 2 | DD2- | E79/3 |
| 3 | DABUS17 | E66/9, E79/12, E93/12 |
| 4 | DD7- | E92/12 |
| 5 | DABUS15 | E66/14, E93/6 |
| 6 | DD5- | E79/6, E92/6 |
| 7 | GND | *(see Power Nets)* |
| 8 | DD1- | E92/2, E93/2 |
| 9 | DABUS11 | E66/16, E79/2 |
| 10 | DD4- | E79/5, E92/5, E93/5 |
| 11 | DABUS14 | E66/7 |
| 12 | unconnected-(E80-Pad12) |  |
| 13 | unconnected-(E80-Pad13) |  |
| 14 | 5V | *(see Power Nets)* |

## E81

| Pin | Net | Connected to |
|--|--|--|
| 1 | INT- | E30/5, E31/5, E63/23, E67/12, E81/4, E84/2, R54/2 |
| 2 | FDCIEI | E77/9, E78/13, E78/3, E94/1, E94/4 |
| 3 | _NET_226 | E77/4, E106/12, E106/5 |
| 4 | INT- | E30/5, E31/5, E63/23, E67/12, E81/1, E84/2, R54/2 |
| 5 | _NET_257 | E37/12, E81/6, E108/12 |
| 6 | _NET_257 | E37/12, E81/5, E108/12 |
| 7 | GND | *(see Power Nets)* |
| 8 | unconnected-(E81-Pad8) |  |
| 9 | unconnected-(E81-Pad9) |  |
| 10 | unconnected-(E81-Pad10) |  |
| 11 | unconnected-(E81-Pad11) |  |
| 12 | unconnected-(E81-Pad12) |  |
| 13 | unconnected-(E81-Pad13) |  |
| 14 | 5V | *(see Power Nets)* |

## E82

| Pin | Net | Connected to |
|--|--|--|
| 1 | DRQ+ | E56/14 |
| 2 | _NET_198 | E107/4 |
| 3 | _NET_278 | E82/6, R56/1, R57/2 |
| 4 | _NET_279 | E22/9, R57/1 |
| 5 |  |  |
| 6 | _NET_278 | E82/3, R56/1, R57/2 |
| 7 | GND | *(see Power Nets)* |
| 8 | SEEK- | E28/13 |
| 9 | SEEK | E27/13, E27/2, E49/1, E56/39 |
| 10 | _NET_276 | E26/2, E28/4 |
| 11 | DS0 | E26/4, E28/2, E56/29 |
| 12 | RDI | E95/13 |
| 13 | RDI- | E15/7, E30/32, E31/32, E35/2, E38/13, E40/13, E56/2, E63/35, E67/6, E91/2 |
| 14 | 5V | *(see Power Nets)* |

## E83

| Pin | Net | Connected to |
|--|--|--|
| 1 | 5V | *(see Power Nets)* |
| 2 | _NET_90 | E38/11 |
| 3 | CLCK | E4/1, E4/8, E83/11, JJ11/2 |
| 4 | 5V | *(see Power Nets)* |
| 5 | _NET_89 | E39/1, E39/19 |
| 6 | unconnected-(E83-Pad6) |  |
| 7 | GND | *(see Power Nets)* |
| 8 | _NET_265 | E83/12 |
| 9 | CLK | E56/19, E96/1, JJ11/1, JJ11/11, JJ11/12, R204/2 |
| 10 | _NET_266 | E83/13, R55/2 |
| 11 | CLCK | E4/1, E4/8, E83/3, JJ11/2 |
| 12 | _NET_265 | E83/8 |
| 13 | _NET_266 | E83/10, R55/2 |
| 14 | 5V | *(see Power Nets)* |

## E84

| Pin | Net | Connected to |
|--|--|--|
| 1 | INTB- | J2/29, R4/2 |
| 2 | INT- | E30/5, E31/5, E63/23, E67/12, E81/1, E81/4, R54/2 |
| 3 | _NET_28 | E32/16 |
| 4 | RAS1- | E23/8, E59/4, E60/4, E61/4, E62/4, E71/4, E72/4, E73/4, E74/4 |
| 5 | RAS2- | E23/3, E85/4, E86/4, E87/4, E88/4, E98/4, E99/4, E100/4, E101/4 |
| 6 | _NET_60 | E38/9 |
| 7 | GND | *(see Power Nets)* |
| 8 | unconnected-(E84-Pad8) |  |
| 9 | unconnected-(E84-Pad9) |  |
| 10 | unconnected-(E84-Pad10) |  |
| 11 | unconnected-(E84-Pad11) |  |
| 12 | unconnected-(E84-Pad12) |  |
| 13 | unconnected-(E84-Pad13) |  |
| 14 | 5V | *(see Power Nets)* |

## E85

| Pin | Net | Connected to |
|--|--|--|
| 1 | unconnected-(E85-Pad1) |  |
| 2 | DABUS4 | C14/2, E12/7, E29/4, E30/38, E31/38, E32/7, E33/31, E35/19, E39/5, E50/14, E51/14, E56/10, E59/2, E63/39, E65/14, E65/15, E66/13, E67/1 |
| 3 | _NET_80 | E59/3, E60/3, E61/3, E62/3, E71/3, E72/3, E73/3, E74/3, E86/3, E87/3, E88/3, E98/3, E99/3, E100/3, E101/3, R51/2 |
| 4 | RAS2- | E23/3, E84/5, E86/4, E87/4, E88/4, E98/4, E99/4, E100/4, E101/4 |
| 5 | _NET_72 | E59/5, E60/5, E61/5, E62/5, E71/5, E72/5, E73/5, E74/5, E86/5, E87/5, E88/5, E98/5, E99/5, E100/5, E101/5, R48/2 |
| 6 | _NET_74 | E59/6, E60/6, E61/6, E62/6, E71/6, E72/6, E73/6, E74/6, E86/6, E87/6, E88/6, E98/6, E99/6, E100/6, E101/6, R46/2 |
| 7 | _NET_73 | E59/7, E60/7, E61/7, E62/7, E71/7, E72/7, E73/7, E74/7, E86/7, E87/7, E88/7, E98/7, E99/7, E100/7, E101/7, R44/2 |
| 8 | 5V | *(see Power Nets)* |
| 9 | _NET_79 | E59/9, E60/9, E61/9, E62/9, E71/9, E72/9, E73/9, E74/9, E86/9, E87/9, E88/9, E98/9, E99/9, E100/9, E101/9, R43/2 |
| 10 | _NET_77 | E59/10, E60/10, E61/10, E62/10, E71/10, E72/10, E73/10, E74/10, E86/10, E87/10, E88/10, E98/10, E99/10, E100/10, E101/10, R45/2 |
| 11 | _NET_76 | E59/11, E60/11, E61/11, E62/11, E71/11, E72/11, E73/11, E74/11, E86/11, E87/11, E88/11, E98/11, E99/11, E100/11, E101/11, R47/2 |
| 12 | _NET_75 | E59/12, E60/12, E61/12, E62/12, E71/12, E72/12, E73/12, E74/12, E86/12, E87/12, E88/12, E98/12, E99/12, E100/12, E101/12, R49/2 |
| 13 | _NET_78 | E59/13, E60/13, E61/13, E62/13, E71/13, E72/13, E73/13, E74/13, E86/13, E87/13, E88/13, E98/13, E99/13, E100/13, E101/13, R50/2 |
| 14 | D04 | E39/15, E59/14 |
| 15 | CAS- | E59/15, E60/15, E61/15, E62/15, E71/15, E72/15, E73/15, E74/15, E86/15, E87/15, E88/15, E98/15, E99/15, E100/15, E101/15, R52/2 |
| 16 | GND | *(see Power Nets)* |

## E86

| Pin | Net | Connected to |
|--|--|--|
| 1 | unconnected-(E86-Pad1) |  |
| 2 | DABUS6 | C10/1, E12/9, E29/2, E30/37, E31/37, E32/10, E33/28, E35/21, E39/9, E50/16, E51/16, E56/12, E60/2, E63/3, E65/18, E65/19, E66/17, E67/3 |
| 3 | _NET_80 | E59/3, E60/3, E61/3, E62/3, E71/3, E72/3, E73/3, E74/3, E85/3, E87/3, E88/3, E98/3, E99/3, E100/3, E101/3, R51/2 |
| 4 | RAS2- | E23/3, E84/5, E85/4, E87/4, E88/4, E98/4, E99/4, E100/4, E101/4 |
| 5 | _NET_72 | E59/5, E60/5, E61/5, E62/5, E71/5, E72/5, E73/5, E74/5, E85/5, E87/5, E88/5, E98/5, E99/5, E100/5, E101/5, R48/2 |
| 6 | _NET_74 | E59/6, E60/6, E61/6, E62/6, E71/6, E72/6, E73/6, E74/6, E85/6, E87/6, E88/6, E98/6, E99/6, E100/6, E101/6, R46/2 |
| 7 | _NET_73 | E59/7, E60/7, E61/7, E62/7, E71/7, E72/7, E73/7, E74/7, E85/7, E87/7, E88/7, E98/7, E99/7, E100/7, E101/7, R44/2 |
| 8 | 5V | *(see Power Nets)* |
| 9 | _NET_79 | E59/9, E60/9, E61/9, E62/9, E71/9, E72/9, E73/9, E74/9, E85/9, E87/9, E88/9, E98/9, E99/9, E100/9, E101/9, R43/2 |
| 10 | _NET_77 | E59/10, E60/10, E61/10, E62/10, E71/10, E72/10, E73/10, E74/10, E85/10, E87/10, E88/10, E98/10, E99/10, E100/10, E101/10, R45/2 |
| 11 | _NET_76 | E59/11, E60/11, E61/11, E62/11, E71/11, E72/11, E73/11, E74/11, E85/11, E87/11, E88/11, E98/11, E99/11, E100/11, E101/11, R47/2 |
| 12 | _NET_75 | E59/12, E60/12, E61/12, E62/12, E71/12, E72/12, E73/12, E74/12, E85/12, E87/12, E88/12, E98/12, E99/12, E100/12, E101/12, R49/2 |
| 13 | _NET_78 | E59/13, E60/13, E61/13, E62/13, E71/13, E72/13, E73/13, E74/13, E85/13, E87/13, E88/13, E98/13, E99/13, E100/13, E101/13, R50/2 |
| 14 | D06 | E39/11, E60/14 |
| 15 | CAS- | E59/15, E60/15, E61/15, E62/15, E71/15, E72/15, E73/15, E74/15, E85/15, E87/15, E88/15, E98/15, E99/15, E100/15, E101/15, R52/2 |
| 16 | GND | *(see Power Nets)* |

## E87

| Pin | Net | Connected to |
|--|--|--|
| 1 | unconnected-(E87-Pad1) |  |
| 2 | D0 | C11/2, E12/3, E14/13, E29/8, E30/40, E31/40, E32/14, E33/35, E35/15, E39/14, E50/9, E51/9, E56/6, E61/2, E63/19, E65/8, E65/9, E66/8, E67/25 |
| 3 | _NET_80 | E59/3, E60/3, E61/3, E62/3, E71/3, E72/3, E73/3, E74/3, E85/3, E86/3, E88/3, E98/3, E99/3, E100/3, E101/3, R51/2 |
| 4 | RAS2- | E23/3, E84/5, E85/4, E86/4, E88/4, E98/4, E99/4, E100/4, E101/4 |
| 5 | _NET_72 | E59/5, E60/5, E61/5, E62/5, E71/5, E72/5, E73/5, E74/5, E85/5, E86/5, E88/5, E98/5, E99/5, E100/5, E101/5, R48/2 |
| 6 | _NET_74 | E59/6, E60/6, E61/6, E62/6, E71/6, E72/6, E73/6, E74/6, E85/6, E86/6, E88/6, E98/6, E99/6, E100/6, E101/6, R46/2 |
| 7 | _NET_73 | E59/7, E60/7, E61/7, E62/7, E71/7, E72/7, E73/7, E74/7, E85/7, E86/7, E88/7, E98/7, E99/7, E100/7, E101/7, R44/2 |
| 8 | 5V | *(see Power Nets)* |
| 9 | _NET_79 | E59/9, E60/9, E61/9, E62/9, E71/9, E72/9, E73/9, E74/9, E85/9, E86/9, E88/9, E98/9, E99/9, E100/9, E101/9, R43/2 |
| 10 | _NET_77 | E59/10, E60/10, E61/10, E62/10, E71/10, E72/10, E73/10, E74/10, E85/10, E86/10, E88/10, E98/10, E99/10, E100/10, E101/10, R45/2 |
| 11 | _NET_76 | E59/11, E60/11, E61/11, E62/11, E71/11, E72/11, E73/11, E74/11, E85/11, E86/11, E88/11, E98/11, E99/11, E100/11, E101/11, R47/2 |
| 12 | _NET_75 | E59/12, E60/12, E61/12, E62/12, E71/12, E72/12, E73/12, E74/12, E85/12, E86/12, E88/12, E98/12, E99/12, E100/12, E101/12, R49/2 |
| 13 | _NET_78 | E59/13, E60/13, E61/13, E62/13, E71/13, E72/13, E73/13, E74/13, E85/13, E86/13, E88/13, E98/13, E99/13, E100/13, E101/13, R50/2 |
| 14 | D00 | E39/6, E61/14 |
| 15 | CAS- | E59/15, E60/15, E61/15, E62/15, E71/15, E72/15, E73/15, E74/15, E85/15, E86/15, E88/15, E98/15, E99/15, E100/15, E101/15, R52/2 |
| 16 | GND | *(see Power Nets)* |
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

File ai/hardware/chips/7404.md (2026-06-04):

# 7404 — Hex Inverter

## Overview
The 7404 contains six independent single-input inverter (NOT) gates with standard totem-pole outputs. Each gate inverts its input: a HIGH input produces a LOW output, and a LOW input produces a HIGH output. The 7404 is one of the most fundamental TTL logic devices and is available in the original 7400-series as well as the low-power Schottky variant (74LS04), high-speed CMOS variant (74HC04), and others.
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

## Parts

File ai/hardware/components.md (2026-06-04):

# Partner 40 Components

## Integrated Circuits — E (101)

| ID | Value Ref | Ref 1 | Ref 2 |
|--|--|--|--|
| E1 | LS123 | SN74LS123N | SN74LS123N |
| E2 | LS14 | 74LS14N | SN74LS14N |
| E3 | S74 | DM74S74N | DM74S74N |
| E4 | S04 | EL74S04 | DM74S04J |
| E5 | LS244 | T74LS244B1 | T74LS244B1 |
| E6 | LS244 | 74LS244N | T74LS244B1 |
| E7 | LS244 | T74LS244B1 | SN74LS244J |
| E8 | LS244 | T74LS244B1 | SN74LS244J |
| E9 | LS05 | SN74LS05J | SN74LS05N |
| E10 | LS30 | T74LS30B1 | T74LS30B1 |
| E11 | LS74 | SN74LS74AN | SN74LS74AN |
| E12 | LS244 | SN74LS244N | T74LS244B1 |
| E13 | LS244 | SN74LS244N | T74LS244B1 |
| E14 | LS367 | SN74LS367AN | SN54LS367AJ |
| E15 | LS244 | 74LS244N | SN74LS244B1 |
| E16 | LS367 | SN54LS367AJ | SN54LS367AJ |
| E17 | LS244 | T74LS244B1 | T74LS244B1 |
| E18 | LS244 | T74LS244B1 | T74LS244B1 |
| E19 | LS244 | 74LS244N | SN74LS244J |
| E20 | LS244 | 74LS244N | SN74LS244J |
| E21 | LS04 | 74LS04 PC | SN74LS04N |
| E22 | LS04 | DM74LS04N | SN74LS04N |
| E23 | LS08 | SN74LS08N | SN74LS08N |
| E24 | LS08 | SN74LS08N | SN74LS08N |
| E25 | 7404 | 7404PC | SN7404 J |
| E26 | LS38 | T74LS38B1 | T74LS38B1 |
| E27 | LS38 | T74LS38B1 | T74LS38B1 |
| E28 | LS38 | T74LS38B1 | T74LS38B1 |
| E29 | LS244 | 74LS244N | T74LS244B1 |
| E30 | Z80A SIO-1 | ZILOG Z84??BPS Z80? SIO/1 8338 W | ZILOG Z8881BPS Z80B SIO/1 8449 |
| E32 | Z80A CPU | MOSTEK TC8639 MK3880N-4 Z80A CPU | MOSTEK TC8639 MK3880N-4 Z80A CPU |
| E33 | Z80A DMA | Z8410AB1 Z80ADMA 28618 | Z8410AB1 Z80ADMA 28548 |
| E34 | LS32 | SN74LS32N | SN74LS32N |
| E35 | MM58167A | MM58167AN | +B8612 MM58167AN |
| E36 | LS04 | DM74LS04N | SN74LS04N |
| E37 | LS04 | DM7404N | SN74LS04N |
| E38 | LS32 | (SN74LS32...) | SN74LS32N |
| E39 | LS244 | 74LS244N | T74LS244B1 |
| E40 | LS42 | HD74LS42P | HD74LS42P |
| E41 | LS32 | SN74LS32N | SN74LS32N |
| E42 | LS14 | 74LS14N | SN74LS14N |
| E43 | MC1488 | MC1488P T8444 | MC1488P RQ8326 |
| E44 | MC1488 | MC1488P RQ8319 | MC1488P RQ8321 |
| E45 | MC1489 | MC1489P K8539 | 406C MC1489A 75189AN |
| E46 | LS32 | SN74LS32N | SN74LS32N |
| E47 | LS08 | SN74LS08N | SN74LS08N |
| E48 | WD1691 | WD1691PE 8348 | WD1691PE-00 8421 02 |
| E49 | LS157 | SN74LS157N | SN74LS157N |
| E51 | M2716 | | | 
| E52 | MC1489 | 406C MC1489A 75189AN | 406C MC1989A 75189AN |
| E53 | MC1489 | 406C MC1489A 75189AN | 406C MC1989A 75189AN |
| E54 | LS32 | SN74LS32N | SN74LS32N |
| E55 | LS20 | SN74LS20N | DM74LS20N |
| E56 | D765 | 8624KD D765AC-2 | 8350K6 FDC765AC |
| E57 | WD2143 | WD2143-PD 03-15 8706 | WD2143M-03 8217 |
| E58 | LS123 | SN74LS123N | SN74LS123N |
| E59 | M3764A-15 | M3764A-15 65518 | M3764A-15 65516 |
| E60 | M3764A-15 | M3764A-15 65518 | M3764A-15 65518 |
| E61 | M3764A-15 | M3764A-15 65518 | M3764A-15 65518 |
| E62 | M3764A-15 | M3764A-15 65518 | M3764A-15 65518 |
| E64 | MC14411 | MC14411 P QR8610 | MC14411 P QR8610 |
| E65 | LS374 | 74LS374N | 74LS374N |
| E66 | LS244 | 74LS244N | T74LS244B1 |
| E67 | Z80A CTC | ZILOG Z8430APE Z80A CTC 8342 | MOSTEK 8502 MK3882N Z80 CTC |
| E68 | LS138 | 74LS138PC | SN74LS138N |
| E69 | LS138 | SN74LS138N | 74LS138N |
| E70 | LS629 | SN74LS629N | SN74LS629N |
| E71 | M3764A-15 | M3764A-15 65518 | M3764A-15 65516 |
| E72 | M3764A-15 | M3764A-15 65518 | M3764A-15 65518 |
| E73 | M3764A-15 | M3764A-15 65518 | M3764A-15 65518 |
| E74 | M3764A-15 | M3764A-15 65518 | M3764A-15 65518 |
| E77 | LS08 | 74LS08 PC | SN74LS08N |
| E78 | LS10 | EL74LS10J | EL74LS10J |
| E79 | LS30 | T74LS30B1 | T74LS30B1 |
| E80 | LS04 | DM74LS04N | SN74LS04N |
| E81 | LS01 | SN74LS01N | SN74LS01N |
| E82 | S04 | EL74S04 | DM74S04J |
| E83 | LS74 | SN74LS74AN | SN74LS74AN |
| E84 | LS08 | 74LS08 PC | SN74LS08N |
| E85 | M3764A-15 | M3764A-15 65518 | M3764A-15 65516 |
| E86 | M3764A-15 | M3764A-15 65518 | M3764A-15 65518 |
| E87 | M3764A-15 | M3764A-15 65518 | M3764A-15 65518 |
| E88 | M3764A-15 | M3764A-15 65518 | M3764A-15 65518 |
| E91 | LS32 | 74LS32 PC | SN74LS32N |
| E92 | LS30 | T74LS30B1 | T74LS30B1 |
| E93 | LS30 | T74LS30B1 | T74LS30B1 |
| E94 | LS04 | DM74LS04N | SN74LS04N |
| E95 | LS132 | 74LS132NB | T74LS132B1 |
| E96 | LS393 | DM74LS393N | SN74LS393N |
| E97 | LS157 | SN74LS157N | SN74LS157N |
| E98 | M3764A-15 | M3764A-15 65518 | M3764A-15 65516 |
| E99 | M3764A-15 | M3764A-15 65518 | M3764A-15 65516 |
| E100 | M3764A-15 | M3764A-15 65518 | M3764A-15 65518 |
| E101 | M3764A-15 | M3764A-15 65518 | M3764A-15 65518 |
| E102 | LS86 | SN74LS86N | T74LS86B1 |
| E103 | LS74 | SN74LS74AN | SN74LS74AN |
| E104 | LS74 | SN74LS74AN | SN74LS74AN |
| E105 | LS27 | T74LS27B1 | T74LS27B1 |
| E106 | LS74 | SN74LS74AN | SN74LS74AN |
| E107 | LS74 | SN74LS74AN | SN74LS74AN |
| E108 | LS08 | 74LS08 PC | SN74LS08N |

## Resistors — R (81)

| ID | Value Ref | Ref 1 |
|--|--|--|
| R1 | 3.3kΩ | 3.3 kΩ ±5% |
| R2 | 1kΩ | 1 kΩ ±5% |
| R3 | 1kΩ | 1 kΩ ±5% |
| R4 | 1kΩ | 1 kΩ ±5% |
| R5 | 1kΩ | 1 kΩ ±5% |
| R7 | 1kΩ | 1 kΩ ±5% |
| R9 | 1kΩ | 1 kΩ ±5% |
| R10 | 150Ω | 150 Ω ±5% |
| R11 | 220Ω | 220 Ω ±5% |
| R12 | 3.3kΩ | 3.3 kΩ ±5% |
| R13 | 3.3kΩ | 3.3 kΩ ±5% |
| R14 | 10kΩ | 10 kΩ ±5% |
| R15 | 1kΩ | 1 kΩ ±5% |
| R16 | 56Ω | 56 Ω ±5% |
| R17 | 820Ω | 920 Ω ±5% / 820 Ω ±5% |
| R18 | 1kΩ | 1 kΩ ±5% |
| R19 | 10kΩ | 10 kΩ ±5% |
| R20 | 820Ω | 920 Ω ±5% / 820 Ω ±5% |
| R21 | 20kΩ | 20 kΩ ±5% |
| R22 | 3.3kΩ | 3.3 kΩ ±5% |
| R23 | 3.3kΩ | 3.3 kΩ ±5% |
| R26 | 1.5kΩ | 1.5 kΩ ±5% |
| R36 | 3.3kΩ | 3.3 kΩ ±5% |
| R37 | 150Ω | 150 Ω ±5% |
| R38 | 150Ω | 150 Ω ±5% |
| R39 | 150Ω | 150 Ω ±5% |
| R40 | 150Ω | 150 Ω ±5% |
| R41 | 150Ω | 150 Ω ±5% |
| R42 | 150Ω | 150 Ω ±5% |
| R43 | 33Ω | 33 Ω ±5% |
| R44 | 33Ω | 33 Ω ±5% |
| R45 | 33Ω | 33 Ω ±5% |
| R46 | 33Ω | 33 Ω ±5% |
| R47 | 33Ω | 33 Ω ±5% |
| R48 | 33Ω | 33 Ω ±5% |
| R49 | 33Ω | 33 Ω ±5% |
| R50 | 33Ω | 33 Ω ±5% |
| R51 | 33Ω | 33 Ω ±5% |
| R52 | 33Ω | 33 Ω ±5% |
| R53 | 5.1kΩ | 5K1 ±5% |
| R54 | 3.3kΩ | 3.3 kΩ ±5% |
| R55 | 3.3kΩ | 3.3 kΩ ±5% |
| R58 | 3.3kΩ | 3.3 kΩ ±5% |
| R59 | 3.3kΩ | 3.3 kΩ ±5% |
| R60 | 1kΩ | 1 kΩ ±5% |
| R61 | 1kΩ | 1 kΩ ±5% |
| R62 | 1kΩ | 1 kΩ ±5% |
| R63 | 1kΩ | 1 kΩ ±5% |
| R64 | 1kΩ | 1 kΩ ±5% |
| R65 | 1kΩ | 1 kΩ ±5% |
| R66 | 1kΩ | 1 kΩ ±5% |
| R67 | 1kΩ | 1 kΩ ±5% |
| R68 | 4.7kΩ | 4.7 kΩ ±5% |
| R69 | 4.7kΩ | 4.7 kΩ ±5% |
| R70 | 1kΩ | 1 kΩ ±5% |
| R71 | 1kΩ | 1 kΩ ±5% |
| R72 | 1kΩ | 1 kΩ ±5% |
| R73 | 1kΩ | 1 kΩ ±5% |
| R74 | 1kΩ | 1 kΩ ±5% |
| R75 | 1kΩ | 1 kΩ ±5% |
| R76 | 1kΩ | 1 kΩ ±5% |
| R77 | 1kΩ | 1 kΩ ±5% |
| R78 | 4.7kΩ | 4.7 kΩ ±5% |
| R79 | 4.7kΩ | 4.7 kΩ ±5% |
| R80 | 4.7kΩ | 4.7 kΩ ±5% |
| R82 | 1kΩ | 1 kΩ ±5% |
| R83 | 4.7kΩ | 4.7 kΩ ±5% |
| R84 | 47Ω | 47 Ω ±5% |
| R85 | 1kΩ | 1 kΩ ±5% |
| R86 | 4.7kΩ | 4.7 kΩ ±5% |
| R87 | 47kΩ | 47 kΩ ±5% |
| R88 | 47kΩ | 47 kΩ ±5% |
| R89 | 68Ω | 68 Ω ±5% |
| R90 | 10kΩ | 10 kΩ ±5% |
| R91 | 4.7kΩ | 4.7 kΩ ±5% |
| R92 | 50kΩ | | Trimmer Bourns 3296Y |
| R93 | 50kΩ | | Trimmer Bourns 3296Y |
| R94 | 10kΩ | | Trimmer Bourns 3296Y |
| R95 | 10kΩ | 10 kΩ ±5% |
| R200 | Z 2.7V | BZX 2,7 | Zener diode |
| R201 | 560Ω | 560 Ω ±5% |
| R202 | 15MΩ | 15 MΩ | Blue-colored body, 1% tolerance |
| R203 | 390Ω | 390 Ω ±5% |
| R204 | 330Ω | 330 Ω ±5% |

## Capacitors — C (59)

| ID | Value Ref | Ref 1 | Ref 2 |
|--|--|--|--|
| C1 | 100μF | 100 uF 40 V | 100 uF 40 V |
| C2 | 100μF | 100 uF 40 V | 100 uF 40 V |
| C3 | 100μF | 100 uF 40 V | 100 uF 40 V |
| C4 | 100μF | 100 uF 40 V | 100 uF 40 V |
| C5 | 1nF | 1n0 | 1n0 |
| C6 | 1nF | 1n0 | 1n0S (400V?) |
| C7 | 2.2nF | 2n2 | 2n2 |
| C8 | 68μF | 68uF 25V | 68uF 25V |
| C17 | 68pF | 68p | 68p |
| C18 | 82pF | 82p | 82p |
| C20 | 68μF | 68 uF 25 V | 68 uF 25 V |
| C21 | 20pF | 22 pF | 22J |
| C22 | 20pF | 22 pF | 22J |
| C102 | 2.2nF | 2n2 | 2n2 |
| C103 | 390pF | 380K Y5P / 390K Y5P | 380/390K |
| C110 | 390pF | 390K Y5P | 380/390K |
| C300 | 330pF | 330 | 330 |
| C301 | 680nF | 684 100V | 684 50V |
| CX1–CX41 | 0.1μF | 104 50V | 104 50V |

## Other Components

| ID | Type | Value Ref | Ref 1 | Ref 2 |
|--|--|--|--|--|
| BAT | Rechargeable battery | 3.6V | VARTA SafeTronic 3.6 V | |
| V1 | Led diode | LED | | |
| V2 | Diode | BA513 | BA 513 | |
| V3 | Diode | BA513 | BA 513 | |
| V4 | Diode | BA513 | BA 513 | |
| Y1 | Crystal | 8MHz | 8.000 SUNNY 2779 | |
| Y2 | Crystal | 32.768kHz | QRT-38 I | |
| Y3 | Crystal | 1.8432MHz | 1843 20 kHZ 11034 | |
| X10 | Connector | Power connector | | |
| J1 | Pin header | Pin header 2×17 | | |
| J2 | Pin header | Pin header 2×32 | | |
| J3 | Pin header | Pin header 1×3 | | |
| J5 | Pin header | Pin header 1×5 | | |
| J6 | Pin header | Pin header 2×20 | | |
| J7 | Pin header | Pin header 2×13 | | |
| J8 | Pin header | Pin header 2×13 | | |
| J9 | Pin header | Pin header 2×13 | | |
| JJ2 | Jumper | Jumper 1×2 | | |
| JJ7 | Jumper | Jumper 1×2 | | |
| JJ8 | Pin header | Pin header 1×4 + 1×14 | | |
| JJ9 | Jumper | Jumper 2×2 | | |
| JJ10 | Jumper | Jumper 1×2 | | |
| JJ50 | Jumper | Jumper 2×2 | | |

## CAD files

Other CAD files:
pdm/connector/PartnerPDM Connector Rev1.f3d
pdm/connector/PartnerPDM Connector Rev2.f3d
pdm/connector/PartnerPDM Connector Rev3.f3d

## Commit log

2023-10-27 Creates empty project
    [idp.kicad_pcb, idp.kicad_sch]
2023-10-27 Configures PCB page
    [idp.kicad_pcb, idp.kicad_sch]
2023-10-27 Adds template image (front)
    [idp.kicad_pcb]
2023-10-27 Adds template image (back)
    [idp.kicad_pcb]
2023-10-27 Adds first component
    [idp.kicad_pcb]
2023-10-27 Adds array of M3764A-15 (DRAM)
    [idp.kicad_pcb]
2023-10-27 Adds clearance to pads
    [idp.kicad_pcb]
2023-10-27 Adds default track width
    [idp.kicad_pcb]
2023-10-27 Connects DRAM chips
    [idp.kicad_pcb]
2023-10-27 Adds more components
    [idp.kicad_pcb]
2023-10-27 Adds more components Need to measure caps Need to delete off-sheet capacitor
    [idp.kicad_pcb]
2023-10-27 Done for the day
    [idp.kicad_pcb]
2023-10-27 Adds custom footprints
2023-10-27 Adds components (connector JJ8 broken)
    [idp.kicad_pcb]
2023-10-27 Adds custom footprints and components
    [idp.kicad_pcb]
2023-10-27 Fixes cuts
    [idp.kicad_pcb]
2023-10-27 Adds components and footprints
    [idp.kicad_pcb]
2023-10-27 Adds more components (placing components done but need to double-check)
    [idp.kicad_pcb]
2023-10-27 Fixes several custom footprints
    [idp.kicad_pcb]
2023-10-27 Adds test project (for importing vias)
    [test.kicad_pcb, test.kicad_sch]
2023-10-27 Imports AI-detected vias to KiCad
    [idp.kicad_pcb, test.kicad_pcb]
2023-10-27 Adds a bunch of copper
    [idp.kicad_pcb]
2023-10-27 Adds copper
    [idp.kicad_pcb]
2023-10-27 Adds a lot of copper
    [idp.kicad_pcb]
2023-10-27 Adds the other side (image), adds some copper
    [idp.kicad_pcb]
2023-10-27 Adds "blue" copper
    [idp.kicad_pcb]
2023-10-27 Rmv obsolete files
    [test.kicad_pcb, test.kicad_sch]
2023-10-27 Adds copper TODO: - Make vias same shape as original - Smaller battery/power connector TH (otherwise their clearance is violated)
    [idp.kicad_pcb]
2023-10-27 Adds PCB validation project, adds PCB files without template images
    [idp-valid.kicad_pcb]
2023-10-27 Converts all oval thru-holes to circles
    [idp-valid.kicad_pcb]
2023-10-27 Rmv grouping
    [idp-valid.kicad_pcb]
2023-10-27 Adjusts track and via sizes
    [idp-valid.kicad_pcb]
2023-10-27 Adjusts pad sizes
    [idp-valid.kicad_pcb]
2023-10-27 Adjusts track widths
    [idp-valid.kicad_pcb]
2023-10-27 Detects nets from PCB with flood fill
2023-10-27 Adds better schematics scans
2023-10-27 Adds missing CX
    [idp-valid.kicad_pcb]
2023-10-27 Adds component list (WIP)
    [components.xlsx]
2023-10-27 Adds alignment with schema components
    [components.xlsx]
2023-10-27 Fixes component list match (we have perfect match)
    [components.xlsx]
2023-10-27 Adds routines for comparing networks (PCB vs schema)
2023-10-27 Adds missing traces (visual validation)
    [idp-valid.kicad_pcb]
2023-10-27 Validation in progress
    [idp-valid.kicad_pcb]
2023-10-27 Validation and fixing in progress
    [idp-valid.kicad_pcb]
2023-10-27 Validation and fixing (EOD commit)
    [idp-valid.kicad_pcb]
2023-10-27 Validation in progress (after removing the 5V-GND short)
    [idp-valid.kicad_pcb]
2023-10-27 Adjusts pad shapes
    [components.xlsx, idp-valid.kicad_pcb]
2023-10-27 Adds Delta logo
    [idp-valid.kicad_pcb]
2023-10-27 Adds Iskra Delta logo
    [idp-valid.kicad_pcb]
2023-10-27 Fixes logo outline
    [idp-valid.kicad_pcb]
2023-10-27 Some minor silkscreen modifications
    [idp-valid.kicad_pcb]
2023-10-27 Sets Gerber and drill params (for PCBWay)
    [idp-valid.kicad_pcb]
2023-10-27 Adds capacitors C1-C4 & CX
2023-10-27 Updates schema annotations
    [sch_diff_todo.txt]
2023-10-27 Updates BOM
    [components.xlsx]
2023-10-27 Adds more BOM info
    [components.xlsx]
2023-10-27 Extends BOM
    [components.xlsx]
2023-10-27 Updates footprint values Removes footprint "references"
    [idp-valid.kicad_pcb]
2023-10-27 Fixes values
    [idp-valid.kicad_pcb]
2023-10-27 Adds BOM (WIP)
2023-10-27 Adds gerber files
    [idp-valid-B_Cu.gbr, idp-valid-B_Mask.gbr, idp-valid-B_Paste.gbr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]
2023-10-27 Renames folder
    [idp-valid-B_Cu.gbr, idp-valid-B_Mask.gbr, idp-valid-B_Paste.gbr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]
2023-10-27 Adds jumpers and connectors to the list
2023-10-27 Resolves reported DRC issues
    [idp-valid.kicad_pcb]
2023-10-27 Fixes Iskra logo
    [idp-valid.kicad_pcb]
2023-10-27 Renames idp-valid.kicad_* to idp.kicad_*
    [idp.kicad_pcb]
2023-10-27 Adds trimmer values
    [idp.kicad_pcb]
2023-10-27 Updates gerber files
    [idp-B_Cu.gbr, idp-B_Mask.gbr, idp-B_Paste.gbr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]
2024-01-15 Adds Partner Power Distribution Module PCB (initial commit)
    [PartnerPDM.kicad_pcb, PartnerPDM.kicad_sch]
2024-01-15 Adds components
    [PartnerPDM.kicad_pcb]
2024-01-15 Adds power connector
    [PartnerPDM Connector.f3d]
2024-01-15 Updates power connector 3D model (rev 2)
    [PartnerPDM Connector.f3d]
2024-01-15 Updates PCB
    [PartnerPDM.kicad_pcb]
2024-01-29 PDM further dev
    [PartnerPDM.kicad_pcb]
2024-01-30 Adds silkscreen
    [PartnerPDM.kicad_pcb]
2024-01-31 Creates PDM GBR files
    [PartnerPDM-B_Cu.gbr, PartnerPDM-B_Mask.gbr, PartnerPDM-B_Paste.gbr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]
2024-01-31 Adds all connector revisions
    [PartnerPDM Connector Rev1.f3d, PartnerPDM Connector Rev2.f3d, PartnerPDM Connector.f3d]
2024-02-01 Adds PDM connector rev 3
    [PartnerPDM Connector Rev3.f3d]
2026-06-02 Moves footprints
2026-06-02 Compresses PCB images in kicad_pcb
    [idp.kicad_pcb]
2026-06-02 Rmv large files; reorganize
    [components.xlsx, sch_diff_todo.txt]
2026-06-02 Upgrades idp.kicad_* to KiCad 9
    [idp.kicad_pcb]
2026-06-02 Adds "CX" as text, hides references
    [idp.kicad_pcb]
2026-06-02 Assigns refs CX1-CX41 to decoupling caps
    [idp.kicad_pcb]
2026-06-03 Matches CX30 with PCB ref
2026-06-03 Locks PCB scans
    [idp.kicad_pcb]
2026-06-03 Assigns nets to remaining pads
    [idp.kicad_pcb]
